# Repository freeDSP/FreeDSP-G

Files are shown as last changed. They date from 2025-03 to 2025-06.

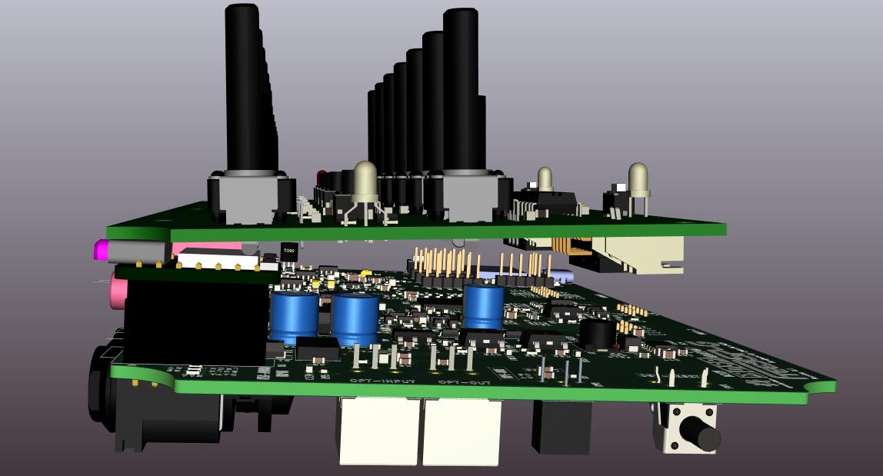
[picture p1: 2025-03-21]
kiCAD/FreeDSP-G_MAIN/Rendering/FreeDSP-G_Stacked_Left.jpg

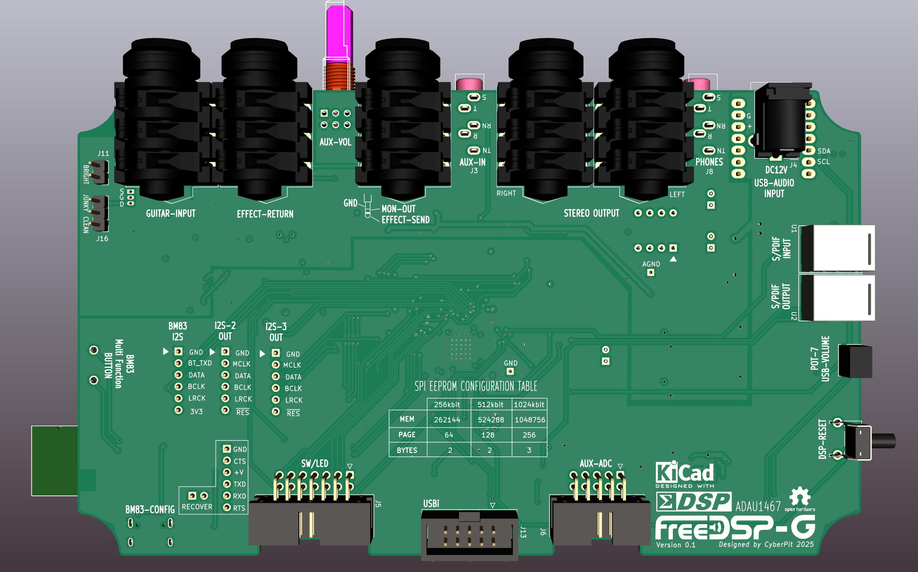
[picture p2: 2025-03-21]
kiCAD/FreeDSP-G_MAIN/Rendering/FreeDSP-G_BottomView.jpg

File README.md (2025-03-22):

# FreeDSP-G (ADAU1467 DSP BOARD)
Strip_PCB

ADAU1467 DSP Board for Electic Guitar Players. The latest version design is 0.2  

## Features  

### Tube Electric Guitar Amplifier Simulator
* A simple single DSP board concept
* 6.5mm Phone Jack I/O connector
* KARAOKE (Play-along) feature
* Effect loop function with plug insert detection feature
* Stereo Output
* Headphones output
* Switchable Dual 7 Potentiometer Controls
* Dual Color LED indicator x1
* Single Color LED x1
* 3 Momentary-ON Footswitches with LED indicator
* Optical S/PDIF Input and Output
* 3.5mm Stereo Analog signal Input with plug insert detection and rotary volume control feature.
* USB-C Audio Input (44.1kHZ/48kHz)
* Embedded BM83 Bluetooth Audio Interface (Option)
* BGM mix level control (POT-7)
* DSP reset button
* Selfboot disable jumper
* Brite(Hi-Boost) Jumper
* Triodizer Head Amplifier with bypass option
* USBi 10P IDC pin-Header with Shoruld

Wiki Page: https://github.com/freeDSP/FreeDSP-G/wiki

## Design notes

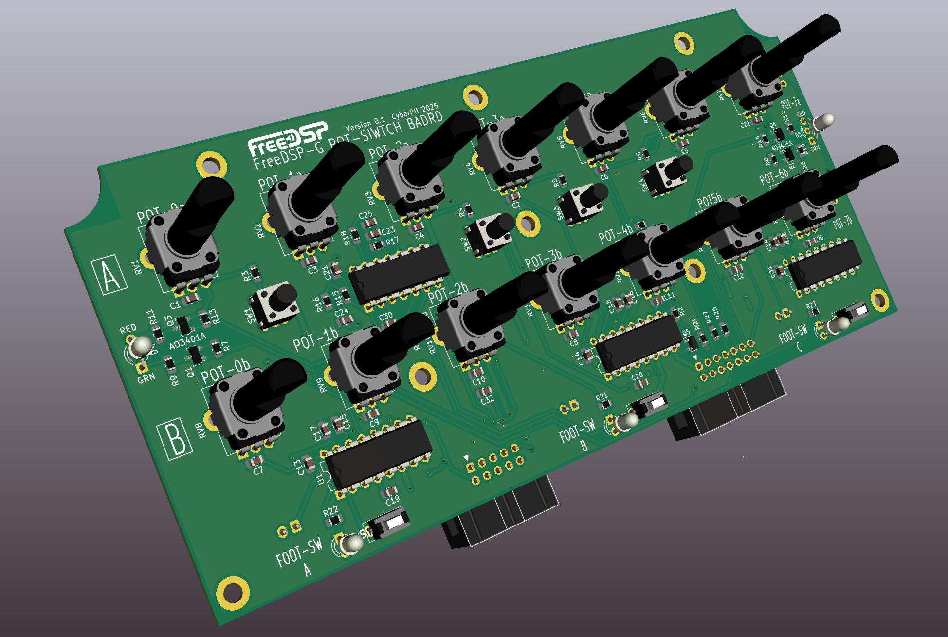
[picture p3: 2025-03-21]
kiCAD/FreeDSP-G_POT-SWITCH/3D-Rendering/POT_SWITCH.jpg

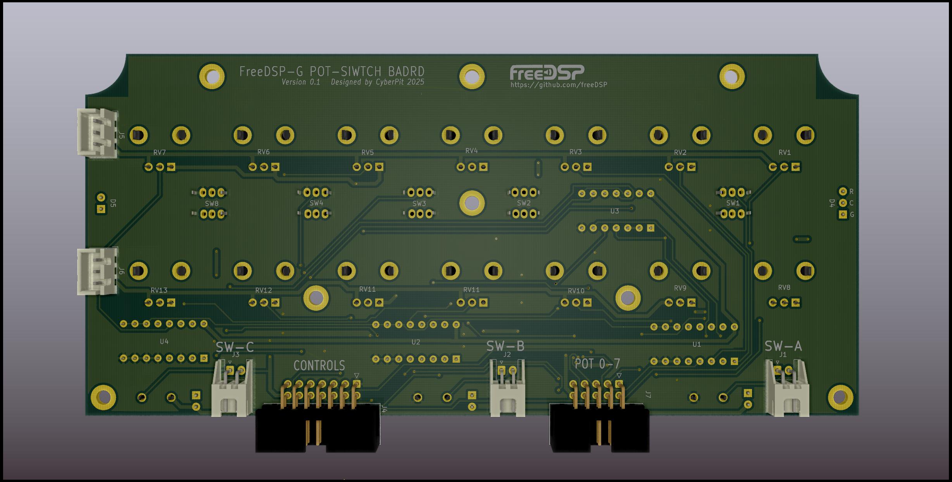
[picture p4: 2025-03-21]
kiCAD/FreeDSP-G_POT-SWITCH/3D-Rendering/POT_SWITCH_BottomView.jpg

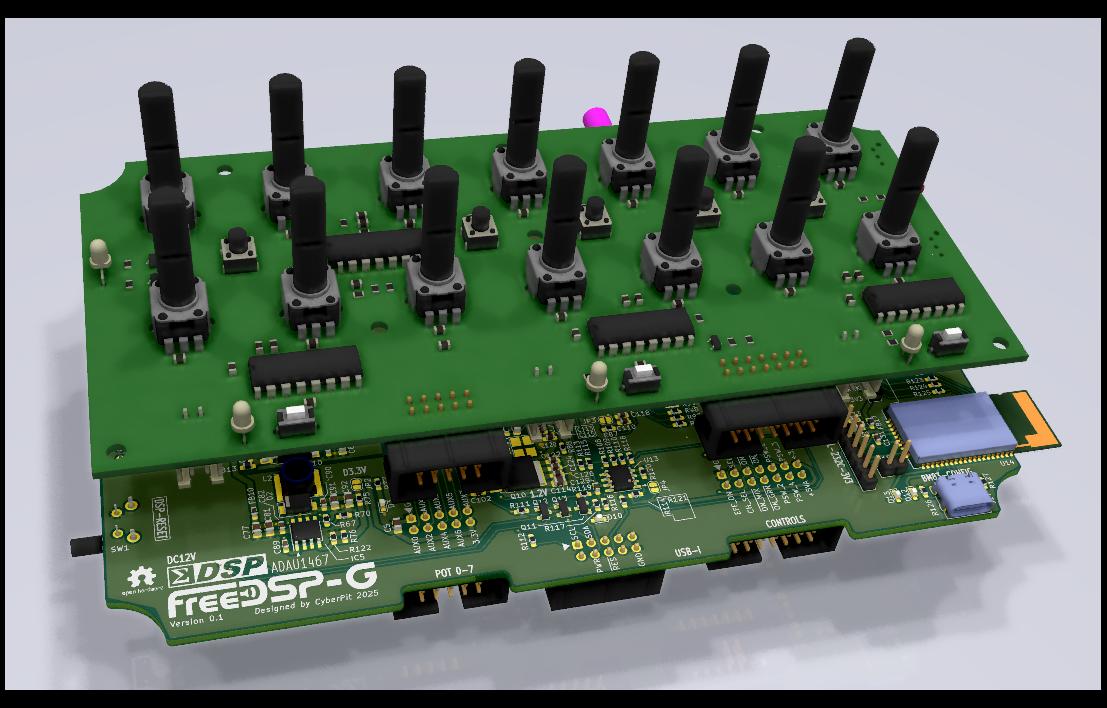
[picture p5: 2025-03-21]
kiCAD/FreeDSP-G_MAIN/Rendering/FreeDSP-G_Stacked_Image.jpg

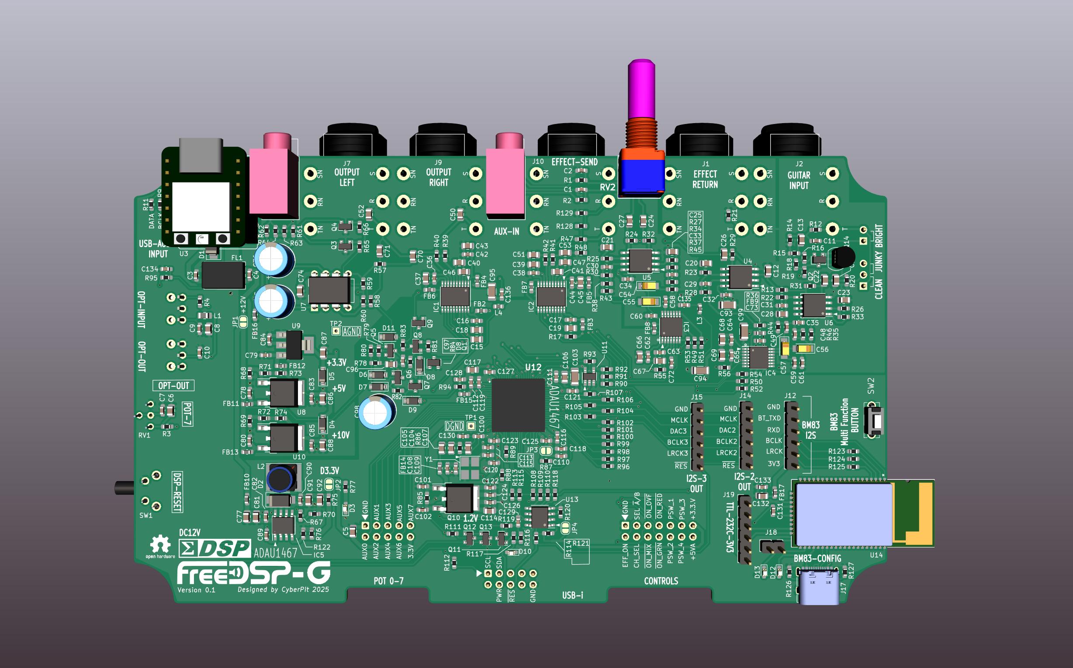
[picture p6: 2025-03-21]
kiCAD/FreeDSP-G_MAIN/Rendering/FreeDSP-G_MainTopView.jpg

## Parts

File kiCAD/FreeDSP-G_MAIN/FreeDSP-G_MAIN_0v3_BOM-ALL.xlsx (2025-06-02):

Reference | Value | Footprint | Description | JLPCB# | Manufacturer_Name | Manufacturer_Part_Number | Datasheet | Supplier_Name | Category | DK_Datasheet_Link | DK_Detail_Page | Digi-Key_PN | Family | MPN | Manufacturer | Status | Height | Allied Price/Stock | Allied_Number | Mouser Part Number | Mouser Price/Stock | RS Part Number | RS Price/Stock
C1 | 100pF_C0G | Capacitor_SMD:C_0603_1608Metric_Pad1.08x0.95mm_HandSolder | C0G or ECHU(FilmCap) Recommended | C14858 |  |  | ~
C10 | 0.1uF | Capacitor_SMD:C_0603_1608Metric_Pad1.08x0.95mm_HandSolder |  | C14663 |  |  | ~
C100 | 0.1uF | Capacitor_SMD:C_0603_1608Metric_Pad1.08x0.95mm_HandSolder |  | C14663 |  |  | ~
C101 | 100pF_C0G | Capacitor_SMD:C_0603_1608Metric_Pad1.08x0.95mm_HandSolder |  | C14858 |  |  | ~
C102 | 0.1uF | Capacitor_SMD:C_0603_1608Metric_Pad1.08x0.95mm_HandSolder |  | C14663 |  |  | ~
C103 | 100uF | Capacitor_SMD:C_1206_3216Metric |  | C15008 |  |  | ~
C104 | 1000pF/250V | Capacitor_SMD:C_0805_2012Metric | C0G PLL Loop FIlter Snabber Cap | C343010 |  |  | ~
C105 | 4700pF | Capacitor_SMD:C_0805_2012Metric | PLL Loop FIlter Cap (C0G will better) | C1744 |  |  | ~
C106 | 10uF | Capacitor_SMD:C_0805_2012Metric |  | C440198 |  |  | ~
C107 | 150pF | Capacitor_SMD:C_0805_2012Metric | PLL Loop FIlter Cap (C0G will better) | C1716 |  |  | ~
C108 | 10nF | Capacitor_SMD:C_0603_1608Metric_Pad1.08x0.95mm_HandSolder |  | C57112 |  |  | ~
C109 | 0.1uF | Capacitor_SMD:C_0603_1608Metric_Pad1.08x0.95mm_HandSolder |  | C14663 |  |  | ~
C11 | 470pF | Capacitor_SMD:C_0603_1608Metric_Pad1.08x0.95mm_HandSolder |  | C1620 |  |  | ~
C110 | 1uF | Capacitor_SMD:C_0603_1608Metric_Pad1.08x0.95mm_HandSolder |  | C15849 |  |  | ~
C111 | 0.1uF | Capacitor_SMD:C_0603_1608Metric_Pad1.08x0.95mm_HandSolder |  | C14663 |  |  | ~
C112 | 1uF | Capacitor_SMD:C_0603_1608Metric_Pad1.08x0.95mm_HandSolder |  | C15849 |  |  | ~
C113 | 0.1uF | Capacitor_SMD:C_0603_1608Metric_Pad1.08x0.95mm_HandSolder |  | C14663 |  |  | ~
C114 | 10uF | Capacitor_SMD:C_0805_2012Metric |  | C440198 |  |  | ~
C115 | 1uF | Capacitor_SMD:C_0603_1608Metric_Pad1.08x0.95mm_HandSolder |  | C15849 |  |  | ~
C116 | 0.1uF | Capacitor_SMD:C_0603_1608Metric_Pad1.08x0.95mm_HandSolder |  | C14663 |  |  | ~
C117 | 10uF | Capacitor_SMD:C_0805_2012Metric |  | C440198 |  |  | ~
C118 | 1uF | Capacitor_SMD:C_0603_1608Metric_Pad1.08x0.95mm_HandSolder |  | C15849
C119 | 0.1uF | Capacitor_SMD:C_0603_1608Metric_Pad1.08x0.95mm_HandSolder |  | C14663 |  |  | ~
C12 | 1uF | Capacitor_SMD:C_0805_2012Metric |  | C28323 |  |  | ~
C120 | 1uF | Capacitor_SMD:C_0603_1608Metric_Pad1.08x0.95mm_HandSolder |  | C15849 |  |  | ~
C121 | 0.1uF | Capacitor_SMD:C_0603_1608Metric_Pad1.08x0.95mm_HandSolder |  | C14663 |  |  | ~
C122 | 1uF | Capacitor_SMD:C_0603_1608Metric_Pad1.08x0.95mm_HandSolder |  | C15849 |  |  | ~
C123 | 0.1uF | Capacitor_SMD:C_0603_1608Metric_Pad1.08x0.95mm_HandSolder |  | C14663 |  |  | ~
C124 | 1uF | Capacitor_SMD:C_0603_1608Metric_Pad1.08x0.95mm_HandSolder |  | C15849 |  |  | ~
C125 | 0.1uF | Capacitor_SMD:C_0603_1608Metric_Pad1.08x0.95mm_HandSolder |  | C14663 |  |  | ~
C126 | 1uF | Capacitor_SMD:C_0603_1608Metric_Pad1.08x0.95mm_HandSolder |  | C15849 |  |  | ~
C127 | 0.1uF | Capacitor_SMD:C_0603_1608Metric_Pad1.08x0.95mm_HandSolder |  | C14663 |  |  | ~
C128 | 0.1uF | Capacitor_SMD:C_0603_1608Metric_Pad1.08x0.95mm_HandSolder |  | C14663
C129 | 0.1uF | Capacitor_SMD:C_0603_1608Metric_Pad1.08x0.95mm_HandSolder |  | C14663 |  |  | ~
C13 | 100nF | Capacitor_SMD:C_0805_2012Metric |  | C28233 |  |  | ~
C130 | 10nF | Capacitor_SMD:C_0603_1608Metric_Pad1.08x0.95mm_HandSolder |  | C57112 |  |  | ~
C131 | 0.1uF | Capacitor_SMD:C_0603_1608Metric_Pad1.08x0.95mm_HandSolder |  | C14663 |  |  | ~
C132 | 10uF | Capacitor_SMD:C_0805_2012Metric |  | C440198 |  |  | ~
C133 | 0.1uF | Capacitor_SMD:C_0603_1608Metric_Pad1.08x0.95mm_HandSolder |  | C14663 |  |  | ~
C134 | 0.1uF | Capacitor_SMD:C_0603_1608Metric_Pad1.08x0.95mm_HandSolder |  | C14663 |  |  | ~
C135 | 0.1uF | Capacitor_SMD:C_0603_1608Metric_Pad1.08x0.95mm_HandSolder |  | C14663 |  |  | ~
C136 | 0.1uF | Capacitor_SMD:C_0603_1608Metric_Pad1.08x0.95mm_HandSolder |  | C14663 |  |  | ~
C137 | 10uF | Capacitor_SMD:C_0805_2012Metric |  | C440198
C138 | 220uF/10V | Capacitor_THT:CP_Radial_D7.5mm_P2.50mm | Low ESR will better for headphones coupling | HAND |  |  | ~
C139 | 470uF/16V | Capacitor_THT:CP_Radial_D10.0mm_P2.50mm_P5.00mm | Low ESR will better for headphones coupling | HAND |  |  | ~
C14 | 10uF/16V | Capacitor_Tantalum_SMD:CP_EIA-2012-12_Kemet-R |  |  |  |  | ~
C15 | 10uF | Capacitor_SMD:C_0805_2012Metric |  | C440198
C16 | 0.1uF | Capacitor_SMD:C_0603_1608Metric_Pad1.08x0.95mm_HandSolder |  | C14663
C17 | 0.1uF | Capacitor_SMD:C_0603_1608Metric_Pad1.08x0.95mm_HandSolder |  | C14663
C18 | 10uF | Capacitor_SMD:C_0805_2012Metric |  | C440198
C19 | 10uF | Capacitor_SMD:C_0805_2012Metric |  | C440198
C2 | 100pF_C0G | Capacitor_SMD:C_0603_1608Metric_Pad1.08x0.95mm_HandSolder | C0G or ECHU(FilmCap) Recommended | C14858 |  |  | ~
C20 | 1uF | Capacitor_SMD:C_0805_2012Metric |  | C28323 |  |  | ~
C21 | 10uF | Capacitor_SMD:C_0805_2012Metric |  | C440198 |  |  | ~
C22 | 1uF | Capacitor_SMD:C_0805_2012Metric |  | C28323 |  |  | ~
C23 | NOP | Capacitor_SMD:C_0805_2012Metric | Not needed | - |  |  | ~
C24 | 1uF | Capacitor_SMD:C_0805_2012Metric |  | C28323 |  |  | ~
C25 | 10uF | Capacitor_SMD:C_0805_2012Metric |  | C440198 |  |  | ~
C26 | 1uF | Capacitor_SMD:C_0805_2012Metric |  | C28323 |  |  | ~
C27 | 1uF | Capacitor_SMD:C_0805_2012Metric |  | C28323 |  |  | ~
C28 | 10uF | Capacitor_SMD:C_0805_2012Metric |  | C440198 |  |  | ~
C29 | 100pF_C0G | Capacitor_SMD:C_0603_1608Metric_Pad1.08x0.95mm_HandSolder |  | C14858 |  |  | ~
C3 | 0.1uF | Capacitor_SMD:C_0603_1608Metric_Pad1.08x0.95mm_HandSolder |  | C14663 |  |  | ~
C30 | 100pF_C0G | Capacitor_SMD:C_0603_1608Metric_Pad1.08x0.95mm_HandSolder |  | C14858 |  |  | ~
C31 | 0.1uF | Capacitor_SMD:C_0603_1608Metric_Pad1.08x0.95mm_HandSolder |  | C14663
C32 | 0.1uF | Capacitor_SMD:C_0603_1608Metric_Pad1.08x0.95mm_HandSolder |  | C14663
C33 | 100pF_C0G | Capacitor_SMD:C_0603_1608Metric_Pad1.08x0.95mm_HandSolder |  | C14858 |  |  | ~
C34 | 0.1uF | Capacitor_SMD:C_0603_1608Metric_Pad1.08x0.95mm_HandSolder |  | C14663
C35 | 0.1uF | Capacitor_SMD:C_0603_1608Metric_Pad1.08x0.95mm_HandSolder |  | C14663
C36 | 0.1uF | Capacitor_SMD:C_0603_1608Metric_Pad1.08x0.95mm_HandSolder |  | C14663
C37 | 10uF | Capacitor_SMD:C_0805_2012Metric |  | C440198
C38 | 0.1uF | Capacitor_SMD:C_0603_1608Metric_Pad1.08x0.95mm_HandSolder |  | C14663
C39 | 10uF | Capacitor_SMD:C_0805_2012Metric |  | C440198
C4 | 0.1uF | Capacitor_SMD:C_0603_1608Metric_Pad1.08x0.95mm_HandSolder |  | C14663 |  |  | ~
C40 | 10uF | Capacitor_SMD:C_0805_2012Metric |  | C440198
C41 | 10uF | Capacitor_SMD:C_0805_2012Metric |  | C440198
C42 | 0.1uF | Capacitor_SMD:C_0603_1608Metric_Pad1.08x0.95mm_HandSolder |  | C14663
C43 | 10uF | Capacitor_SMD:C_0805_2012Metric |  | C440198
C44 | 0.1uF | Capacitor_SMD:C_0603_1608Metric_Pad1.08x0.95mm_HandSolder |  | C14663
C45 | 10uF | Capacitor_SMD:C_0805_2012Metric |  | C440198
C46 | 10uF | Capacitor_SMD:C_0805_2012Metric |  | C440198
C47 | 10uF | Capacitor_SMD:C_0805_2012Metric |  | C440198
C48 | 100pF_C0G | Capacitor_SMD:C_0603_1608Metric_Pad1.08x0.95mm_HandSolder | C0G or ECHU(FilmCap) Recommended | C14858 |  |  | ~
C49 | 100pF_C0G | Capacitor_SMD:C_0603_1608Metric_Pad1.08x0.95mm_HandSolder | C0G or ECHU(FilmCap) Recommended | C14858 |  |  | ~
C5 | 10uF | Capacitor_SMD:C_0805_2012Metric |  | C440198 |  |  | ~
C50 | 1000pF/250V | Capacitor_SMD:C_0805_2012Metric |  | C343010 |  |  | ~
C51 | 1000pF/250V | Capacitor_SMD:C_0805_2012Metric |  | C343010 |  |  | ~
C52 | 1000pF/250V | Capacitor_SMD:C_0805_2012Metric |  | C343010 |  |  | ~
C53 | 1000pF/250V | Capacitor_SMD:C_0805_2012Metric |  | C343010 |  |  | ~
C54 | 10uF/16V(Ta) | Capacitors_Tantalum_SMD:CP_Tantalum_Case-A_EIA-3216-18_Reflow | Tanatalium 3216 metric | C7171
C55 | 10uF/16V(Ta) | Capacitors_Tantalum_SMD:CP_Tantalum_Case-A_EIA-3216-18_Reflow | Tanatalium 3216 metric | C7171
C56 | 10uF/16V(Ta) | Capacitors_Tantalum_SMD:CP_Tantalum_Case-A_EIA-3216-18_Reflow | Tanatalium 3216 metric | C7171
C57 | 10uF/16V(Ta) | Capacitors_Tantalum_SMD:CP_Tantalum_Case-A_EIA-3216-18_Reflow | Tanatalium 3216 metric | C7171
C58 | 100pF_C0G | Capacitor_SMD:C_0603_1608Metric_Pad1.08x0.95mm_HandSolder | C0G or ECHU(FilmCap) Recommended | C14858
C59 | 100pF_C0G | Capacitor_SMD:C_0603_1608Metric_Pad1.08x0.95mm_HandSolder | C0G or ECHU(FilmCap) Recommended | C14858
C6 | 10uF | Capacitor_SMD:C_0805_2012Metric |  | C440198
C60 | 100pF_C0G | Capacitor_SMD:C_0603_1608Metric_Pad1.08x0.95mm_HandSolder | C0G or ECHU(FilmCap) Recommended | C14858
C61 | 100pF_C0G | Capacitor_SMD:C_0603_1608Metric_Pad1.08x0.95mm_HandSolder | C0G or ECHU(FilmCap) Recommended | C14858
C62 | 0.1uF | Capacitor_SMD:C_0603_1608Metric_Pad1.08x0.95mm_HandSolder |  | C14663
C63 | 0.1uF | Capacitor_SMD:C_0603_1608Metric_Pad1.08x0.95mm_HandSolder |  | C14663
C64 | 0.1uF | Capacitor_SMD:C_0603_1608Metric_Pad1.08x0.95mm_HandSolder |  | C14663
C65 | 0.1uF | Capacitor_SMD:C_0603_1608Metric_Pad1.08x0.95mm_HandSolder |  | C14663
C66 | 10uF | Capacitor_SMD:C_0805_2012Metric |  | C440198
C67 | 10uF | Capacitor_SMD:C_0805_2012Metric |  | C440198
C68 | 10uF | Capacitor_SMD:C_0805_2012Metric |  | C440198
C69 | 10uF | Capacitor_SMD:C_0805_2012Metric |  | C440198
C7 | 0.1uF | Capacitor_SMD:C_0603_1608Metric_Pad1.08x0.95mm_HandSolder |  | C14663 |  |  | ~
C70 | 10uF | Capacitor_SMD:C_0805_2012Metric |  | C440198
C71 | 10uF | Capacitor_SMD:C_0805_2012Metric |  | C440198
C72 | 0.1uF | Capacitor_SMD:C_0603_1608Metric_Pad1.08x0.95mm_HandSolder |  | C14663
C73 | 0.1uF | Capacitor_SMD:C_0603_1608Metric_Pad1.08x0.95mm_HandSolder |  | C14663
C74 | 10uF | Capacitor_SMD:C_0805_2012Metric |  | C440198
C75 | 220uF/10V | Capacitor_THT:CP_Radial_D7.5mm_P2.50mm | Low ESR will better for headphones coupling | HAND |  |  | ~
C76 | 220uF/10V | Capacitor_THT:CP_Radial_D7.5mm_P2.50mm | Low ESR will better for headphones coupling | HAND |  |  | ~
C77 | 10uF/50V | Capacitor_SMD:C_0805_2012Metric |  | C440198 |  |  | ~
C78 | 0.1uF | Capacitor_SMD:C_0603_1608Metric_Pad1.08x0.95mm_HandSolder |  | C14663 |  |  | ~
C79 | 0.1uF | Capacitor_SMD:C_0603_1608Metric_Pad1.08x0.95mm_HandSolder |  | C14663 |  |  | ~
C8 | 10uF | Capacitor_SMD:C_0805_2012Metric |  | C440198 |  |  | ~
C80 | 0.1uF | Capacitor_SMD:C_0603_1608Metric_Pad1.08x0.95mm_HandSolder |  | C14663 |  |  | ~
C81 | 1uF/50V | Capacitor_SMD:C_0805_2012Metric |  | C28323 |  |  | ~
C82 | 0.1uF | Capacitor_SMD:C_0603_1608Metric_Pad1.08x0.95mm_HandSolder |  | C14663 |  |  | ~
C83 | 0.1uF | Capacitor_SMD:C_0603_1608Metric_Pad1.08x0.95mm_HandSolder |  | C14663 |  |  | ~
C84 | 0.1uF | Capacitor_SMD:C_0603_1608Metric_Pad1.08x0.95mm_HandSolder |  | C14663 |  |  | ~
C85 | 0.1uF | Capacitor_SMD:C_0603_1608Metric_Pad1.08x0.95mm_HandSolder |  | C14663 |  |  | ~
C86 | 1uF | Capacitor_SMD:C_0805_2012Metric |  | C28323 |  |  | ~
C87 | 1uF | Capacitor_SMD:C_0805_2012Metric |  | C28323 |  |  | ~
C88 | 1uF | Capacitor_SMD:C_0805_2012Metric |  | C28323 |  |  | ~
C89 | 0.1uF | Capacitor_SMD:C_0603_1608Metric_Pad1.08x0.95mm_HandSolder |  | C14663 |  |  | ~
C9 | 0.1uF | Capacitor_SMD:C_0603_1608Metric_Pad1.08x0.95mm_HandSolder |  | C14663 |  |  | ~
C90 | 0.1uF | Capacitor_SMD:C_0603_1608Metric_Pad1.08x0.95mm_HandSolder |  | C14663 |  |  | ~
C91 | 47uF/6.3V | Capacitor_SMD:C_0805_2012Metric | for Negative SMPS Power Integration | C16780 |  |  | ~
C92 | 47uF/6.3V | Capacitor_SMD:C_0805_2012Metric |  | C16780 |  |  | ~
C93 | 47uF/10V | Capacitor_SMD:C_1206_3216Metric |  | C96123 |  |  | ~
C94 | 100uF/6.3V | Capacitor_SMD:C_1206_3216Metric |  | C15008 |  |  | ~
C95 | 100uF/6.3V | Capacitor_SMD:C_1206_3216Metric |  | C15008 |  |  | ~
C96 | 10uF/50V | Capacitor_SMD:C_0805_2012Metric | for the Power-ON delay timing | C440198 |  |  | ~
C97 | 0.1uF | Capacitor_SMD:C_0603_1608Metric_Pad1.08x0.95mm_HandSolder |  | C14663 |  |  | ~
C98 | 220uF/16V | Capacitor_THT:CP_Radial_D7.5mm_P2.50mm | for the Power-OFF muting power reserver | HAND |  |  | ~
C99 | 100uF | Capacitor_SMD:C_1206_3216Metric |  | C15008 |  |  | ~
D1 | D_Schottky_5A | Diode_SMD:D_SMA | SBD 40V 550mV@5A | C22452 |  |  | ~
D10 | LED_YELLOW | LED_SMD:LED_0603_1608Metric_Castellated | Indicator for USBi is Active | C72038
D11 | B5819W SL | Diode_SMD:D_SOD-123 | SBD 1A/40V | C8598 |  |  | http://www.vishay.com/docs/85660/bat42.pdf
D12 | LED_WHITE | LED_SMD:LED_0603_1608Metric_Castellated | Remove this if you use LED extension header | C2290
D13 | LED_RED | LED_SMD:LED_0603_1608Metric_Castellated | Remove this if you use LED extension header | C2286
D14 | B5819W SL | Diode_SMD:D_SOD-123 | SBD 1A/40V | C8598 |  |  | http://www.vishay.com/docs/85660/bat42.pdf
D15 | B5819W SL | Diode_SMD:D_SOD-123 | SBD 1A/40V | C8598 |  |  | http://www.vishay.com/docs/85660/bat42.pdf
D2 | D_Schottky_5A | Diode_SMD:D_SMA | SBD 40V 550mV@5A | C22452 |  |  | ~
D3 | LED_WHITE | LED_SMD:LED_0603_1608Metric_Castellated | Remove this if you use LED extension header | C2290
D4 | B5819W SL | Diode_SMD:D_SOD-123 | SBD 1A/40V | C8598 |  |  | http://www.vishay.com/docs/85660/bat42.pdf
D5 | B5819W SL | Diode_SMD:D_SOD-123 | SBD 1A/40V | C8598 |  |  | http://www.vishay.com/docs/85660/bat42.pdf
D6 | 1N4148W | Diode_SMD:D_SOD-123 | Switching Diode 150mA/75V | C81598 |  |  | ~
D7 | B5819W SL | Diode_SMD:D_SOD-123 | SBD 1A/40V | C8598 |  |  | http://www.vishay.com/docs/85660/bat42.pdf
D8 | B5819W SL | Diode_SMD:D_SOD-123 | SBD 1A/40V | C8598 |  |  | http://www.vishay.com/docs/85660/bat42.pdf
D9 | B5819W SL | Diode_SMD:D_SOD-123 | SBD 1A/40V | C8598 |  |  | http://www.vishay.com/docs/85660/bat42.pdf
FB1 | GZ1608D601TF | Inductor_SMD:L_0603_1608Metric_Pad1.05x0.95mm_HandSolder | FERRITE BEAD 600 OHM 0603 1LN | C1002 |  |  | https://www.murata.com/en-us/products/productdata/8796738650142/ENFA0003.pdf |  | Filters | https://www.murata.com/en-us/products/productdata/8796738650142/ENFA0003.pdf | /product-detail/en/murata-electronics-north-america/BLM18AG601SN1D/490-1014-1-ND/584462 | 490-1014-1-ND | Ferrite Beads and Chips | BLM18AG601SN1D | Murata Electronics North America | Active
FB10 | GZ1608D601TF | Inductor_SMD:L_0603_1608Metric_Pad1.05x0.95mm_HandSolder | FERRITE BEAD 600 OHM 0603 1LN | C1002 |  |  | https://www.murata.com/en-us/products/productdata/8796738650142/ENFA0003.pdf |  | Filters | https://www.murata.com/en-us/products/productdata/8796738650142/ENFA0003.pdf | /product-detail/en/murata-electronics-north-america/BLM18AG601SN1D/490-1014-1-ND/584462 | 490-1014-1-ND | Ferrite Beads and Chips | BLM18AG601SN1D | Murata Electronics North America | Active
FB11 | GZ1608D601TF | Inductor_SMD:L_0603_1608Metric_Pad1.05x0.95mm_HandSolder | FERRITE BEAD 600 OHM 0603 1LN | C1002 |  |  | https://www.murata.com/en-us/products/productdata/8796738650142/ENFA0003.pdf |  | Filters | https://www.murata.com/en-us/products/productdata/8796738650142/ENFA0003.pdf | /product-detail/en/murata-electronics-north-america/BLM18AG601SN1D/490-1014-1-ND/584462 | 490-1014-1-ND | Ferrite Beads and Chips | BLM18AG601SN1D | Murata Electronics North America | Active
FB12 | GZ1608D601TF | Inductor_SMD:L_0603_1608Metric_Pad1.05x0.95mm_HandSolder | FERRITE BEAD 600 OHM 0603 1LN | C1002 |  |  | https://www.murata.com/en-us/products/productdata/8796738650142/ENFA0003.pdf |  | Filters | https://www.murata.com/en-us/products/productdata/8796738650142/ENFA0003.pdf | /product-detail/en/murata-electronics-north-america/BLM18AG601SN1D/490-1014-1-ND/584462 | 490-1014-1-ND | Ferrite Beads and Chips | BLM18AG601SN1D | Murata Electronics North America | Active
FB13 | GZ1608D601TF | Inductor_SMD:L_0603_1608Metric_Pad1.05x0.95mm_HandSolder | FERRITE BEAD 600 OHM 0603 1LN | C1002 |  |  | https://www.murata.com/en-us/products/productdata/8796738650142/ENFA0003.pdf |  | Filters | https://www.murata.com/en-us/products/productdata/8796738650142/ENFA0003.pdf | /product-detail/en/murata-electronics-north-america/BLM18AG601SN1D/490-1014-1-ND/584462 | 490-1014-1-ND | Ferrite Beads and Chips | BLM18AG601SN1D | Murata Electronics North America | Active
FB14 | GZ1608D601TF | Inductor_SMD:L_0603_1608Metric_Pad1.05x0.95mm_HandSolder | FERRITE BEAD 600 OHM 0603 1LN | C1002 |  |  | https://www.murata.com/en-us/products/productdata/8796738650142/ENFA0003.pdf |  | Filters | https://www.murata.com/en-us/products/productdata/8796738650142/ENFA0003.pdf | /product-detail/en/murata-electronics-north-america/BLM18AG601SN1D/490-1014-1-ND/584462 | 490-1014-1-ND | Ferrite Beads and Chips | BLM18AG601SN1D | Murata Electronics North America | Active
FB15 | GZ1608D601TF | Inductor_SMD:L_0603_1608Metric_Pad1.05x0.95mm_HandSolder | FERRITE BEAD 600 OHM 0603 1LN | C1002 |  |  | https://www.murata.com/en-us/products/productdata/8796738650142/ENFA0003.pdf |  | Filters | https://www.murata.com/en-us/products/productdata/8796738650142/ENFA0003.pdf | /product-detail/en/murata-electronics-north-america/BLM18AG601SN1D/490-1014-1-ND/584462 | 490-1014-1-ND | Ferrite Beads and Chips | BLM18AG601SN1D | Murata Electronics North America | Active
FB16 | GZ1608D601TF | Inductor_SMD:L_0603_1608Metric_Pad1.05x0.95mm_HandSolder | FERRITE BEAD 600 OHM 0603 1LN | C1002 |  |  | https://www.murata.com/en-us/products/productdata/8796738977822/ENFA0005.pdf |  | Filters | https://www.murata.com/en-us/products/productdata/8796738977822/ENFA0005.pdf | /product-detail/en/murata-electronics-north-america/BLM21PG331SN1D/490-5988-1-ND/3845188 | 490-5988-1-ND | Ferrite Beads and Chips | BLM21PG331SN1D | Murata Electronics North America | Active
FB17 | GZ1608D601TF | Inductor_SMD:L_0603_1608Metric_Pad1.05x0.95mm_HandSolder | FERRITE BEAD 600 OHM 0603 1LN | C1002 |  |  | https://www.murata.com/en-us/products/productdata/8796738650142/ENFA0003.pdf |  | Filters | https://www.murata.com/en-us/products/productdata/8796738650142/ENFA0003.pdf | /product-detail/en/murata-electronics-north-america/BLM18AG601SN1D/490-1014-1-ND/584462 | 490-1014-1-ND | Ferrite Beads and Chips | BLM18AG601SN1D | Murata Electronics North America | Active
FB18 | GZ1608D601TF | Inductor_SMD:L_0603_1608Metric_Pad1.05x0.95mm_HandSolder | FERRITE BEAD 600 OHM 0603 1LN | C1002 |  |  | https://www.murata.com/en-us/products/productdata/8796738650142/ENFA0003.pdf |  | Filters | https://www.murata.com/en-us/products/productdata/8796738650142/ENFA0003.pdf | /product-detail/en/murata-electronics-north-america/BLM18AG601SN1D/490-1014-1-ND/584462 | 490-1014-1-ND | Ferrite Beads and Chips | BLM18AG601SN1D | Murata Electronics North America | Active
FB2 | GZ1608D601TF | Inductor_SMD:L_0603_1608Metric_Pad1.05x0.95mm_HandSolder | FERRITE BEAD 600 OHM 0603 1LN | C1002 |  |  | https://www.murata.com/en-us/products/productdata/8796738650142/ENFA0003.pdf |  | Filters | https://www.murata.com/en-us/products/productdata/8796738650142/ENFA0003.pdf | /product-detail/en/murata-electronics-north-america/BLM18AG601SN1D/490-1014-1-ND/584462 | 490-1014-1-ND | Ferrite Beads and Chips | BLM18AG601SN1D | Murata Electronics North America | Active
FB3 | GZ1608D601TF | Inductor_SMD:L_0603_1608Metric_Pad1.05x0.95mm_HandSolder | FERRITE BEAD 600 OHM 0603 1LN | C1002 |  |  | https://www.murata.com/en-us/products/productdata/8796738650142/ENFA0003.pdf |  | Filters | https://www.murata.com/en-us/products/productdata/8796738650142/ENFA0003.pdf | /product-detail/en/murata-electronics-north-america/BLM18AG601SN1D/490-1014-1-ND/584462 | 490-1014-1-ND | Ferrite Beads and Chips | BLM18AG601SN1D | Murata Electronics North America | Active
FB4 | GZ1608D601TF | Inductor_SMD:L_0603_1608Metric_Pad1.05x0.95mm_HandSolder | FERRITE BEAD 600 OHM 0603 1LN | C1002 |  |  | https://www.murata.com/en-us/products/productdata/8796738650142/ENFA0003.pdf |  | Filters | https://www.murata.com/en-us/products/productdata/8796738650142/ENFA0003.pdf | /product-detail/en/murata-electronics-north-america/BLM18AG601SN1D/490-1014-1-ND/584462 | 490-1014-1-ND | Ferrite Beads and Chips | BLM18AG601SN1D | Murata Electronics North America | Active
FB5 | GZ1608D601TF | Inductor_SMD:L_0603_1608Metric_Pad1.05x0.95mm_HandSolder | FERRITE BEAD 600 OHM 0603 1LN | C1002 |  |  | https://www.murata.com/en-us/products/productdata/8796738650142/ENFA0003.pdf |  | Filters | https://www.murata.com/en-us/products/productdata/8796738650142/ENFA0003.pdf | /product-detail/en/murata-electronics-north-america/BLM18AG601SN1D/490-1014-1-ND/584462 | 490-1014-1-ND | Ferrite Beads and Chips | BLM18AG601SN1D | Murata Electronics North America | Active
FB6 | GZ1608D601TF | Inductor_SMD:L_0603_1608Metric_Pad1.05x0.95mm_HandSolder | FERRITE BEAD 600 OHM 0603 1LN | C1002 |  |  | https://www.murata.com/en-us/products/productdata/8796738977822/ENFA0005.pdf |  | Filters | https://www.murata.com/en-us/products/productdata/8796738977822/ENFA0005.pdf | /product-detail/en/murata-electronics-north-america/BLM21PG331SN1D/490-5988-1-ND/3845188 | 490-5988-1-ND | Ferrite Beads and Chips | BLM21PG331SN1D | Murata Electronics North America | Active
FB7 | GZ1608D601TF | Inductor_SMD:L_0603_1608Metric_Pad1.05x0.95mm_HandSolder | FERRITE BEAD 600 OHM 0603 1LN | C1002 |  |  | https://www.murata.com/en-us/products/productdata/8796738977822/ENFA0005.pdf |  | Filters | https://www.murata.com/en-us/products/productdata/8796738977822/ENFA0005.pdf | /product-detail/en/murata-electronics-north-america/BLM21PG331SN1D/490-5988-1-ND/3845188 | 490-5988-1-ND | Ferrite Beads and Chips | BLM21PG331SN1D | Murata Electronics North America | Active
FB8 | GZ1608D601TF | Inductor_SMD:L_0603_1608Metric_Pad1.05x0.95mm_HandSolder | FERRITE BEAD 600 OHM 0603 1LN | C1002 |  |  | https://www.murata.com/en-us/products/productdata/8796738977822/ENFA0005.pdf |  | Filters | https://www.murata.com/en-us/products/productdata/8796738977822/ENFA0005.pdf | /product-detail/en/murata-electronics-north-america/BLM21PG331SN1D/490-5988-1-ND/3845188 | 490-5988-1-ND | Ferrite Beads and Chips | BLM21PG331SN1D | Murata Electronics North America | Active
FB9 | GZ1608D601TF | Inductor_SMD:L_0603_1608Metric_Pad1.05x0.95mm_HandSolder | FERRITE BEAD 600 OHM 0603 1LN | C1002 |  |  | https://www.murata.com/en-us/products/productdata/8796738977822/ENFA0005.pdf |  | Filters | https://www.murata.com/en-us/products/productdata/8796738977822/ENFA0005.pdf | /product-detail/en/murata-electronics-north-america/BLM21PG331SN1D/490-5988-1-ND/3845188 | 490-5988-1-ND | Ferrite Beads and Chips | BLM21PG331SN1D | Murata Electronics North America | Active
FL1 | MACM9070-701 | Myfootprints:ACM9070 | TDK - ACM9070-701-2PL-TL01 - FILTER, COMMON MODE, 5A, SMD | C2981417 | TDK | ACM9070-701-2PL-TL01 | http://www.mouser.com/ds/2/400/e9713_acm-16715.pdf | RS
IC1 | PCM5102APWR | Package_SO:TSSOP-20_4.4x6.5mm_P0.65mm | 2VRMS, 112dB Stereo DAC with 32-bit, 384kHz I2S Interface | C107671 | Texas Instruments | PCM5102APWR | https://componentsearchengine.com/Datasheets/2/PCM5102APWR.pdf | RS |  |  |  |  |  |  |  |  | 1.2
IC2 | PCM5102APWR | Package_SO:TSSOP-20_4.4x6.5mm_P0.65mm | 2VRMS, 112dB Stereo DAC with 32-bit, 384kHz I2S Interface | C107671 | Texas Instruments | PCM5102APWR | https://componentsearchengine.com/Datasheets/2/PCM5102APWR.pdf | RS |  |  |  |  |  |  |  |  | 1.2
IC3 | PCM1808QPWR | Myfootprints:PCM1808QPWRQ1 | ADC 99dB SNR @48kHz Sampling | C55513 | Texas Instruments | PCM1808QPWRQ1 | http://www.ti.com/lit/ds/symlink/pcm1808-q1.pdf | RS |  |  |  |  |  |  |  |  | 1.2
IC4 | PCM1808QPWR | Myfootprints:PCM1808QPWRQ1 | ADC 99dB SNR @48kHz Sampling | C55513 | Texas Instruments | PCM1808QPWRQ1 | http://www.ti.com/lit/ds/symlink/pcm1808-q1.pdf | RS |  |  |  |  |  |  |  |  | 1.2
IC5 | TPS5430DDA | Package_SO:TI_SO-PowerPAD-8_ThermalVias | SMPS for digital part | C9864 |  |  | http://www.ti.com/lit/ds/symlink/tps5430.pdf
J1 | NMJ6HCD2 | MyJacks:PJ-644C_NMJ6HCD2_ACJS-IH | 6,5mm TRS Jack with SW | HAND |  |  | ~
J10 | NMJ6HCD2 | MyJacks:PJ-644C_NMJ6HCD2_ACJS-IH | 6,5mm TRS Jack with SW | HAND |  |  | ~
J11 | Header_2P | Connector_PinHeader_2.54mm:PinHeader_1x02_P2.54mm_Vertical | Jumper pin-post 2P | HAND |  |  | ~
J12 | Conn_01x08 | Connector_PinHeader_2.54mm:PinHeader_1x06_P2.54mm_Vertical | for Optinal Extension of POTs | NOP |  |  | ~
J13 | IDC_2x5 | Connector_IDC:IDC-Header_2x05_P2.54mm_Vertical | Angled 10pin IDC header for USBi | HAND
J14 | Conn_01x08 | Connector_PinHeader_2.54mm:PinHeader_1x06_P2.54mm_Vertical | for Optinal Extension of POTs | NOP |  |  | ~
J15 | Conn_01x08 | Connector_PinHeader_2.54mm:PinHeader_1x06_P2.54mm_Vertical | for Optinal Extension of POTs | NOP |  |  | ~
J16 | Header_3P | Connector_PinHeader_2.54mm:PinHeader_1x03_P2.54mm_Vertical | Jumper pin-post 2P | HAND |  |  | ~
J17 | 5077CR-16-SMC2 | MyJacks:USB-C_5077CR-16-SMC2-BK-TR |  | HAND |  |  | https://www.usb.org/sites/default/files/documents/usb_type-c.zip
J18 | Header_2P | Connector_PinHeader_2.54mm:PinHeader_1x02_P2.54mm_Vertical |  | HAND |  |  | ~
J19 | Header_6P | Connector_PinHeader_2.54mm:PinHeader_1x06_P2.54mm_Vertical |  | HAND |  |  | ~
J2 | NMJ6HCD2 | MyJacks:PJ-644C_NMJ6HCD2_ACJS-IH | 6,5mm TRS Jack with SW | HAND |  |  | ~
J3 | TRS-mini | Connector_Audio:Jack_3.5mm_CUI_SJ1-3535NG_Horizontal | CUI SJ1-3535NG or MARUSHIN MJ354WSG | HAND |  |  | ~
J4 | Barrel_Jack_Switch | Connector_BarrelJack:BarrelJack_CUI_PJ-102AH_Horizontal | CUI PJ-102AH Center 2.1mm Sleeve 5.5mm | HAND |  |  | ~
J5 | Conn_02x07_Odd_Even | Connector_IDC:IDC-Header_2x07_P2.54mm_Horizontal | Angle IDC 2x7 Header with SH | HAND |  |  | ~
J6 | Conn_02x05_Odd_Even | Connector_IDC:IDC-Header_2x05_P2.54mm_Horizontal | Angle IDC 2x5 Header with SH | HAND |  |  | ~
J7 | NMJ6HCD2 | MyJacks:PJ-644C_NMJ6HCD2_ACJS-IH | 6,5mm TRS Jack with SW | HAND |  |  | ~
J8 | SJ1-3535NG | Connector_Audio:Jack_3.5mm_CUI_SJ1-3535NG_Horizontal | 3,5mm TRS Jack with SW | HAND |  |  | ~
J9 | NMJ6HCD2 | MyJacks:PJ-644C_NMJ6HCD2_ACJS-IH | 6,5mm TRS Jack with SW | HAND |  |  | ~
JP1 | SolderJumper_3_Bridged12 | Jumper:SolderJumper-2_P1.3mm_Bridged_RoundedPad1.0x1.5mm |  | - |  |  | ~
JP2 | SolderJumper_3_Bridged12 | Jumper:SolderJumper-2_P1.3mm_Bridged_RoundedPad1.0x1.5mm |  | - |  |  | ~
JP3 | Jumper_NO | Connector_PinHeader_2.54mm:PinHeader_1x02_P2.54mm_Vertical | Prevent Selfboot if shorted | - |  |  | ~
JP4 | Jumper_NC | Jumper:SolderJumper-2_P1.3mm_Bridged_RoundedPad1.0x1.5mm | Cut for 96kHz A/D Convertion | - |  |  | ~
L1 | SDFL2012S100KTF | Inductor_SMD:L_0805_2012Metric_Pad1.15x1.40mm_HandSolder | FIXED IND 10uH 15MA 1.15 OHM | C1046 |  |  | https://www.murata-ps.com/data/magnetics/kmp_8200c.pdf |  | Inductors, Coils, Chokes | https://www.murata-ps.com/data/magnetics/kmp_8200c.pdf | /product-detail/en/murata-power-solutions-inc/82473C/811-2477-1-ND/3178548 | 811-2477-1-ND | Fixed Inductors | 82473C | Sunlord | Active
L2 | 22uH(2.5A) | Inductor_SMD:L_Taiyo-Yuden_NR-60xx_HandSoldering | Metal-Alloy Power Inductor Rated 2.5A 7x6.6mm | C177244
L3 | SMD-INDUCTOR-10UH-0603 | Inductor_SMD:L_0603_1608Metric | 10uH SMD 0603 Inductor | C1035 |  |  |  |  |  |  |  |  |  | SDFL1608S100KTF
L4 | SMD-INDUCTOR-10UH-0603 | Inductor_SMD:L_0603_1608Metric | 10uH SMD 0603 Inductor | C1035 |  |  |  |  |  |  |  |  |  | SDFL1608S100KTF
LOGO1 | Logo_Open_Hardware_Small | LogoLibrary:LOGO_FREEDSP_600dpi |  | - |  |  | ~
Q1 | AO3400A | TO_SOT_Packages_SMD:SOT-23 | N Ch MOSFET | C20917 |  |  | https://www.fairchildsemi.com/datasheets/2N/2N7002.pdf
Q10 | B772M | Package_TO_SOT_SMD:TO-252-2 | PNP 1.25W 3A Transistor for 1.2V Power Rail | C33027 |  |  | ~
Q11 | AO3401A | Package_TO_SOT_SMD:SOT-23 | P-CHANNEL ENHANCEMENT MODE MOSFET | C15127 | Diodes Inc. | DMG3415U-7 | http://docs-emea.rs-online.com/webdocs/104e/0900766b8104e4f0.pdf |  |  |  |  |  |  |  |  |  | 1 | http://www.alliedelec.com/diodes-inc-dmg3415u-7/70438036/ | 70438036 | 621-DMG3415U-7 | https://www.mouser.com/Search/Refine.aspx?Keyword=621-DMG3415U-7 | 7514095P | http://uk.rs-online.com/web/p/products/7514095P
Q12 | AO3400A | Package_TO_SOT_SMD:SOT-23 | MOSFET N-CH 60V 115MA SOT-23 | C20917 |  |  | https://www.fairchildsemi.com/datasheets/2N/2N7002.pdf
Q13 | AO3400A | Package_TO_SOT_SMD:SOT-23 | MOSFET N-CH 60V 115MA SOT-23 | C20917 |  |  | https://www.fairchildsemi.com/datasheets/2N/2N7002.pdf
Q14 | 2SK30A-GR | TO_SOT_Packages_THT:TO-92_Inline_Narrow_Oval | Replace of 2SK30A | C2999170 |  |  | ~
Q2 | 2SK208GR | TO_SOT_Packages_SMD:SC-59 | Replace of 2SK30A | C2999170 |  |  | ~
Q3 | 2SD2704KT146 | Package_TO_SOT_SMD:SOT-23 | NPN Transistor for anti-pop muting | C79973 |  |  | ~
Q4 | 2SD2704KT146 | Package_TO_SOT_SMD:SOT-23 | NPN Transistor for anti-pop muting | C79973 |  |  | ~
Q5 | MMBT5401 | Package_TO_SOT_SMD:SOT-23 | PNP Transistor 350mW | C8326 |  |  | ~
Q6 | MMBT5401 | Package_TO_SOT_SMD:SOT-23 | PNP Transistor 350mW | C8326 |  |  | ~
Q8 | AO3401A | Package_TO_SOT_SMD:SOT-23 | P-CHANNEL ENHANCEMENT MODE MOSFET | C15127 | Diodes Inc. | DMG3415U-7 | http://docs-emea.rs-online.com/webdocs/104e/0900766b8104e4f0.pdf |  |  |  |  |  |  |  |  |  | 1 | http://www.alliedelec.com/diodes-inc-dmg3415u-7/70438036/ | 70438036 | 621-DMG3415U-7 | https://www.mouser.com/Search/Refine.aspx?Keyword=621-DMG3415U-7 | 7514095P | http://uk.rs-online.com/web/p/products/7514095P
Q9 | AO3400A | Package_TO_SOT_SMD:SOT-23 | MOSFET N-CH 60V 115MA SOT-23 | C20917 |  |  | https://www.onsemi.com/pub/Collateral/NDS7002A-D.PDF |  | Discrete Semiconductor Products | https://www.onsemi.com/pub/Collateral/NDS7002A-D.PDF | /product-detail/en/on-semiconductor/2N7002/2N7002NCT-ND/244664 | 2N7002NCT-ND | Transistors - FETs, MOSFETs - Single | 2N7002 | ON Semiconductor | Active
R1 | 18k | Resistor_SMD:R_0603_1608Metric_Pad0.98x0.95mm_HandSolder |  | C25810
R10 | 1.8k | Resistor_SMD:R_0603_1608Metric_Pad0.98x0.95mm_HandSolder |  | C4177 |  |  | ~
R100 | 33R | Resistor_SMD:R_0603_1608Metric_Pad0.98x0.95mm_HandSolder |  | C23140 |  |  | ~
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

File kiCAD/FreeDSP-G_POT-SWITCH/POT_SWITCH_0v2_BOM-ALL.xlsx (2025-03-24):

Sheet: ALL
REF | VALUE | FOOTPRINT | JLCPCB# | QTY
J5 | NOP | Connector_JST:JST_XH_B3B-XH-A_1x03_P2.50mm_Vertical | NOP | 1
J6 | NOP | Connector_JST:JST_XH_B3B-XH-A_1x03_P2.50mm_Vertical | NOP | 1
R2 | NOP | Resistor_SMD:R_0805_2012Metric_Pad1.20x1.40mm_HandSolder | NOP | 1
SW5 | SW_NOP | Myfootprints:MJTP1250 | NOP | 1
SW6 | SW_NOP | Myfootprints:MJTP1250 | NOP | 1
SW7 | SW_NOP | Myfootprints:MJTP1250 | NOP | 1
D1 | LED | LED_THT:LED_D3.0mm_Clear | HAND | 1
D2 | LED | LED_THT:LED_D3.0mm_Clear | HAND | 1
D3 | LED | LED_THT:LED_D3.0mm_Clear | HAND | 1
D4 | LED_RED-GRN | LED_THT:LED_D3.0mm-3 | HAND | 1
D5 | LED_YELLOW | LED_THT:LED_D3.0mm | HAND | 1
J1 | JST_S2B-XH | Connector_JST:JST_XH_S2B-XH-A_1x02_P2.50mm_Horizontal | HAND | 1
J2 | JST_S2B-XH | Connector_JST:JST_XH_S2B-XH-A_1x02_P2.50mm_Horizontal | HAND | 1
J3 | JST_S2B-XH | Connector_JST:JST_XH_S2B-XH-A_1x02_P2.50mm_Horizontal | HAND | 1
J4 | Conn_02x07_Odd_Even | Connector_IDC:IDC-Header_2x07_P2.54mm_Horizontal | HAND | 1
J7 | Conn_02x05_Odd_Even | Connector_IDC:IDC-Header_2x05_P2.54mm_Horizontal | HAND | 1
RV1 | B10K | Myfootprints:Alps_RK09K113 | HAND | 1
RV2 | B10K | Myfootprints:Alps_RK09K113 | HAND | 1
RV3 | B10K | Myfootprints:Alps_RK09K113 | HAND | 1
RV4 | B10K | Myfootprints:Alps_RK09K113 | HAND | 1
RV5 | B10K | Myfootprints:Alps_RK09K113 | HAND | 1
RV6 | B10K | Myfootprints:Alps_RK09K113 | HAND | 1
RV7 | B10K | Myfootprints:Alps_RK09K113 | HAND | 1
RV8 | B10K | Myfootprints:Alps_RK09K113 | HAND | 1
RV9 | B10K | Myfootprints:Alps_RK09K113 | HAND | 1
RV10 | B10K | Myfootprints:Alps_RK09K113 | HAND | 1
RV11 | B10K | Myfootprints:Alps_RK09K113 | HAND | 1
RV12 | B10K | Myfootprints:Alps_RK09K113 | HAND | 1
RV13 | B10K | Myfootprints:Alps_RK09K113 | HAND | 1
RV14 | B10K | Myfootprints:Alps_RK09K113 | HAND | 1
SW1 | PUSH-SWITCH-2mm-DPDT | Myfootprints:PUSHSW_DPDT_6-7mm | HAND | 1
SW2 | PUSH-SWITCH-2mm-DPDT | Myfootprints:PUSHSW_DPDT_6-7mm | HAND | 1
SW3 | PUSH-SWITCH-2mm-DPDT | Myfootprints:PUSHSW_DPDT_6-7mm | HAND | 1
SW4 | PUSH-SWITCH-2mm-DPDT | Myfootprints:PUSHSW_DPDT_6-7mm | HAND | 1
SW8 | PUSH-SWITCH-2mm-DPDT | Myfootprints:PUSHSW_DPDT_6-7mm | HAND | 1
U1 | 74HC4053D | Package_DIP:DIP-16_W7.62mm | HAND | 1
U2 | 74HC4053D | Package_DIP:DIP-16_W7.62mm | HAND | 1
U3 | 74HC74 | Package_DIP:DIP-14_W7.62mm | HAND | 1
U4 | 74HC4053D | Package_DIP:DIP-16_W7.62mm | HAND | 1
C1 | 0.1uF | Capacitor_SMD:C_0805_2012Metric_Pad1.18x1.45mm_HandSolder | C49678 | 1
C2 | 0.1uF | Capacitor_SMD:C_0805_2012Metric_Pad1.18x1.45mm_HandSolder | C49678 | 1
C3 | 0.1uF | Capacitor_SMD:C_0805_2012Metric_Pad1.18x1.45mm_HandSolder | C49678 | 1
C4 | 0.1uF | Capacitor_SMD:C_0805_2012Metric_Pad1.18x1.45mm_HandSolder | C49678 | 1
C5 | 0.1uF | Capacitor_SMD:C_0805_2012Metric_Pad1.18x1.45mm_HandSolder | C49678 | 1
C6 | 0.1uF | Capacitor_SMD:C_0805_2012Metric_Pad1.18x1.45mm_HandSolder | C49678 | 1
C7 | 0.1uF | Capacitor_SMD:C_0805_2012Metric_Pad1.18x1.45mm_HandSolder | C49678 | 1
C8 | 0.1uF | Capacitor_SMD:C_0805_2012Metric_Pad1.18x1.45mm_HandSolder | C49678 | 1
C9 | 0.1uF | Capacitor_SMD:C_0805_2012Metric_Pad1.18x1.45mm_HandSolder | C49678 | 1
C10 | 0.1uF | Capacitor_SMD:C_0805_2012Metric_Pad1.18x1.45mm_HandSolder | C49678 | 1
C11 | 0.1uF | Capacitor_SMD:C_0805_2012Metric_Pad1.18x1.45mm_HandSolder | C49678 | 1
C12 | 0.1uF | Capacitor_SMD:C_0805_2012Metric_Pad1.18x1.45mm_HandSolder | C49678 | 1
C13 | 0.1uF | Capacitor_SMD:C_0805_2012Metric_Pad1.18x1.45mm_HandSolder | C49678 | 1
C14 | 0.1uF | Capacitor_SMD:C_0805_2012Metric_Pad1.18x1.45mm_HandSolder | C49678 | 1
C21 | 0.1uF | Capacitor_SMD:C_0805_2012Metric_Pad1.18x1.45mm_HandSolder | C49678 | 1
C22 | 0.1uF | Capacitor_SMD:C_0805_2012Metric_Pad1.18x1.45mm_HandSolder | C49678 | 1
C23 | 0.1uF | Capacitor_SMD:C_0805_2012Metric_Pad1.18x1.45mm_HandSolder | C49678 | 1
C24 | 0.1uF | Capacitor_SMD:C_0805_2012Metric_Pad1.18x1.45mm_HandSolder | C49678 | 1
C25 | 0.1uF | Capacitor_SMD:C_0805_2012Metric_Pad1.18x1.45mm_HandSolder | C49678 | 1
C26 | 0.1uF | Capacitor_SMD:C_0805_2012Metric_Pad1.18x1.45mm_HandSolder | C49678 | 1
C27 | 0.1uF | Capacitor_SMD:C_0805_2012Metric_Pad1.18x1.45mm_HandSolder | C49678 | 1
C28 | 0.1uF | Capacitor_SMD:C_0805_2012Metric_Pad1.18x1.45mm_HandSolder | C49678 | 1
C30 | 0.1uF | Capacitor_SMD:C_0805_2012Metric_Pad1.18x1.45mm_HandSolder | C49678 | 1
C31 | 0.1uF | Capacitor_SMD:C_0805_2012Metric_Pad1.18x1.45mm_HandSolder | C49678 | 1
R26 | 3.9k | Resistor_SMD:R_0805_2012Metric_Pad1.20x1.40mm_HandSolder | C26010 | 1
R27 | 3.9k | Resistor_SMD:R_0805_2012Metric_Pad1.20x1.40mm_HandSolder | C26010 | 1
Q5 | AO3400A | Package_TO_SOT_SMD:SOT-23 | C20917 | 1
R9 | 330R | Resistor_SMD:R_0805_2012Metric_Pad1.20x1.40mm_HandSolder | C17630 | 1
R11 | 330R | Resistor_SMD:R_0805_2012Metric_Pad1.20x1.40mm_HandSolder | C17630 | 1
R14 | 330R | Resistor_SMD:R_0805_2012Metric_Pad1.20x1.40mm_HandSolder | C17630 | 1
R21 | 330R | Resistor_SMD:R_0805_2012Metric_Pad1.20x1.40mm_HandSolder | C17630 | 1
R22 | 330R | Resistor_SMD:R_0805_2012Metric_Pad1.20x1.40mm_HandSolder | C17630 | 1
R23 | 330R | Resistor_SMD:R_0805_2012Metric_Pad1.20x1.40mm_HandSolder | C17630 | 1
R19 | 2.2k | Resistor_SMD:R_0805_2012Metric_Pad1.20x1.40mm_HandSolder | C17520 | 1
R25 | 2.2k | Resistor_SMD:R_0805_2012Metric_Pad1.20x1.40mm_HandSolder | C17520 | 1
R17 | 1MEG | Resistor_SMD:R_0805_2012Metric_Pad1.20x1.40mm_HandSolder | C17514 | 1
R18 | 1MEG | Resistor_SMD:R_0805_2012Metric_Pad1.20x1.40mm_HandSolder | C17514 | 1
R20 | 1k | Resistor_SMD:R_0805_2012Metric_Pad1.20x1.40mm_HandSolder | C17513 | 1
R1 | 0R | Resistor_SMD:R_0805_2012Metric_Pad1.20x1.40mm_HandSolder | C17477 | 1
R3 | 10k | Resistor_SMD:R_0805_2012Metric_Pad1.20x1.40mm_HandSolder | C17414 | 1
R4 | 10k | Resistor_SMD:R_0805_2012Metric_Pad1.20x1.40mm_HandSolder | C17414 | 1
R5 | 10k | Resistor_SMD:R_0805_2012Metric_Pad1.20x1.40mm_HandSolder | C17414 | 1
R6 | 10k | Resistor_SMD:R_0805_2012Metric_Pad1.20x1.40mm_HandSolder | C17414 | 1
R7 | 10k | Resistor_SMD:R_0805_2012Metric_Pad1.20x1.40mm_HandSolder | C17414 | 1
R8 | 10k | Resistor_SMD:R_0805_2012Metric_Pad1.20x1.40mm_HandSolder | C17414 | 1
R13 | 10k | Resistor_SMD:R_0805_2012Metric_Pad1.20x1.40mm_HandSolder | C17414 | 1
R15 | 10k | Resistor_SMD:R_0805_2012Metric_Pad1.20x1.40mm_HandSolder | C17414 | 1
R16 | 10k | Resistor_SMD:R_0805_2012Metric_Pad1.20x1.40mm_HandSolder | C17414 | 1
R24 | 10k | Resistor_SMD:R_0805_2012Metric_Pad1.20x1.40mm_HandSolder | C17414 | 1
C15 | 0.01uF | Capacitor_SMD:C_0805_2012Metric_Pad1.18x1.45mm_HandSolder | C1710 | 1
C16 | 0.01uF | Capacitor_SMD:C_0805_2012Metric_Pad1.18x1.45mm_HandSolder | C1710 | 1
C17 | 0.01uF | Capacitor_SMD:C_0805_2012Metric_Pad1.18x1.45mm_HandSolder | C1710 | 1
C18 | 0.01uF | Capacitor_SMD:C_0805_2012Metric_Pad1.18x1.45mm_HandSolder | C1710 | 1
C19 | 0.01uF | Capacitor_SMD:C_0805_2012Metric_Pad1.18x1.45mm_HandSolder | C1710 | 1
C20 | 0.01uF | Capacitor_SMD:C_0805_2012Metric_Pad1.18x1.45mm_HandSolder | C1710 | 1
C33 | 0.01uF | Capacitor_SMD:C_0805_2012Metric_Pad1.18x1.45mm_HandSolder | C1710 | 1
C34 | 0.01uF | Capacitor_SMD:C_0805_2012Metric_Pad1.18x1.45mm_HandSolder | C1710 | 1
C32 | 10uF | Capacitor_SMD:C_0805_2012Metric_Pad1.18x1.45mm_HandSolder | C15850 | 1
Q1 | AO3401A | digikey-footprints:SOT-23-3 | C15127 | 1
Q3 | AO3401A | digikey-footprints:SOT-23-3 | C15127 | 1
H1 | MountingHole | MountingHole:MountingHole_3.2mm_M3_DIN965_Pad_TopBottom | - | 1
H2 | MountingHole | MountingHole:MountingHole_3.2mm_M3_DIN965_Pad_TopBottom | - | 1
H3 | MountingHole | MountingHole:MountingHole_3.2mm_M3_DIN965_Pad_TopBottom | - | 1
H4 | MountingHole | MountingHole:MountingHole_3.2mm_M3_DIN965_Pad_TopBottom | - | 1
H5 | MountingHole | MountingHole:MountingHole_3.2mm_M3_DIN965_Pad_TopBottom | - | 1
H6 | MountingHole | MountingHole:MountingHole_3.2mm_M3_DIN965_Pad_TopBottom | - | 1
H7 | MountingHole | MountingHole:MountingHole_3.2mm_M3_DIN965_Pad_TopBottom | - | 1
H8 | MountingHole | MountingHole:MountingHole_3.2mm_M3_DIN965_Pad_TopBottom | - | 1

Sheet: SMT
REF | VALUE | FOOTPRINT | JLCPCB# | QTY
C1 | 0.1uF | Capacitor_SMD:C_0805_2012Metric_Pad1.18x1.45mm_HandSolder | C49678 | 1
C2 | 0.1uF | Capacitor_SMD:C_0805_2012Metric_Pad1.18x1.45mm_HandSolder | C49678 | 1
C3 | 0.1uF | Capacitor_SMD:C_0805_2012Metric_Pad1.18x1.45mm_HandSolder | C49678 | 1
C4 | 0.1uF | Capacitor_SMD:C_0805_2012Metric_Pad1.18x1.45mm_HandSolder | C49678 | 1
C5 | 0.1uF | Capacitor_SMD:C_0805_2012Metric_Pad1.18x1.45mm_HandSolder | C49678 | 1
C6 | 0.1uF | Capacitor_SMD:C_0805_2012Metric_Pad1.18x1.45mm_HandSolder | C49678 | 1
C7 | 0.1uF | Capacitor_SMD:C_0805_2012Metric_Pad1.18x1.45mm_HandSolder | C49678 | 1
C8 | 0.1uF | Capacitor_SMD:C_0805_2012Metric_Pad1.18x1.45mm_HandSolder | C49678 | 1
C9 | 0.1uF | Capacitor_SMD:C_0805_2012Metric_Pad1.18x1.45mm_HandSolder | C49678 | 1
C10 | 0.1uF | Capacitor_SMD:C_0805_2012Metric_Pad1.18x1.45mm_HandSolder | C49678 | 1
C11 | 0.1uF | Capacitor_SMD:C_0805_2012Metric_Pad1.18x1.45mm_HandSolder | C49678 | 1
C12 | 0.1uF | Capacitor_SMD:C_0805_2012Metric_Pad1.18x1.45mm_HandSolder | C49678 | 1
C13 | 0.1uF | Capacitor_SMD:C_0805_2012Metric_Pad1.18x1.45mm_HandSolder | C49678 | 1
C14 | 0.1uF | Capacitor_SMD:C_0805_2012Metric_Pad1.18x1.45mm_HandSolder | C49678 | 1
C21 | 0.1uF | Capacitor_SMD:C_0805_2012Metric_Pad1.18x1.45mm_HandSolder | C49678 | 1
C22 | 0.1uF | Capacitor_SMD:C_0805_2012Metric_Pad1.18x1.45mm_HandSolder | C49678 | 1
C23 | 0.1uF | Capacitor_SMD:C_0805_2012Metric_Pad1.18x1.45mm_HandSolder | C49678 | 1
C24 | 0.1uF | Capacitor_SMD:C_0805_2012Metric_Pad1.18x1.45mm_HandSolder | C49678 | 1
C25 | 0.1uF | Capacitor_SMD:C_0805_2012Metric_Pad1.18x1.45mm_HandSolder | C49678 | 1
C26 | 0.1uF | Capacitor_SMD:C_0805_2012Metric_Pad1.18x1.45mm_HandSolder | C49678 | 1
C27 | 0.1uF | Capacitor_SMD:C_0805_2012Metric_Pad1.18x1.45mm_HandSolder | C49678 | 1
C28 | 0.1uF | Capacitor_SMD:C_0805_2012Metric_Pad1.18x1.45mm_HandSolder | C49678 | 1
C30 | 0.1uF | Capacitor_SMD:C_0805_2012Metric_Pad1.18x1.45mm_HandSolder | C49678 | 1
C31 | 0.1uF | Capacitor_SMD:C_0805_2012Metric_Pad1.18x1.45mm_HandSolder | C49678 | 1
R26 | 3.9k | Resistor_SMD:R_0805_2012Metric_Pad1.20x1.40mm_HandSolder | C26010 | 1
R27 | 3.9k | Resistor_SMD:R_0805_2012Metric_Pad1.20x1.40mm_HandSolder | C26010 | 1
Q5 | AO3400A | Package_TO_SOT_SMD:SOT-23 | C20917 | 1
R9 | 330R | Resistor_SMD:R_0805_2012Metric_Pad1.20x1.40mm_HandSolder | C17630 | 1
R11 | 330R | Resistor_SMD:R_0805_2012Metric_Pad1.20x1.40mm_HandSolder | C17630 | 1
R14 | 330R | Resistor_SMD:R_0805_2012Metric_Pad1.20x1.40mm_HandSolder | C17630 | 1
R21 | 330R | Resistor_SMD:R_0805_2012Metric_Pad1.20x1.40mm_HandSolder | C17630 | 1
R22 | 330R | Resistor_SMD:R_0805_2012Metric_Pad1.20x1.40mm_HandSolder | C17630 | 1
R23 | 330R | Resistor_SMD:R_0805_2012Metric_Pad1.20x1.40mm_HandSolder | C17630 | 1
R19 | 2.2k | Resistor_SMD:R_0805_2012Metric_Pad1.20x1.40mm_HandSolder | C17520 | 1
R25 | 2.2k | Resistor_SMD:R_0805_2012Metric_Pad1.20x1.40mm_HandSolder | C17520 | 1
R17 | 1MEG | Resistor_SMD:R_0805_2012Metric_Pad1.20x1.40mm_HandSolder | C17514 | 1
R18 | 1MEG | Resistor_SMD:R_0805_2012Metric_Pad1.20x1.40mm_HandSolder | C17514 | 1
R20 | 1k | Resistor_SMD:R_0805_2012Metric_Pad1.20x1.40mm_HandSolder | C17513 | 1
R1 | 0R | Resistor_SMD:R_0805_2012Metric_Pad1.20x1.40mm_HandSolder | C17477 | 1
R3 | 10k | Resistor_SMD:R_0805_2012Metric_Pad1.20x1.40mm_HandSolder | C17414 | 1
R4 | 10k | Resistor_SMD:R_0805_2012Metric_Pad1.20x1.40mm_HandSolder | C17414 | 1
R5 | 10k | Resistor_SMD:R_0805_2012Metric_Pad1.20x1.40mm_HandSolder | C17414 | 1
R6 | 10k | Resistor_SMD:R_0805_2012Metric_Pad1.20x1.40mm_HandSolder | C17414 | 1
R7 | 10k | Resistor_SMD:R_0805_2012Metric_Pad1.20x1.40mm_HandSolder | C17414 | 1
R8 | 10k | Resistor_SMD:R_0805_2012Metric_Pad1.20x1.40mm_HandSolder | C17414 | 1
R13 | 10k | Resistor_SMD:R_0805_2012Metric_Pad1.20x1.40mm_HandSolder | C17414 | 1
R15 | 10k | Resistor_SMD:R_0805_2012Metric_Pad1.20x1.40mm_HandSolder | C17414 | 1
R16 | 10k | Resistor_SMD:R_0805_2012Metric_Pad1.20x1.40mm_HandSolder | C17414 | 1
R24 | 10k | Resistor_SMD:R_0805_2012Metric_Pad1.20x1.40mm_HandSolder | C17414 | 1
C15 | 0.01uF | Capacitor_SMD:C_0805_2012Metric_Pad1.18x1.45mm_HandSolder | C1710 | 1
C16 | 0.01uF | Capacitor_SMD:C_0805_2012Metric_Pad1.18x1.45mm_HandSolder | C1710 | 1
C17 | 0.01uF | Capacitor_SMD:C_0805_2012Metric_Pad1.18x1.45mm_HandSolder | C1710 | 1
C18 | 0.01uF | Capacitor_SMD:C_0805_2012Metric_Pad1.18x1.45mm_HandSolder | C1710 | 1
C19 | 0.01uF | Capacitor_SMD:C_0805_2012Metric_Pad1.18x1.45mm_HandSolder | C1710 | 1
C20 | 0.01uF | Capacitor_SMD:C_0805_2012Metric_Pad1.18x1.45mm_HandSolder | C1710 | 1
C33 | 0.01uF | Capacitor_SMD:C_0805_2012Metric_Pad1.18x1.45mm_HandSolder | C1710 | 1
C34 | 0.01uF | Capacitor_SMD:C_0805_2012Metric_Pad1.18x1.45mm_HandSolder | C1710 | 1
C32 | 10uF | Capacitor_SMD:C_0805_2012Metric_Pad1.18x1.45mm_HandSolder | C15850 | 1
Q1 | AO3401A | digikey-footprints:SOT-23-3 | C15127 | 1
Q3 | AO3401A | digikey-footprints:SOT-23-3 | C15127 | 1

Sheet: HAND
REF | VALUE | FOOTPRINT | JLCPCB# | QTY
D1 | LED | LED_THT:LED_D3.0mm_Clear | HAND | 1
D2 | LED | LED_THT:LED_D3.0mm_Clear | HAND | 1
D3 | LED | LED_THT:LED_D3.0mm_Clear | HAND | 1
D4 | LED_RED-GRN | LED_THT:LED_D3.0mm-3 | HAND | 1
D5 | LED_YELLOW | LED_THT:LED_D3.0mm | HAND | 1
J1 | JST_S2B-XH | Connector_JST:JST_XH_S2B-XH-A_1x02_P2.50mm_Horizontal | HAND | 1
J2 | JST_S2B-XH | Connector_JST:JST_XH_S2B-XH-A_1x02_P2.50mm_Horizontal | HAND | 1
J3 | JST_S2B-XH | Connector_JST:JST_XH_S2B-XH-A_1x02_P2.50mm_Horizontal | HAND | 1
J4 | Conn_02x07_Odd_Even | Connector_IDC:IDC-Header_2x07_P2.54mm_Horizontal | HAND | 1
J7 | Conn_02x05_Odd_Even | Connector_IDC:IDC-Header_2x05_P2.54mm_Horizontal | HAND | 1
RV1 | B10K | Myfootprints:Alps_RK09K113 | HAND | 1
RV2 | B10K | Myfootprints:Alps_RK09K113 | HAND | 1
RV3 | B10K | Myfootprints:Alps_RK09K113 | HAND | 1
RV4 | B10K | Myfootprints:Alps_RK09K113 | HAND | 1
RV5 | B10K | Myfootprints:Alps_RK09K113 | HAND | 1
RV6 | B10K | Myfootprints:Alps_RK09K113 | HAND | 1
RV7 | B10K | Myfootprints:Alps_RK09K113 | HAND | 1
RV8 | B10K | Myfootprints:Alps_RK09K113 | HAND | 1
RV9 | B10K | Myfootprints:Alps_RK09K113 | HAND | 1
RV10 | B10K | Myfootprints:Alps_RK09K113 | HAND | 1
RV11 | B10K | Myfootprints:Alps_RK09K113 | HAND | 1
RV12 | B10K | Myfootprints:Alps_RK09K113 | HAND | 1
RV13 | B10K | Myfootprints:Alps_RK09K113 | HAND | 1
RV14 | B10K | Myfootprints:Alps_RK09K113 | HAND | 1
SW1 | PUSH-SWITCH-2mm-DPDT | Myfootprints:PUSHSW_DPDT_6-7mm | HAND | 1
SW2 | PUSH-SWITCH-2mm-DPDT | Myfootprints:PUSHSW_DPDT_6-7mm | HAND | 1
SW3 | PUSH-SWITCH-2mm-DPDT | Myfootprints:PUSHSW_DPDT_6-7mm | HAND | 1
SW4 | PUSH-SWITCH-2mm-DPDT | Myfootprints:PUSHSW_DPDT_6-7mm | HAND | 1
SW8 | PUSH-SWITCH-2mm-DPDT | Myfootprints:PUSHSW_DPDT_6-7mm | HAND | 1
U1 | 74HC4053D | Package_DIP:DIP-16_W7.62mm | HAND | 1
U2 | 74HC4053D | Package_DIP:DIP-16_W7.62mm | HAND | 1
U3 | 74HC74 | Package_DIP:DIP-14_W7.62mm | HAND | 1
U4 | 74HC4053D | Package_DIP:DIP-16_W7.62mm | HAND | 1

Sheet: NOPOP
REF | VALUE | FOOTPRINT | JLCPCB# | QTY
J5 | NOP | Connector_JST:JST_XH_B3B-XH-A_1x03_P2.50mm_Vertical | NOP | 1
J6 | NOP | Connector_JST:JST_XH_B3B-XH-A_1x03_P2.50mm_Vertical | NOP | 1
R2 | NOP | Resistor_SMD:R_0805_2012Metric_Pad1.20x1.40mm_HandSolder | NOP | 1
SW5 | SW_NOP | Myfootprints:MJTP1250 | NOP | 1
SW6 | SW_NOP | Myfootprints:MJTP1250 | NOP | 1
SW7 | SW_NOP | Myfootprints:MJTP1250 | NOP | 1
H1 | MountingHole | MountingHole:MountingHole_3.2mm_M3_DIN965_Pad_TopBottom | NOP | 1
H2 | MountingHole | MountingHole:MountingHole_3.2mm_M3_DIN965_Pad_TopBottom | NOP | 1
H3 | MountingHole | MountingHole:MountingHole_3.2mm_M3_DIN965_Pad_TopBottom | NOP | 1
H4 | MountingHole | MountingHole:MountingHole_3.2mm_M3_DIN965_Pad_TopBottom | NOP | 1
H5 | MountingHole | MountingHole:MountingHole_3.2mm_M3_DIN965_Pad_TopBottom | NOP | 1
H6 | MountingHole | MountingHole:MountingHole_3.2mm_M3_DIN965_Pad_TopBottom | NOP | 1
H7 | MountingHole | MountingHole:MountingHole_3.2mm_M3_DIN965_Pad_TopBottom | NOP | 1
H8 | MountingHole | MountingHole:MountingHole_3.2mm_M3_DIN965_Pad_TopBottom | NOP | 1

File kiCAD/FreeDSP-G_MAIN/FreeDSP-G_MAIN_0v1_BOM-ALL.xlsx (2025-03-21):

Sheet: PCBA
Reference(s) | Qty | JLPCB# | Value | Footprint | Description | Datasheet
IC5 | 1 | C9864 | TPS5430DDA | Package_SO:TI_SO-PowerPAD-8_ThermalVias | SMPS for digital part | http://www.ti.com/lit/ds/symlink/tps5430.pdf
C93 | 1 | C96123 | 47uF/10V | Capacitor_SMD:C_1206_3216Metric |  | ~
D4, D5, D7, D8, D9, D11 | 6 | C8598 | B5819W SL | Diode_SMD:D_SOD-123 | SBD 1A/40V | http://www.vishay.com/docs/85660/bat42.pdf
Q5, Q6 | 2 | C8326 | MMBT5401 | Package_TO_SOT_SMD:SOT-23 | PNP Transistor 350mW | ~
R72 | 1 | C8218 | 200R | Resistor_SMD:R_0603_1608Metric_Pad0.98x0.95mm_HandSolder |  | ~
D6 | 1 | C81598 | 1N4148W | Diode_SMD:D_SOD-123 | Switching Diode 150mA/75V | ~
Q3, Q4 | 2 | C79973 | 2SD2704KT146 | Package_TO_SOT_SMD:SOT-23 | NPN Transistor for anti-pop muting | ~
U8, U10 | 2 | C75510 | LM317AG-TN3-R | Package_TO_SOT_SMD:TO-252-2 | Voltage Regurator for Analog | https://datasheet.lcsc.com/lcsc/2304140030_UTC-Unisonic-Tech-LM317AG-TN3-R_C75510.pdf
D10 | 1 | C72038 | LED_YELLOW | LED_SMD:LED_0603_1608Metric_Castellated | Indicator for USBi is Active
C54, C55, C56, C57 | 4 | C7171 | 10uF/16V(Ta) | Capacitors_Tantalum_SMD:CP_Tantalum_Case-A_EIA-3216-18_Reflow | Tanatalium 3216 metric
U12 | 1 | C654414 | ADAU1467 | Myfootprints:ADAU1467WBCPZ300 | SigmaDSP | https://www.analog.com/media/en/technical-documentation/data-sheets/adau1463-1467.pdf
U9 | 1 | C6186 | AMS1117-3.3 | digikey-footprints:SOT-223
C108, C130 | 2 | C57112 | 10nF | Capacitor_SMD:C_0603_1608Metric_Pad1.08x0.95mm_HandSolder |  | ~
IC3, IC4 | 2 | C55513 | PCM1808QPWR | Myfootprints:PCM1808QPWRQ1 | ADC 99dB SNR @48kHz Sampling | http://www.ti.com/lit/ds/symlink/pcm1808-q1.pdf
C5, C8, C37, C39, C43, C45, C69, C106, C114, C117, C132 | 11 | C440198 | 10uF | Capacitor_SMD:C_0805_2012Metric |  | ~
C6, C66, C67, C68 | 4 | C440198 | 10uF | Capacitor_SMD:C_0805_2012Metric
C14, C21, C25, C28 | 4 | C440198 | 10uF | Capacitor_SMD:C_0805_2012Metric |  | ~
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

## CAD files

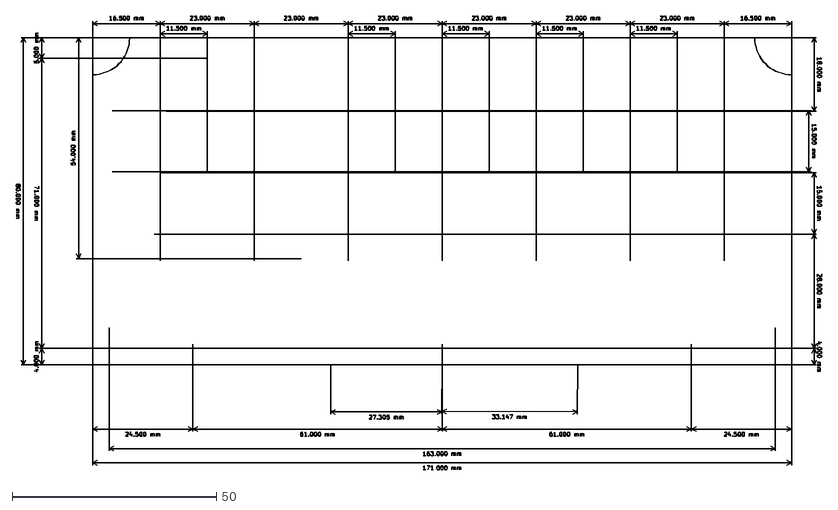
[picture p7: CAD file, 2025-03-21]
kiCAD/FreeDSP-G_POT-SWITCH/JLCPCB_OrderFiles/POT_SWITCH-Dwgs_User.dxf
197.1 x 111.1

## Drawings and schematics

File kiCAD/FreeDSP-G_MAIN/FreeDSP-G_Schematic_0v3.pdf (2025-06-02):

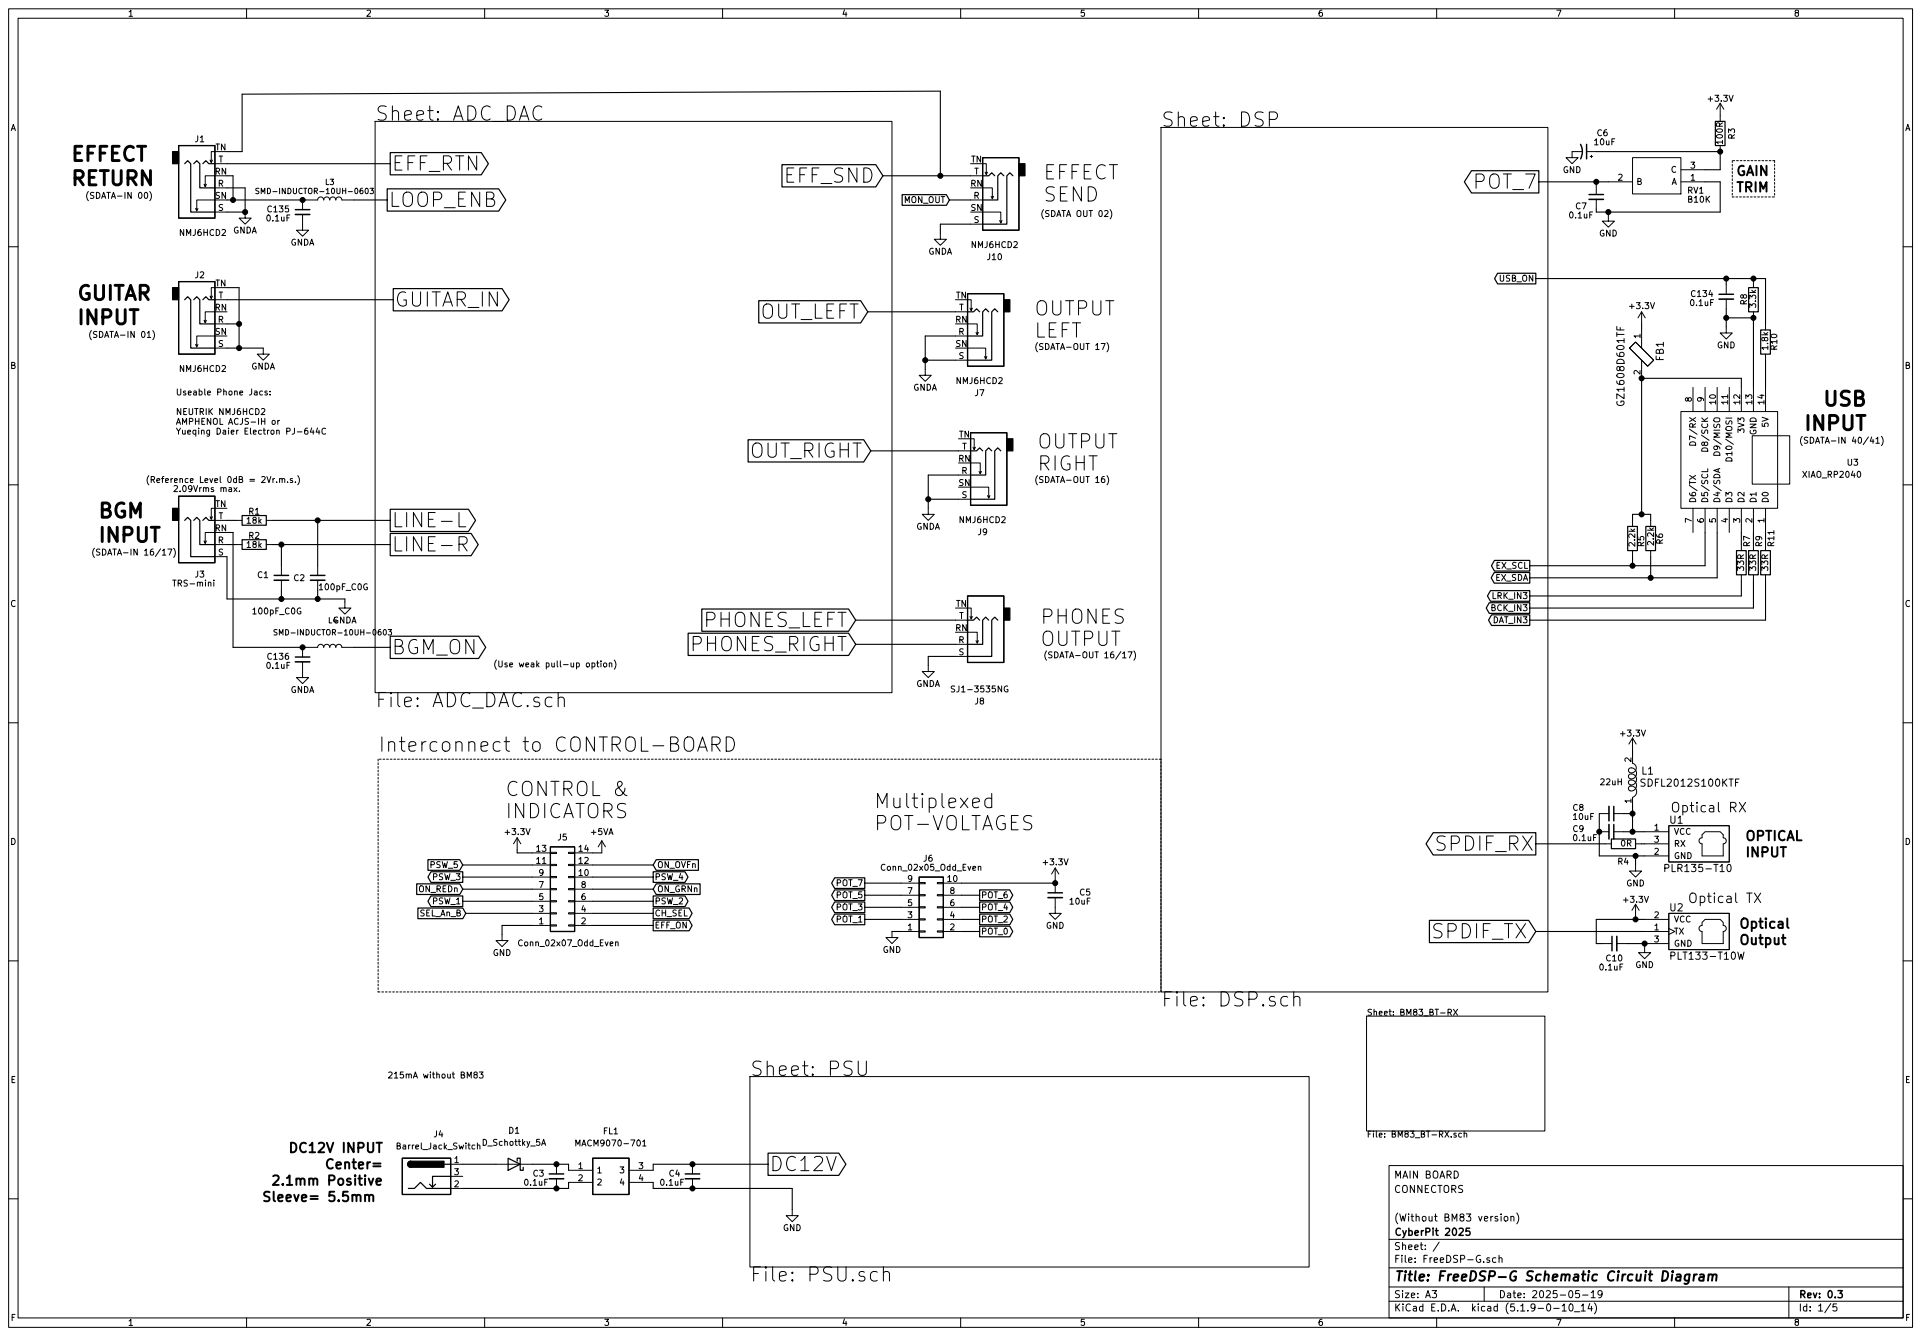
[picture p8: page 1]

Useable Phone Jacs: NEUTRIK NMJ6HCD2 AMPHENOL ACJS-IH or Yueqing Daier Electron PJ-644C

(Use weak pull-up option)

File: ADC_DAC.sch
Interconnect to CONTROL-BOARD

(Without BM83 version) CONNECTORS MAIN BOARD

File: FreeDSP-G.sch Sheet: / CyberPit 2025

Id: 1/5 Title: FreeDSP-G Schematic Circuit Diagram

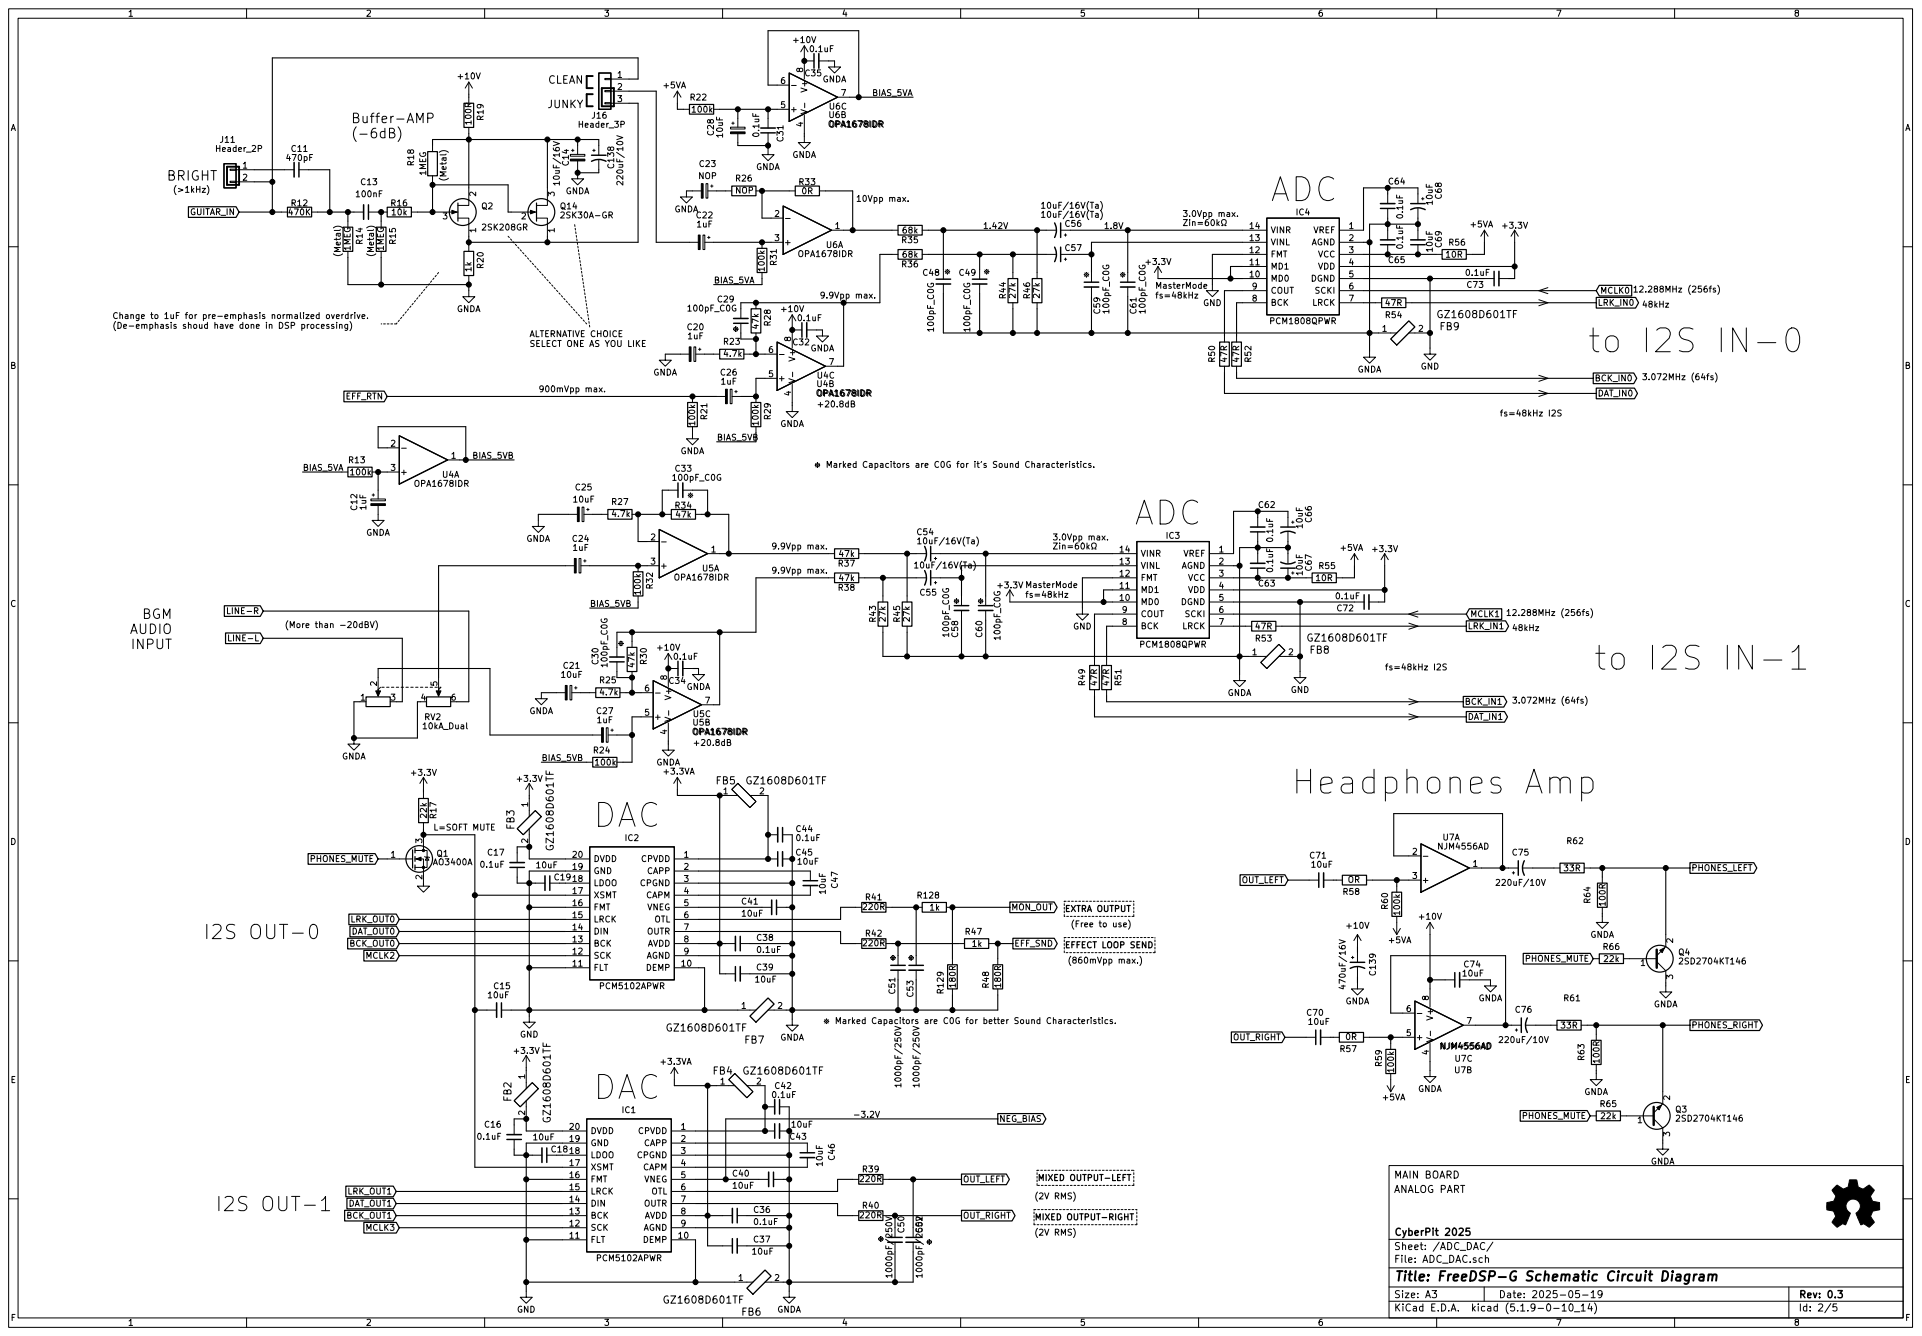
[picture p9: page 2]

Change to 1uF for pre-emphasis normalized overdrive.
(De-emphasis shoud have done in DSP processing)

SELECT ONE AS YOU LIKE

Marked Capacitors are C0G for its Sound Characteristics.

fs=48kHz I2S MIXED OUTPUT-LEFT

Marked Capacitors are C0G for better Sound Characteristics.

CyberPit 2025 ANALOG PART MAIN BOARD

(2V RMS) MIXED OUTPUT-RIGHT

Sheet: /ADC_DAC/
File: ADC_DAC.sch
Id: 2/5 Title: FreeDSP-G Schematic Circuit Diagram

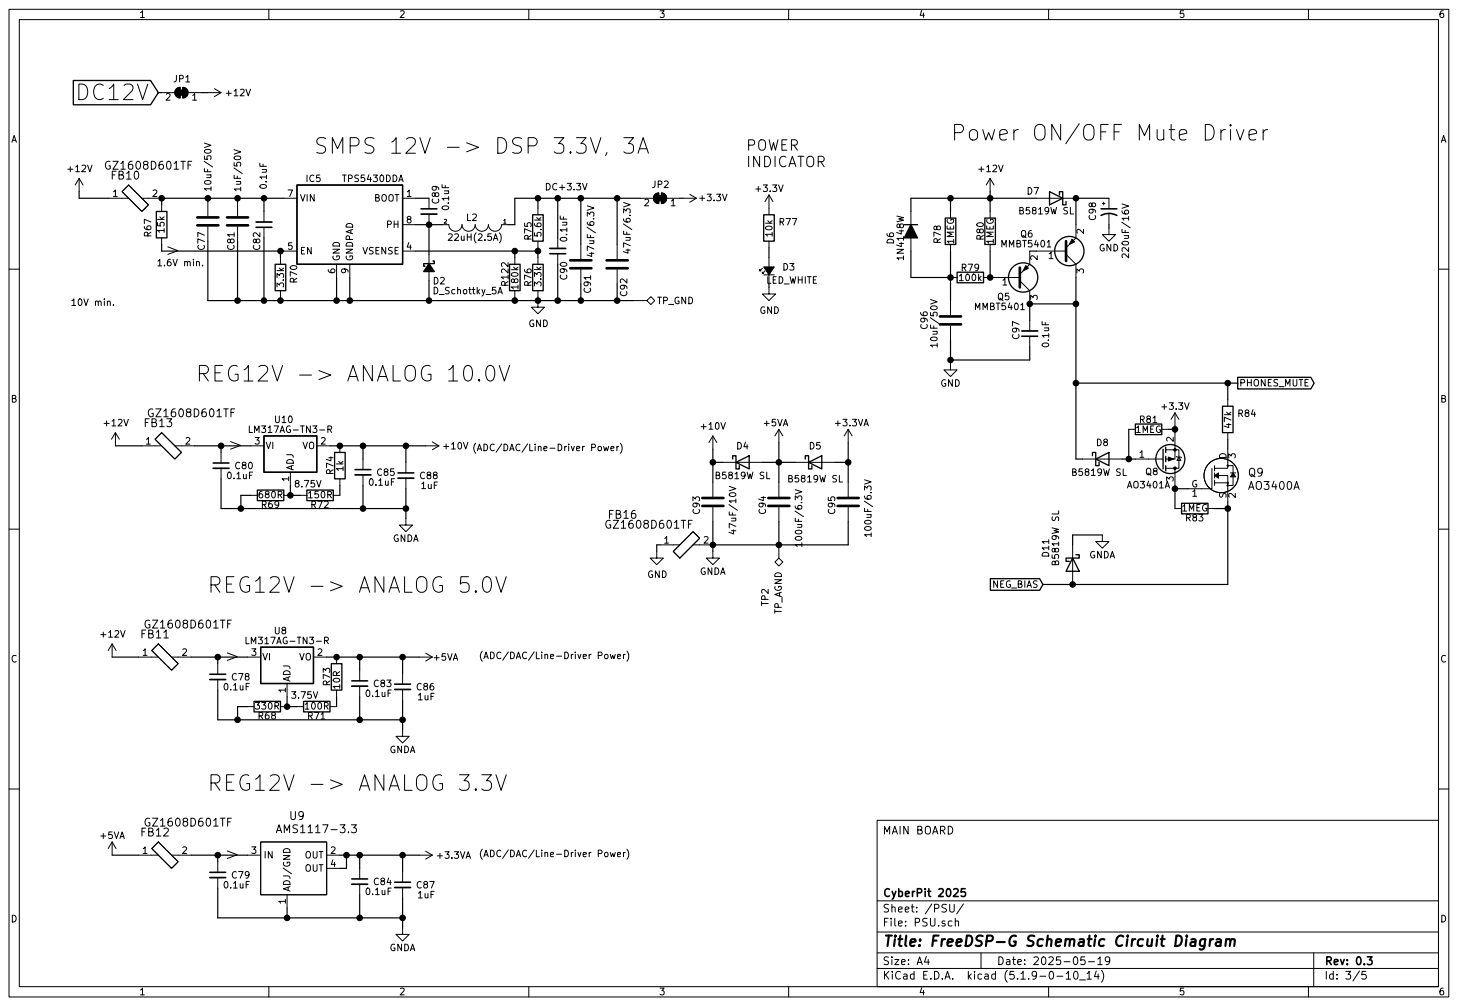
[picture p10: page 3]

Power ON/OFF Mute Driver

(ADC/DAC/Line-Driver Power)

File: PSU.sch Sheet: /PSU/ CyberPit 2025 MAIN BOARD

Id: 3/5 Title: FreeDSP-G Schematic Circuit Diagram

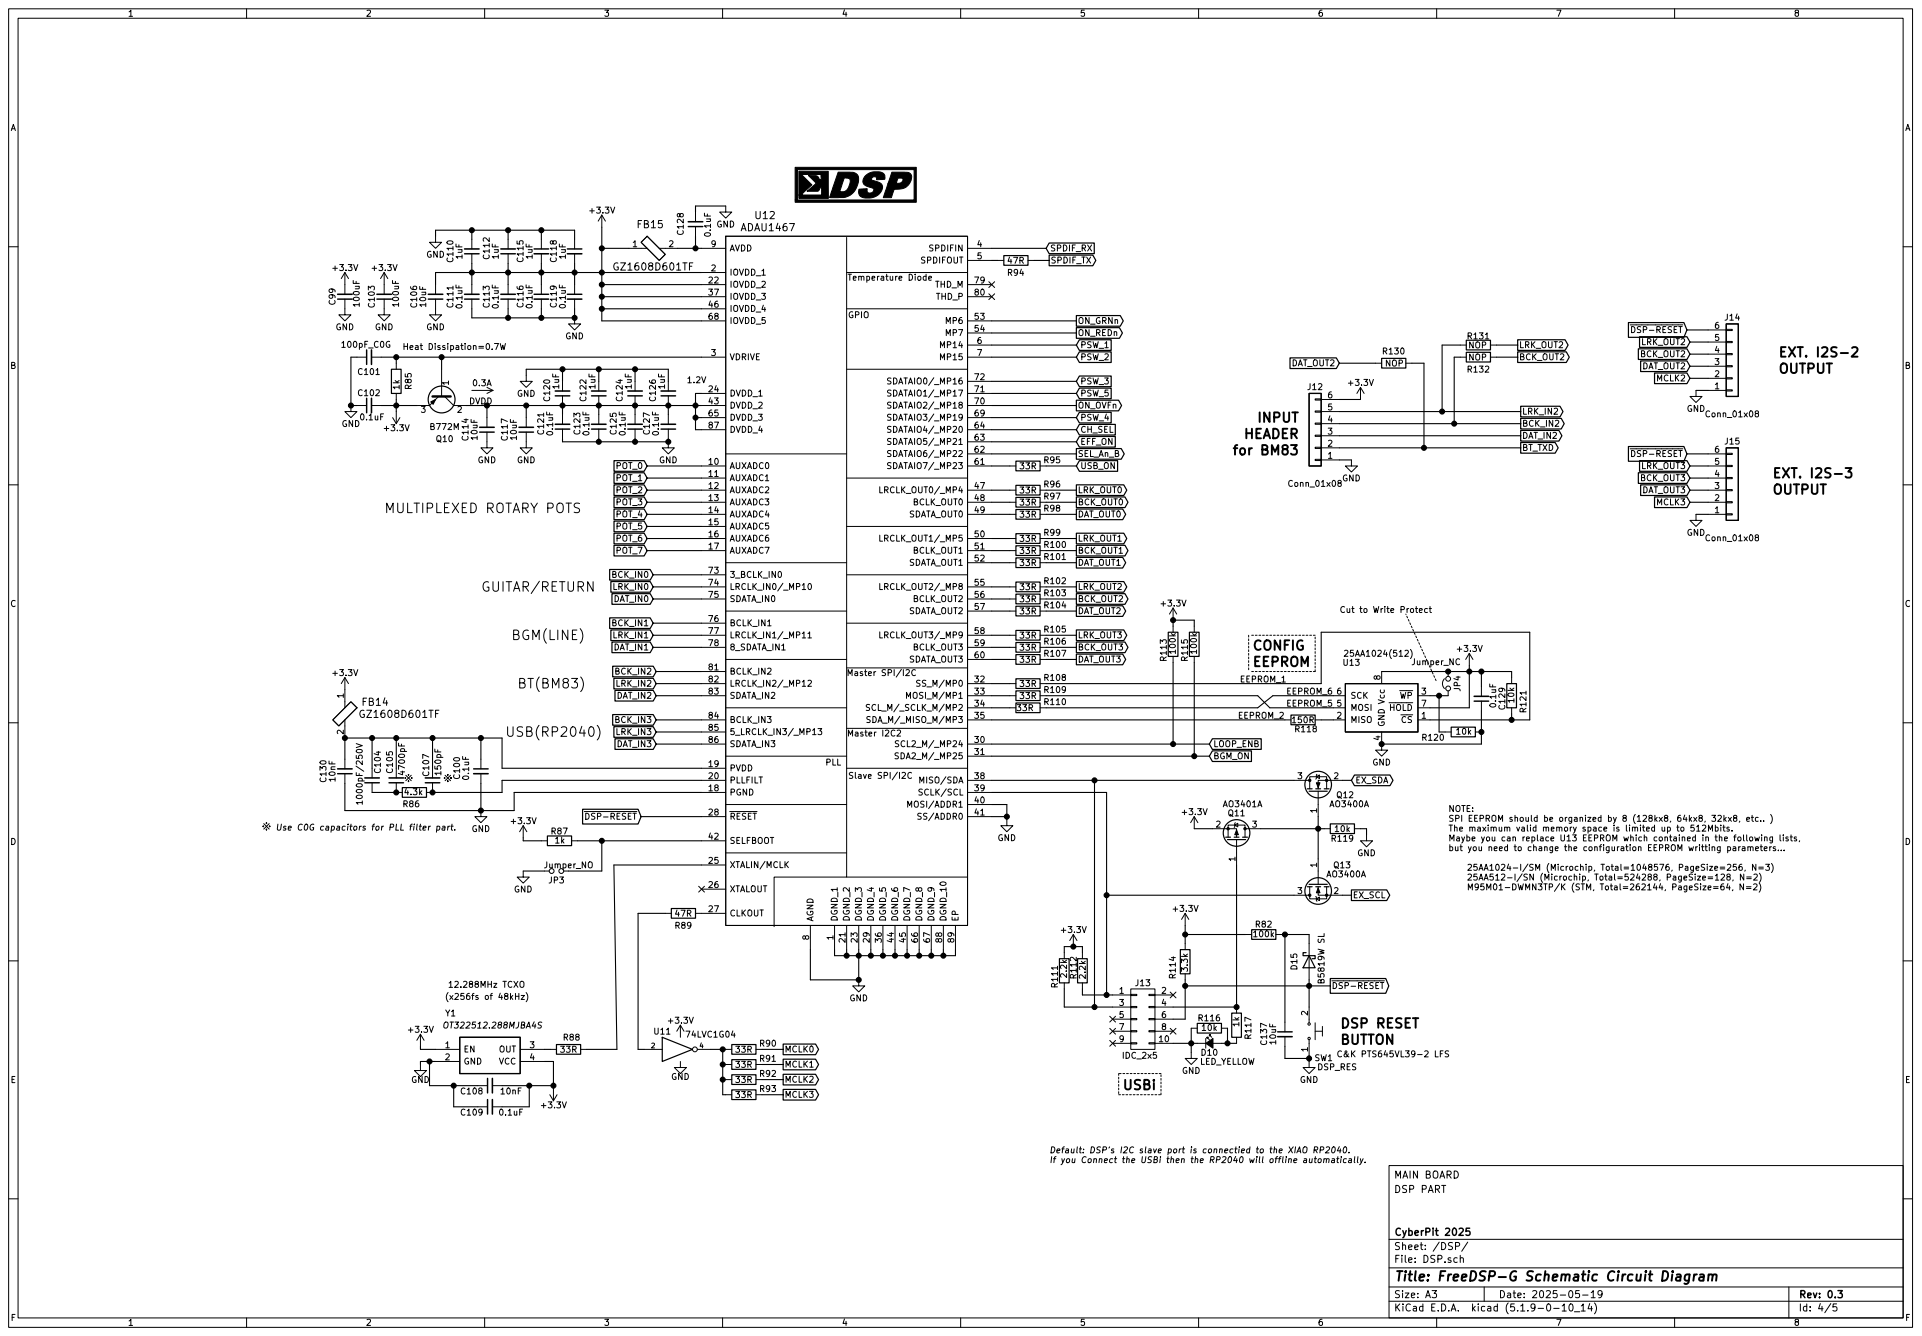
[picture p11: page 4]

M95M01-DWMN3TP/K (STM, Total=262144, PageSize=64, N=2) Cut to Write Protect

4 MOSI 5 SCK 6 HOLD 7 Vcc 8 U13

NOTE: SPI EEPROM should be organized by 8 (128kx8, 64kx8, 32kx8, etc.. )

Use C0G capacitors for PLL filter part.

The maximum valid memory space is limited up to 512Mbits.
Maybe you can replace U13 EEPROM which contained in the following lists,
but you need to change the configuration EEPROM writting parameters

25AA1024-I/SM (Microchip, Total=1048576, PageSize=256, N=3)
25AA512-I/SN (Microchip, Total=524288, PageSize=128, N=2)

Default: DSPs I2C slave port is connectied to the XIAO RP2040.
If you Connect the USBi then the RP2040 will offline automatically.

File: DSP.sch Sheet: /DSP/ CyberPit 2025 DSP PART MAIN BOARD

Id: 4/5 Title: FreeDSP-G Schematic Circuit Diagram

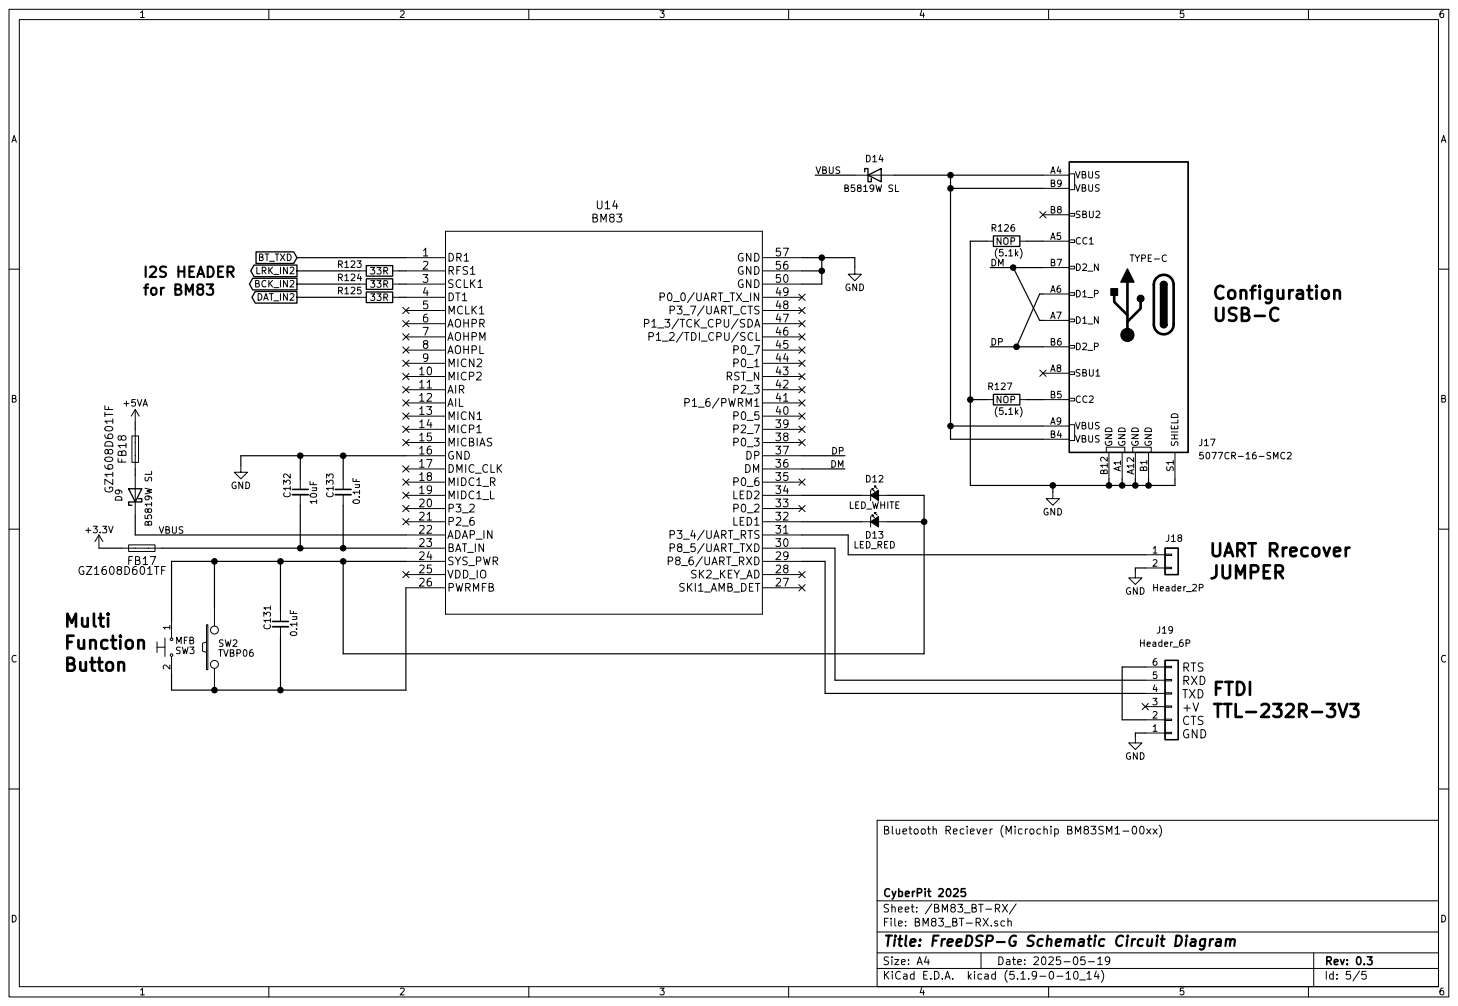
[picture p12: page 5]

CyberPit 2025
Sheet: /BM83_BT-RX/
File: BM83_BT-RX.sch
Id: 5/5 Title: FreeDSP-G Schematic Circuit Diagram

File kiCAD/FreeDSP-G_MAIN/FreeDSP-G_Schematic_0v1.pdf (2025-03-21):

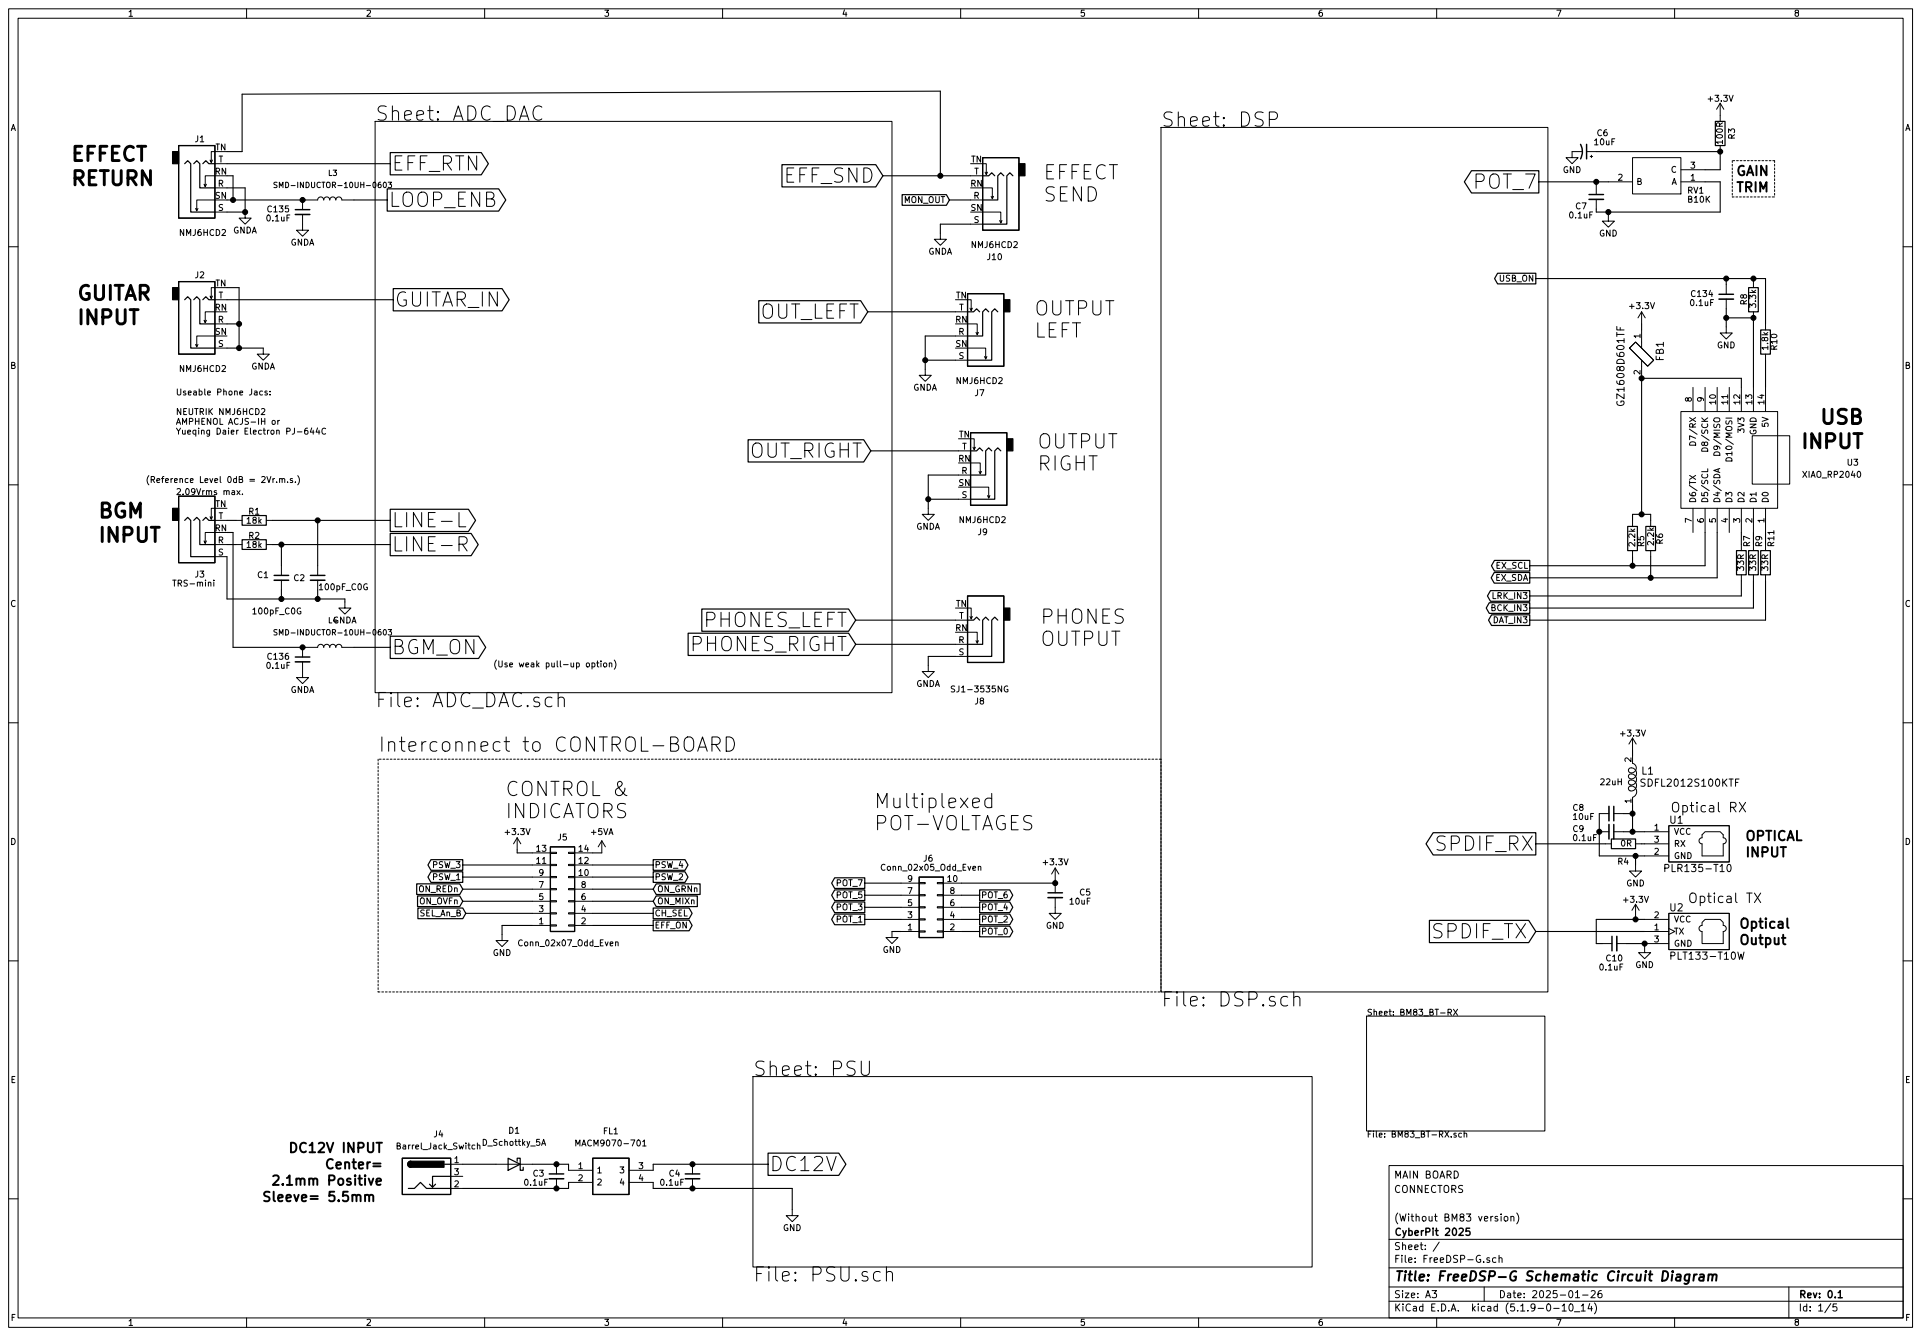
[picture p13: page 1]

Useable Phone Jacs: NEUTRIK NMJ6HCD2 AMPHENOL ACJS-IH or Yueqing Daier Electron PJ-644C

(Use weak pull-up option)

File: ADC_DAC.sch
Interconnect to CONTROL-BOARD

(Without BM83 version) CONNECTORS MAIN BOARD

File: FreeDSP-G.sch Sheet: / CyberPit 2025

Id: 1/5 Title: FreeDSP-G Schematic Circuit Diagram

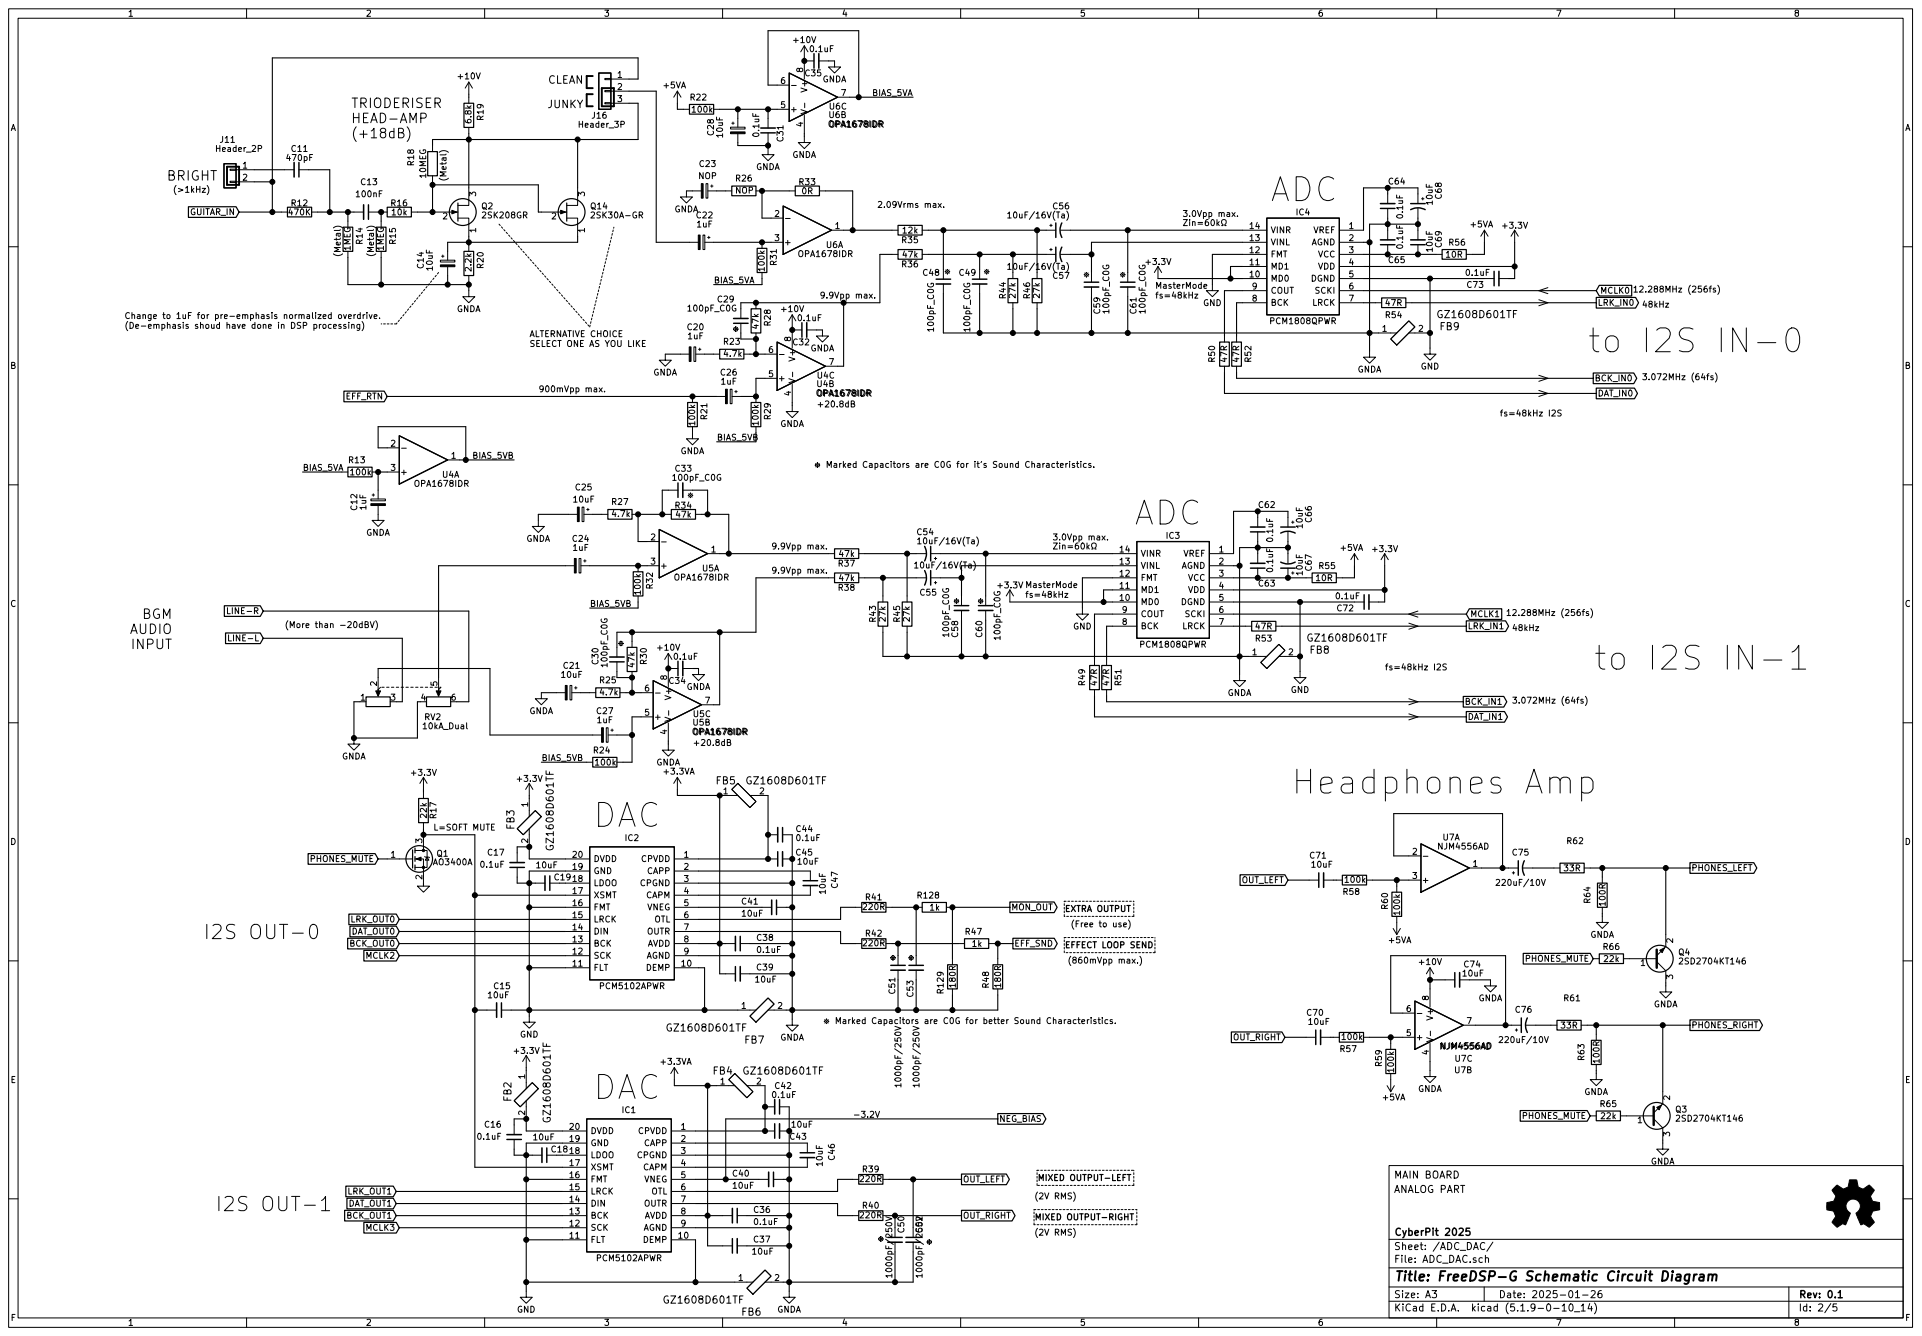
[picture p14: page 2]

SELECT ONE AS YOU LIKE DAC

MIXED OUTPUT-LEFT MIXED OUTPUT-RIGHT (Metal)

Change to 1uF for pre-emphasis normalized overdrive.

Marked Capacitors are C0G for its Sound Characteristics.

(860mVpp max.) EFFECT LOOP SEND

Marked Capacitors are C0G for better Sound Characteristics.

CyberPit 2025 ANALOG PART MAIN BOARD

Sheet: /ADC_DAC/
File: ADC_DAC.sch
Id: 2/5 Title: FreeDSP-G Schematic Circuit Diagram

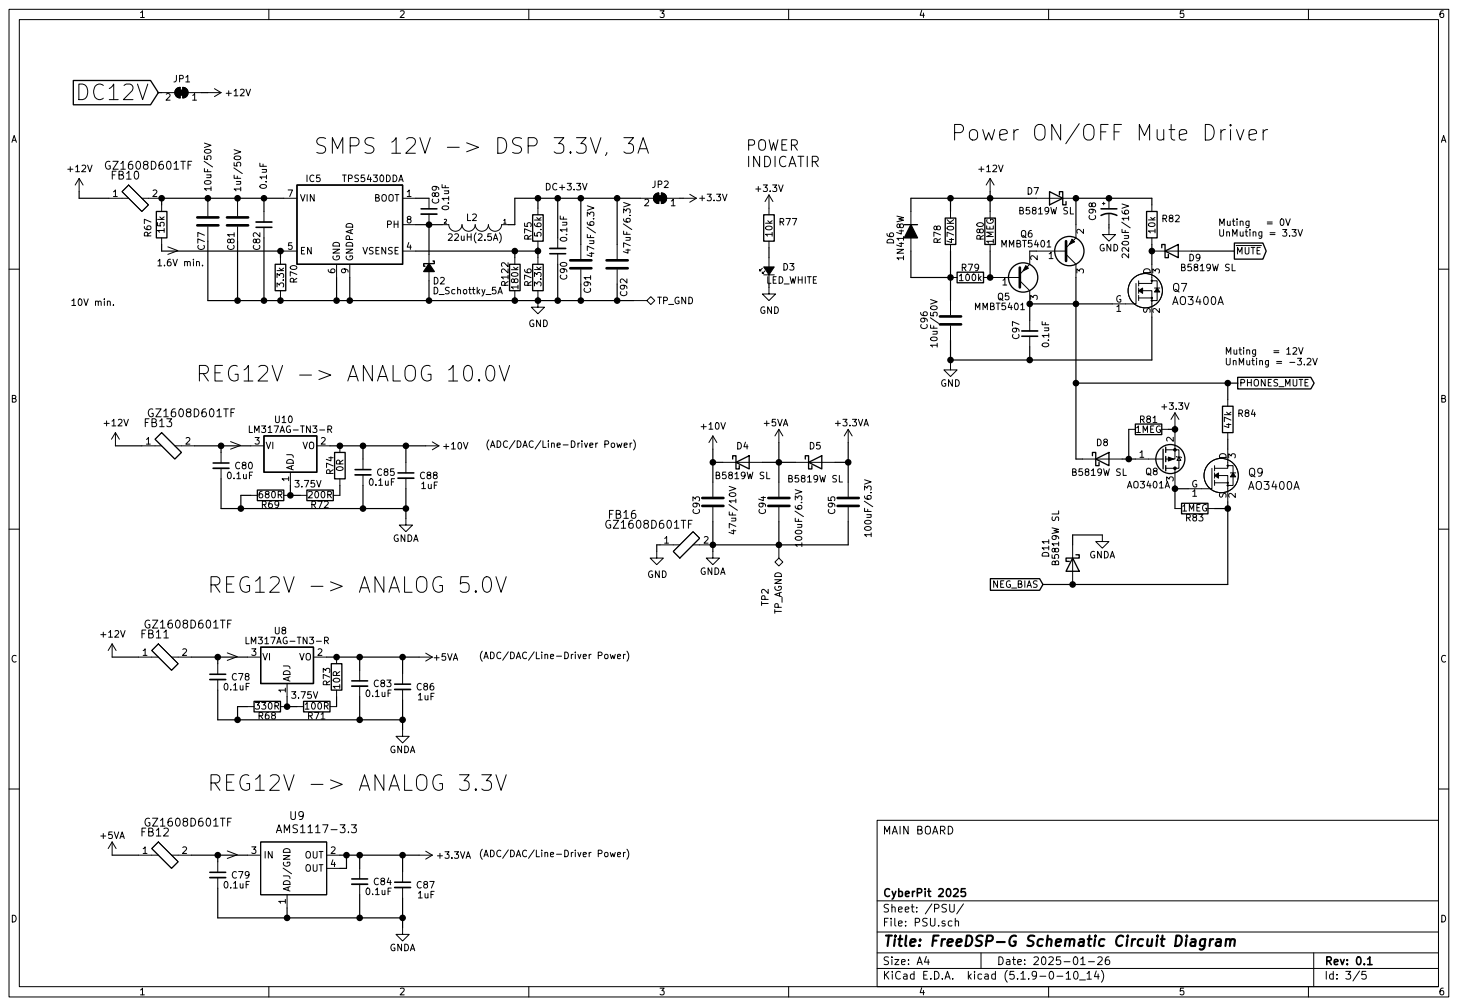
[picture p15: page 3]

Power ON/OFF Mute Driver

(ADC/DAC/Line-Driver Power)

File: PSU.sch Sheet: /PSU/ CyberPit 2025 MAIN BOARD

Id: 3/5 Title: FreeDSP-G Schematic Circuit Diagram

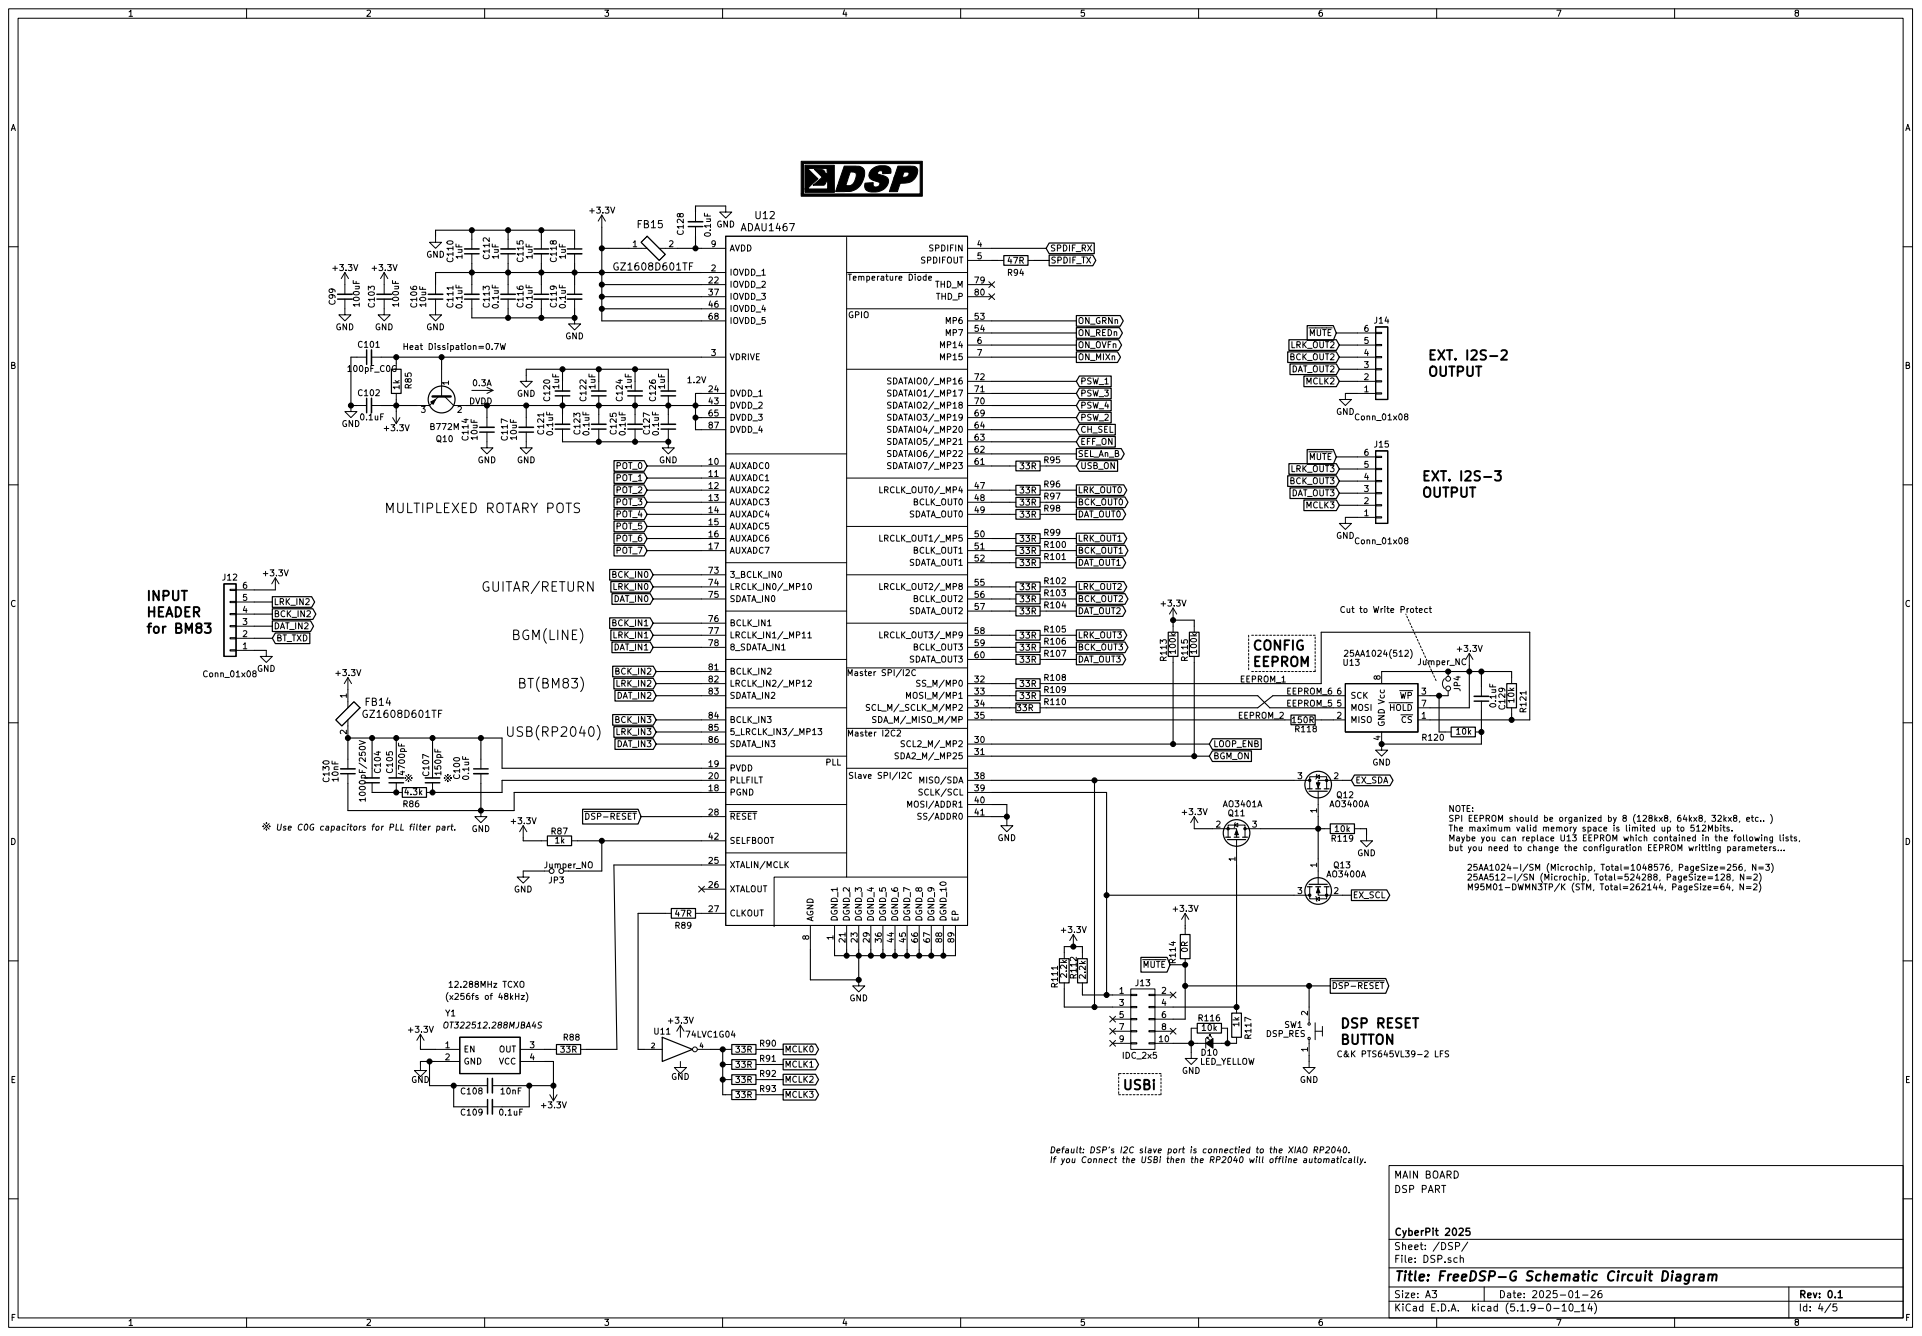
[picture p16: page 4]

4 MOSI 5 SCK 6 HOLD 7 Vcc 8 U13

The maximum valid memory space is limited up to 512Mbits.
Maybe you can replace U13 EEPROM which contained in the following lists,
but you need to change the configuration EEPROM writting parameters

25AA1024-I/SM (Microchip, Total=1048576, PageSize=256, N=3)
25AA512-I/SN (Microchip, Total=524288, PageSize=128, N=2)
M95M01-DWMN3TP/K (STM, Total=262144, PageSize=64, N=2)

Default: DSPs I2C slave port is connectied to the XIAO RP2040.
If you Connect the USBi then the RP2040 will offline automatically.

File: DSP.sch Sheet: /DSP/ CyberPit 2025 DSP PART MAIN BOARD

Id: 4/5 Title: FreeDSP-G Schematic Circuit Diagram

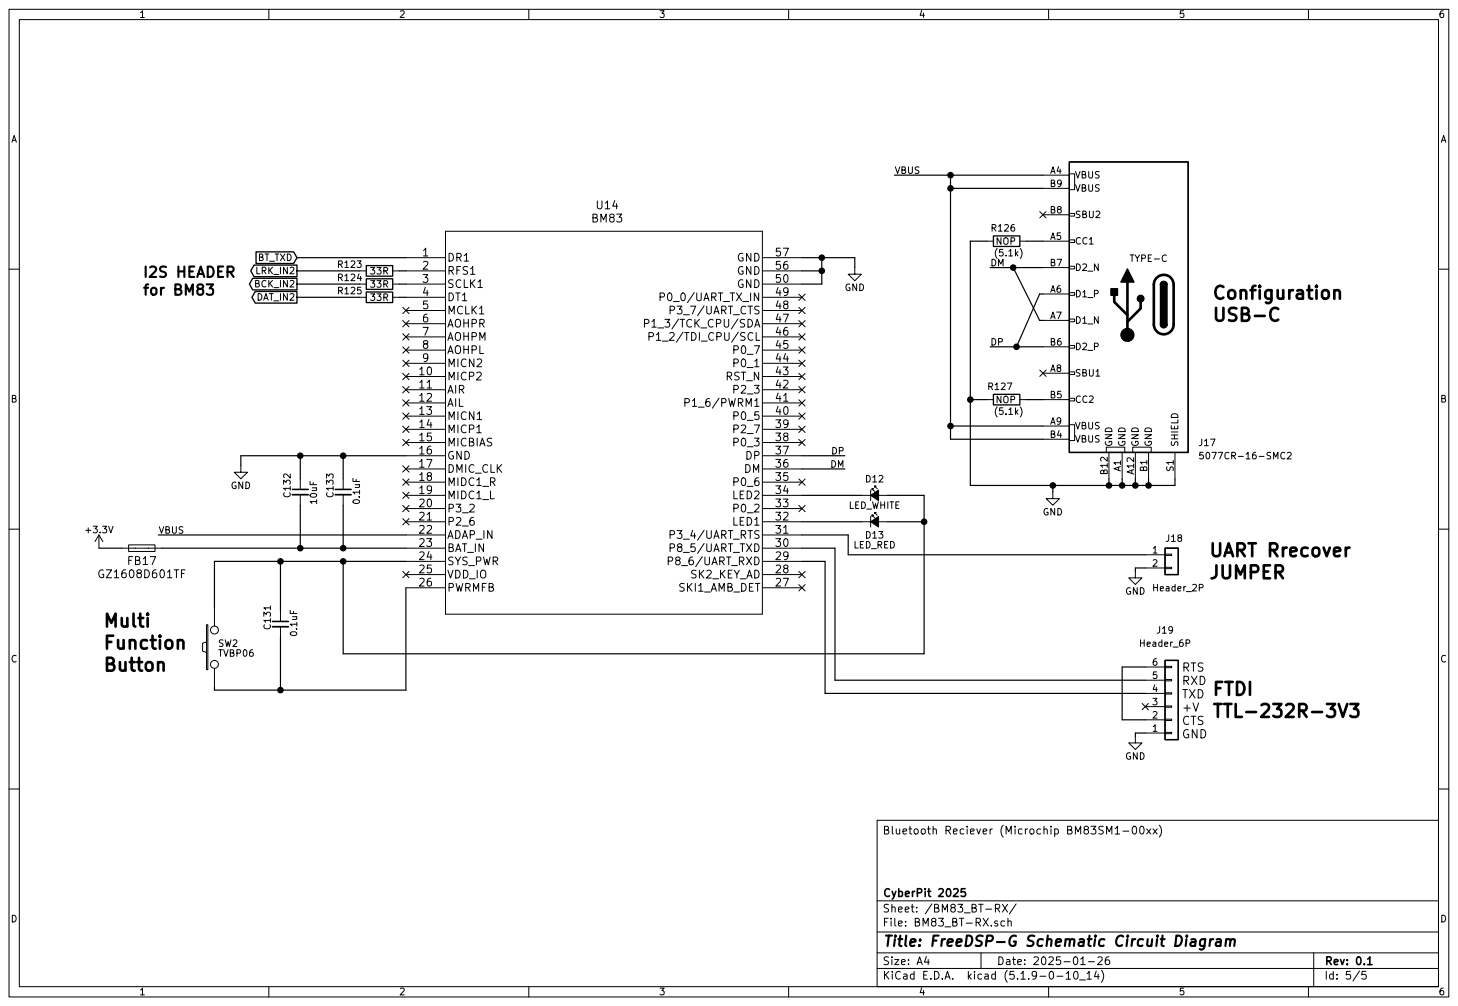
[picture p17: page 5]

CyberPit 2025
Sheet: /BM83_BT-RX/
File: BM83_BT-RX.sch
Id: 5/5 Title: FreeDSP-G Schematic Circuit Diagram

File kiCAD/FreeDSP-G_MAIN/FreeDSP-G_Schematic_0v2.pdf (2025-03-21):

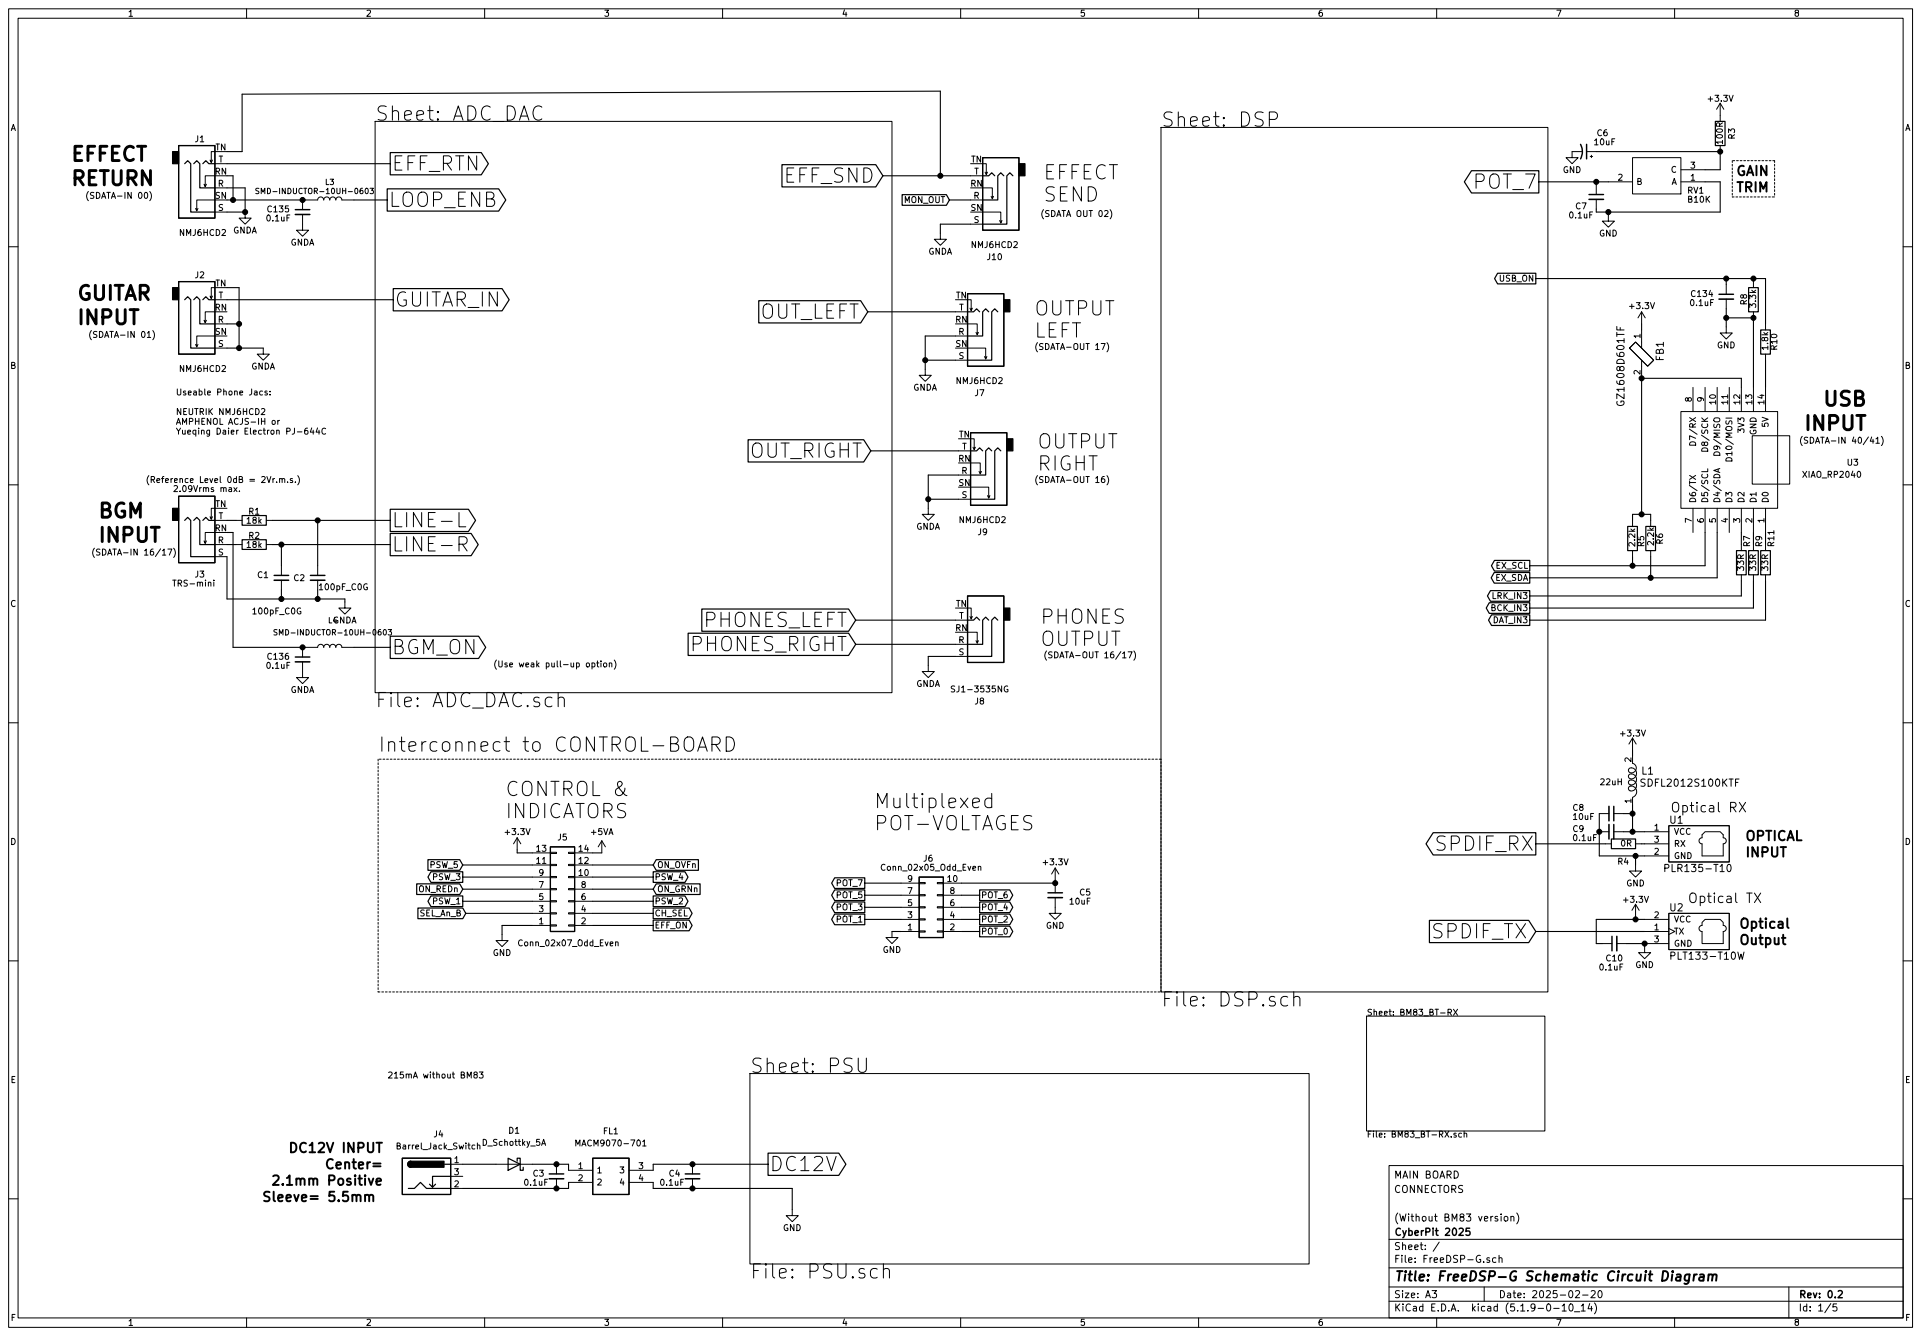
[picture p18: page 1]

Useable Phone Jacs: NEUTRIK NMJ6HCD2 AMPHENOL ACJS-IH or Yueqing Daier Electron PJ-644C

(Use weak pull-up option)

File: ADC_DAC.sch
Interconnect to CONTROL-BOARD

(Without BM83 version) CONNECTORS MAIN BOARD

File: FreeDSP-G.sch Sheet: / CyberPit 2025

Id: 1/5 Title: FreeDSP-G Schematic Circuit Diagram

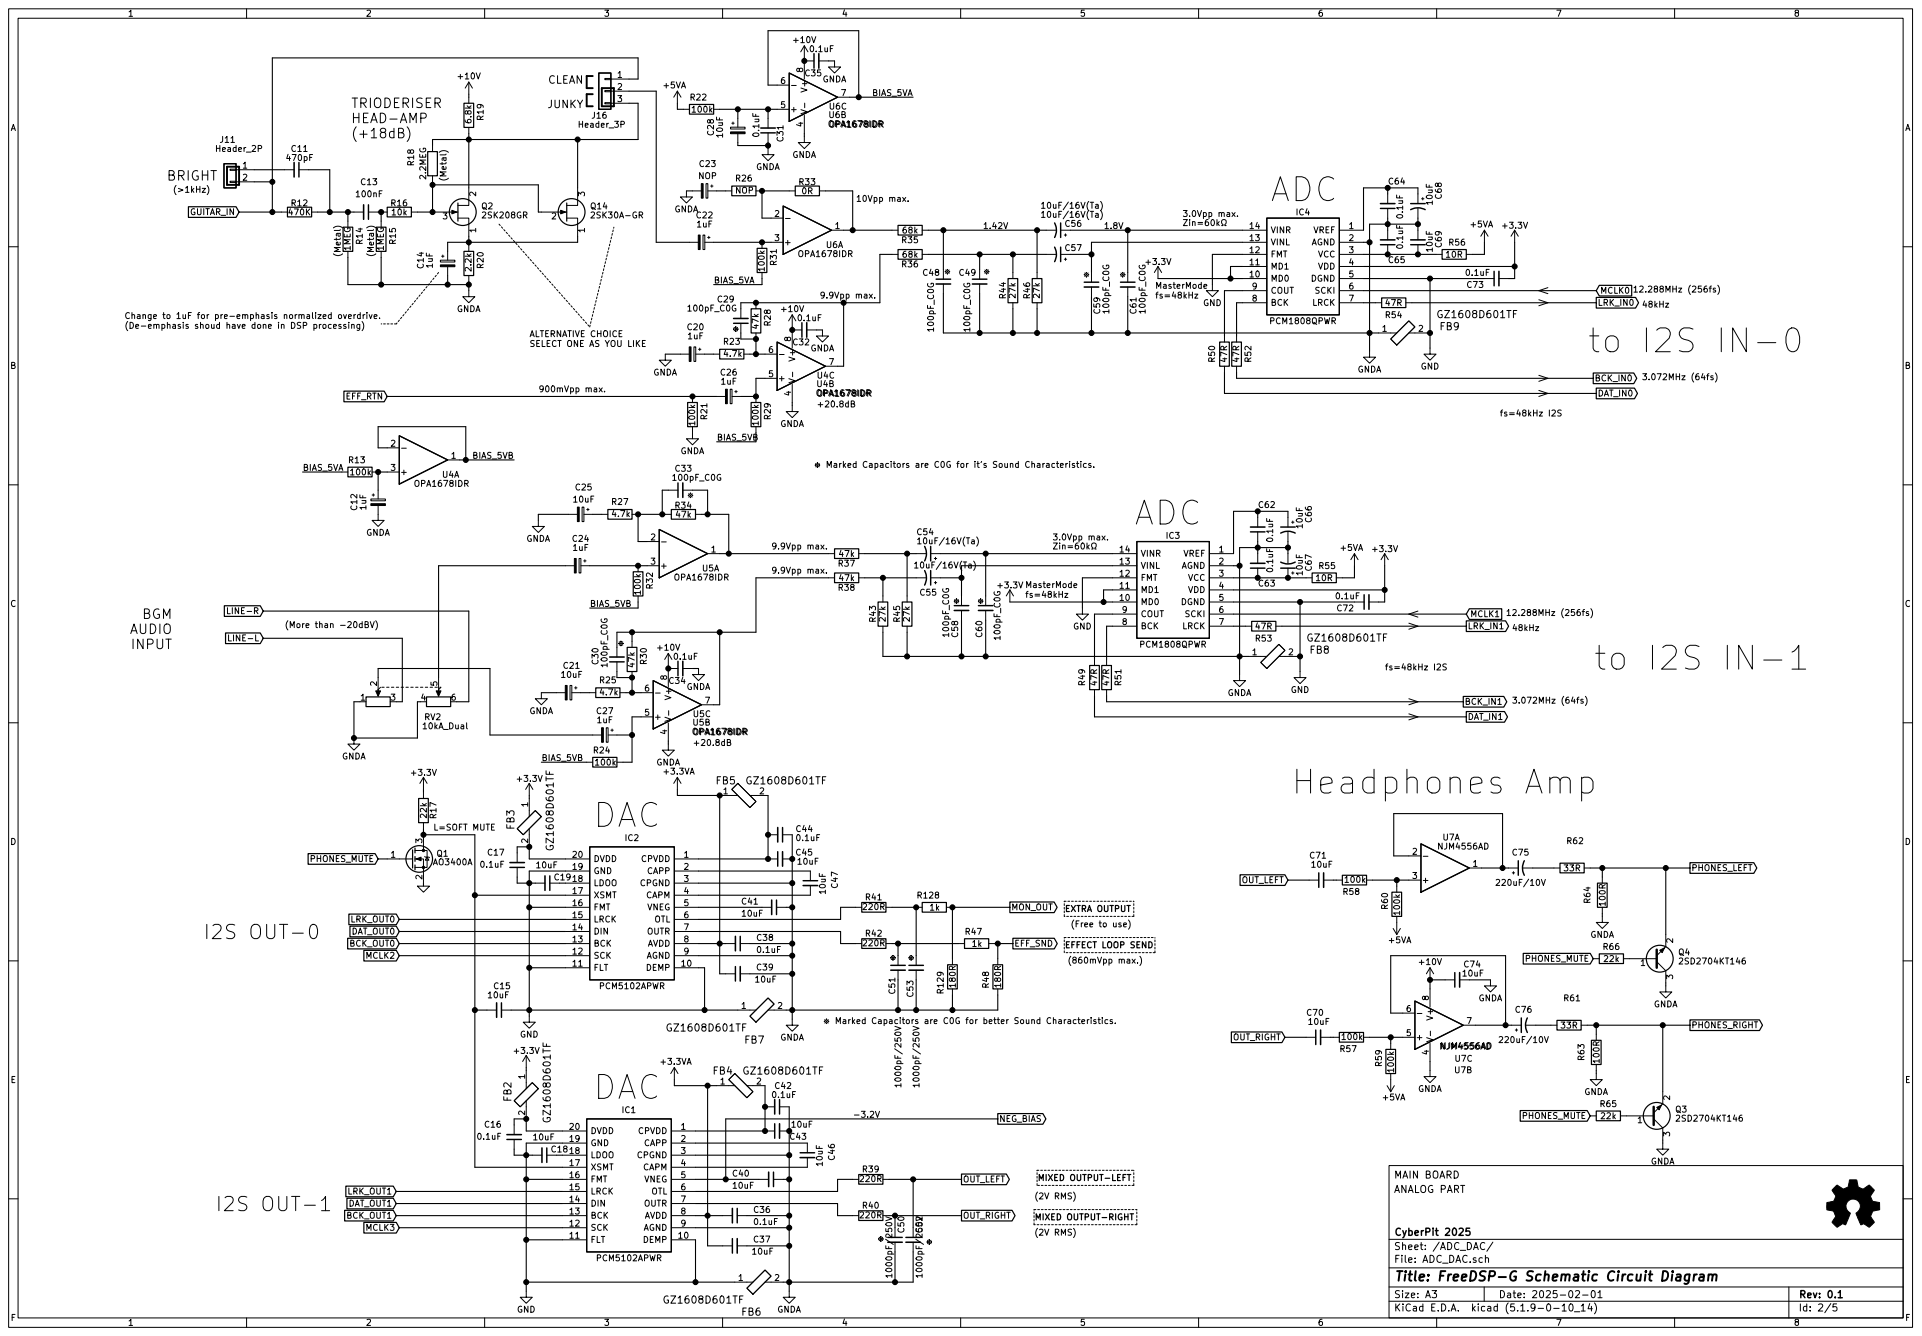
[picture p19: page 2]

Change to 1uF for pre-emphasis normalized overdrive.
(De-emphasis shoud have done in DSP processing)

ALTERNATIVE CHOICE
SELECT ONE AS YOU LIKE

Marked Capacitors are C0G for its Sound Characteristics.

12.288MHz (256fs) 48kHz MIXED OUTPUT-RIGHT MIXED OUTPUT-LEFT

(860mVpp max.) EFFECT LOOP SEND

Marked Capacitors are C0G for better Sound Characteristics.

CyberPit 2025 ANALOG PART MAIN BOARD

Sheet: /ADC_DAC/
File: ADC_DAC.sch
Id: 2/5 Title: FreeDSP-G Schematic Circuit Diagram


Power ON/OFF Mute Driver

(ADC/DAC/Line-Driver Power)

File: PSU.sch Sheet: /PSU/ CyberPit 2025 MAIN BOARD

Id: 3/5 Title: FreeDSP-G Schematic Circuit Diagram


Cut to Write Protect CONFIG

4 MOSI 5 SCK 6 HOLD 7 Vcc 8 U13

The maximum valid memory space is limited up to 512Mbits.
Maybe you can replace U13 EEPROM which contained in the following lists,
but you need to change the configuration EEPROM writting parameters

25AA1024-I/SM (Microchip, Total=1048576, PageSize=256, N=3)
25AA512-I/SN (Microchip, Total=524288, PageSize=128, N=2)
M95M01-DWMN3TP/K (STM, Total=262144, PageSize=64, N=2)

Default: DSPs I2C slave port is connectied to the XIAO RP2040.
If you Connect the USBi then the RP2040 will offline automatically.

File: DSP.sch Sheet: /DSP/ CyberPit 2025 DSP PART MAIN BOARD

Id: 4/5 Title: FreeDSP-G Schematic Circuit Diagram


CyberPit 2025
Sheet: /BM83_BT-RX/
File: BM83_BT-RX.sch
Id: 5/5 Title: FreeDSP-G Schematic Circuit Diagram

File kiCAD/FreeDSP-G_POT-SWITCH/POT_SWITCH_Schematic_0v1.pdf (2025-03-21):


6 SW1 PUSH-SWITCH-2mm-DPDT GNDD
UNLOCK

IF YOU WANT TO READ POTS SIMULTINEOUSLY MOVE the R1 to R2 and control the HC4053 by DSPs GPIO,

File: POT_SWITCH.sch Sheet: / CyberPit 2024-2025

Id: 1/1 Title: FreeDSP-G Schematic Circuit Diagram




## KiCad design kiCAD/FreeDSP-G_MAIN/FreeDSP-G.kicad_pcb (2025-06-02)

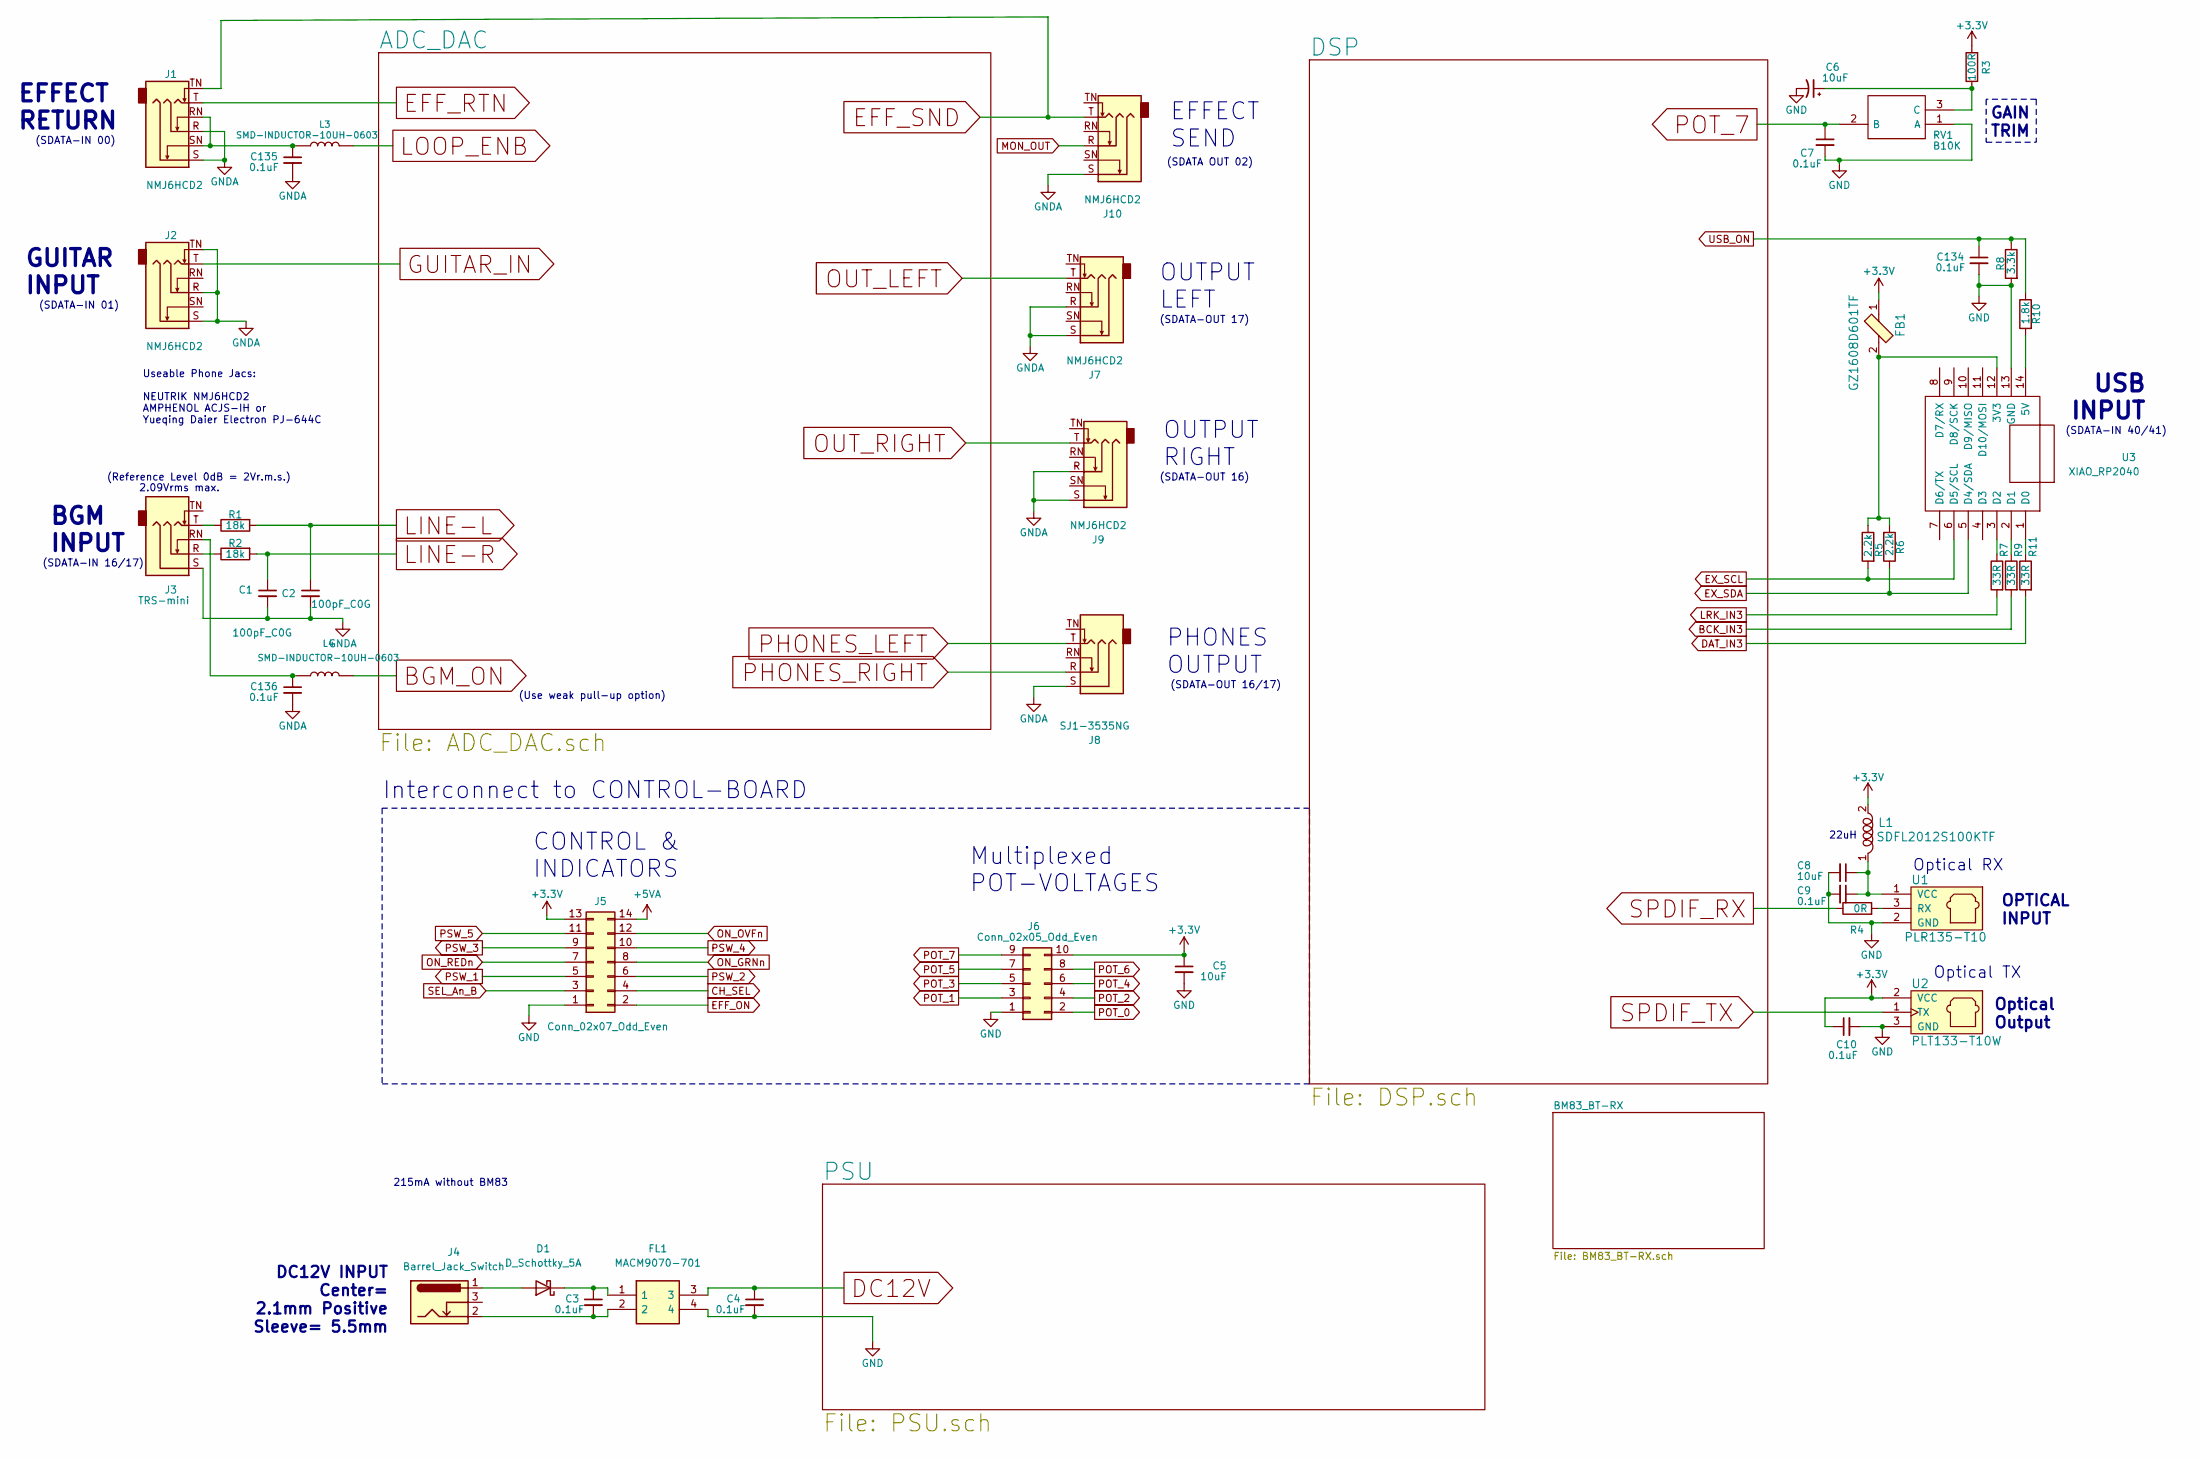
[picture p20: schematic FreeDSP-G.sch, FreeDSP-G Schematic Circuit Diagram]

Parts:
C1, C2: 100pF_C0G; C_0603_1608Metric_Pad1.08x0.95mm_HandSolder
C3, C4, C7, C9, C10, C134, C135, C136: 0.1uF; C_0603_1608Metric_Pad1.08x0.95mm_HandSolder
C5, C6, C8: 10uF; C_0805_2012Metric
D1: D_Schottky_5A; D_SMA
FB1: GZ1608D601TF; L_0603_1608Metric_Pad1.05x0.95mm_HandSolder; MPN BLM18AG601SN1D; Digi-Key_PN 490-1014-1-ND
FL1: MACM9070-701; ACM9070; Manufacturer_Part_Number ACM9070-701-2PL-TL01
J1, J2, J7, J9, J10: NMJ6HCD2; PJ-644C_NMJ6HCD2_ACJS-IH
J3: TRS-mini; Jack_3.5mm_CUI_SJ1-3535NG_Horizontal
J4: Barrel_Jack_Switch; BarrelJack_CUI_PJ-102AH_Horizontal
J5: Conn_02x07_Odd_Even; IDC-Header_2x07_P2.54mm_Horizontal
J6: Conn_02x05_Odd_Even; IDC-Header_2x05_P2.54mm_Horizontal
J8: SJ1-3535NG; Jack_3.5mm_CUI_SJ1-3535NG_Horizontal
L1: SDFL2012S100KTF; L_0805_2012Metric_Pad1.15x1.40mm_HandSolder; MPN 82473C; Digi-Key_PN 811-2477-1-ND
L3, L4: SMD-INDUCTOR-10UH-0603; L_0603_1608Metric; MPN SDFL1608S100KTF
R1, R2: 18k; R_0603_1608Metric_Pad0.98x0.95mm_HandSolder
R3: 100R; R_0603_1608Metric_Pad0.98x0.95mm_HandSolder
R4: 0R; R_0603_1608Metric_Pad0.98x0.95mm_HandSolder
R5, R6: 2.2k; R_0603_1608Metric_Pad0.98x0.95mm_HandSolder
R7, R9, R11: 33R; R_0603_1608Metric_Pad0.98x0.95mm_HandSolder
R8: 3.3k; R_0603_1608Metric_Pad0.98x0.95mm_HandSolder
R10: 1.8k; R_0603_1608Metric_Pad0.98x0.95mm_HandSolder
RV1: B10K; Potentiometer_Vishay_T73XX_Horizontal
U1: PLR135-T10
U2: PLT133-T10W
U3: XIAO_RP2040

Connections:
+3V3: C5.1, C10.1, FB1.1, J5.13, J6.10, L1.2, R3.2, U2.2 (VCC); also elsewhere on the board
+5VA: J5.14; also elsewhere on the board
BCK_IN3: R9.2; also elsewhere on the board
BGM_ON: L4.2; also elsewhere on the board
CH_SEL: J5.4; also elsewhere on the board
DAT_IN3: R11.2; also elsewhere on the board
DC12V: C4.1, FL1.3; also elsewhere on the board
EFF_ON: J5.2; also elsewhere on the board
EFF_RTN: J1.T; also elsewhere on the board
EFF_SND: J1.TN, J10.T; also elsewhere on the board
EX_SCL: R5.2, U3.6 (D5/SCL); also elsewhere on the board
EX_SDA: R6.1, U3.5 (D4/SDA); also elsewhere on the board
GND: C4.2, C5.2, C6.2, C7.2, C8.2, C9.2, C10.2, C134.2, FL1.4, J5.1, J6.1, R8.2, RV1.1 (A), U1.2 (GND), U2.3 (GND), U3.13 (GND); also elsewhere on the board
GNDA: C1.2, C2.2, C135.2, C136.2, J1.R, J1.S, J2.R, J2.S, J2.TN, J3.S, J7.R, J7.S, J8.S, J9.R, J9.S, J10.S; also elsewhere on the board
GUITAR_IN: J2.T; also elsewhere on the board
LINE-L: C2.1, R1.2; also elsewhere on the board
LINE-R: C1.1, R2.2; also elsewhere on the board
LOOP_ENB: L3.2; also elsewhere on the board
LRK_IN3: R7.2; also elsewhere on the board
MON_OUT: J10.R; also elsewhere on the board
unnamed: C3.1, D1.1 (K), FL1.1
unnamed: C3.2, FL1.2, J4.2
unnamed: C6.1, R3.1, RV1.3 (C)
unnamed: C8.1, C9.1, L1.1, U1.1 (VCC)
unnamed: C135.1, J1.RN, J1.SN, L3.1
unnamed: C136.1, J3.RN, L4.1
unnamed: D1.2 (A), J4.1
unnamed: FB1.2, R5.1, R6.2, U3.12 (3V3)
unnamed: J3.R, R2.1
unnamed: J3.T, R1.1
unnamed: R4.2, U1.3 (RX)
unnamed: R7.1, U3.3 (D2)
unnamed: R9.1, U3.2 (D1)
unnamed: R10.2, U3.14 (5V)
unnamed: R11.1, U3.1 (D0)
ON_GRNn: J5.8; also elsewhere on the board
ON_OVFn: J5.12; also elsewhere on the board
ON_REDn: J5.7; also elsewhere on the board
OUT_LEFT: J7.T; also elsewhere on the board
OUT_RIGHT: J9.T; also elsewhere on the board
PHONES_LEFT: J8.T; also elsewhere on the board
PHONES_RIGHT: J8.R; also elsewhere on the board
POT_0: J6.2; also elsewhere on the board
POT_1: J6.3; also elsewhere on the board
POT_2: J6.4; also elsewhere on the board
POT_3: J6.5; also elsewhere on the board
POT_4: J6.6; also elsewhere on the board
POT_5: J6.7; also elsewhere on the board
POT_6: J6.8; also elsewhere on the board
POT_7: C7.1, J6.9, RV1.2 (B); also elsewhere on the board
PSW_1: J5.5; also elsewhere on the board
PSW_2: J5.6; also elsewhere on the board
PSW_3: J5.9; also elsewhere on the board
PSW_4: J5.10; also elsewhere on the board
PSW_5: J5.11; also elsewhere on the board
SEL_An_B: J5.3; also elsewhere on the board
SPDIF_RX: R4.1; also elsewhere on the board
SPDIF_TX: U2.1 (TX); also elsewhere on the board
USB_ON: C134.1, R8.1, R10.1; also elsewhere on the board

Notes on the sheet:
DC12V INPUT Center= 2.1mm Positive Sleeve= 5.5mm
GUITAR INPUT
EFFECT RETURN
EFFECT SEND
PHONES OUTPUT
BGM INPUT
OUTPUT LEFT
OUTPUT RIGHT
(Reference Level 0dB = 2Vr.m.s.)
2.09Vrms max.
USB INPUT
CONTROL & INDICATORS
Multiplexed POT-VOLTAGES
Interconnect to CONTROL-BOARD
Optical Output
OPTICAL INPUT
22uH
Optical RX
Optical TX
GAIN TRIM
(Use weak pull-up option)
Useable Phone Jacs: NEUTRIK NMJ6HCD2 AMPHENOL ACJS-IH or Yueqing Daier Electron PJ-644C
215mA without BM83
(SDATA-IN 01)
(SDATA-IN 00)
(SDATA-IN 16/17)
(SDATA-IN 40/41)
(SDATA OUT 02)
(SDATA-OUT 17)
(SDATA-OUT 16)
(SDATA-OUT 16/17)

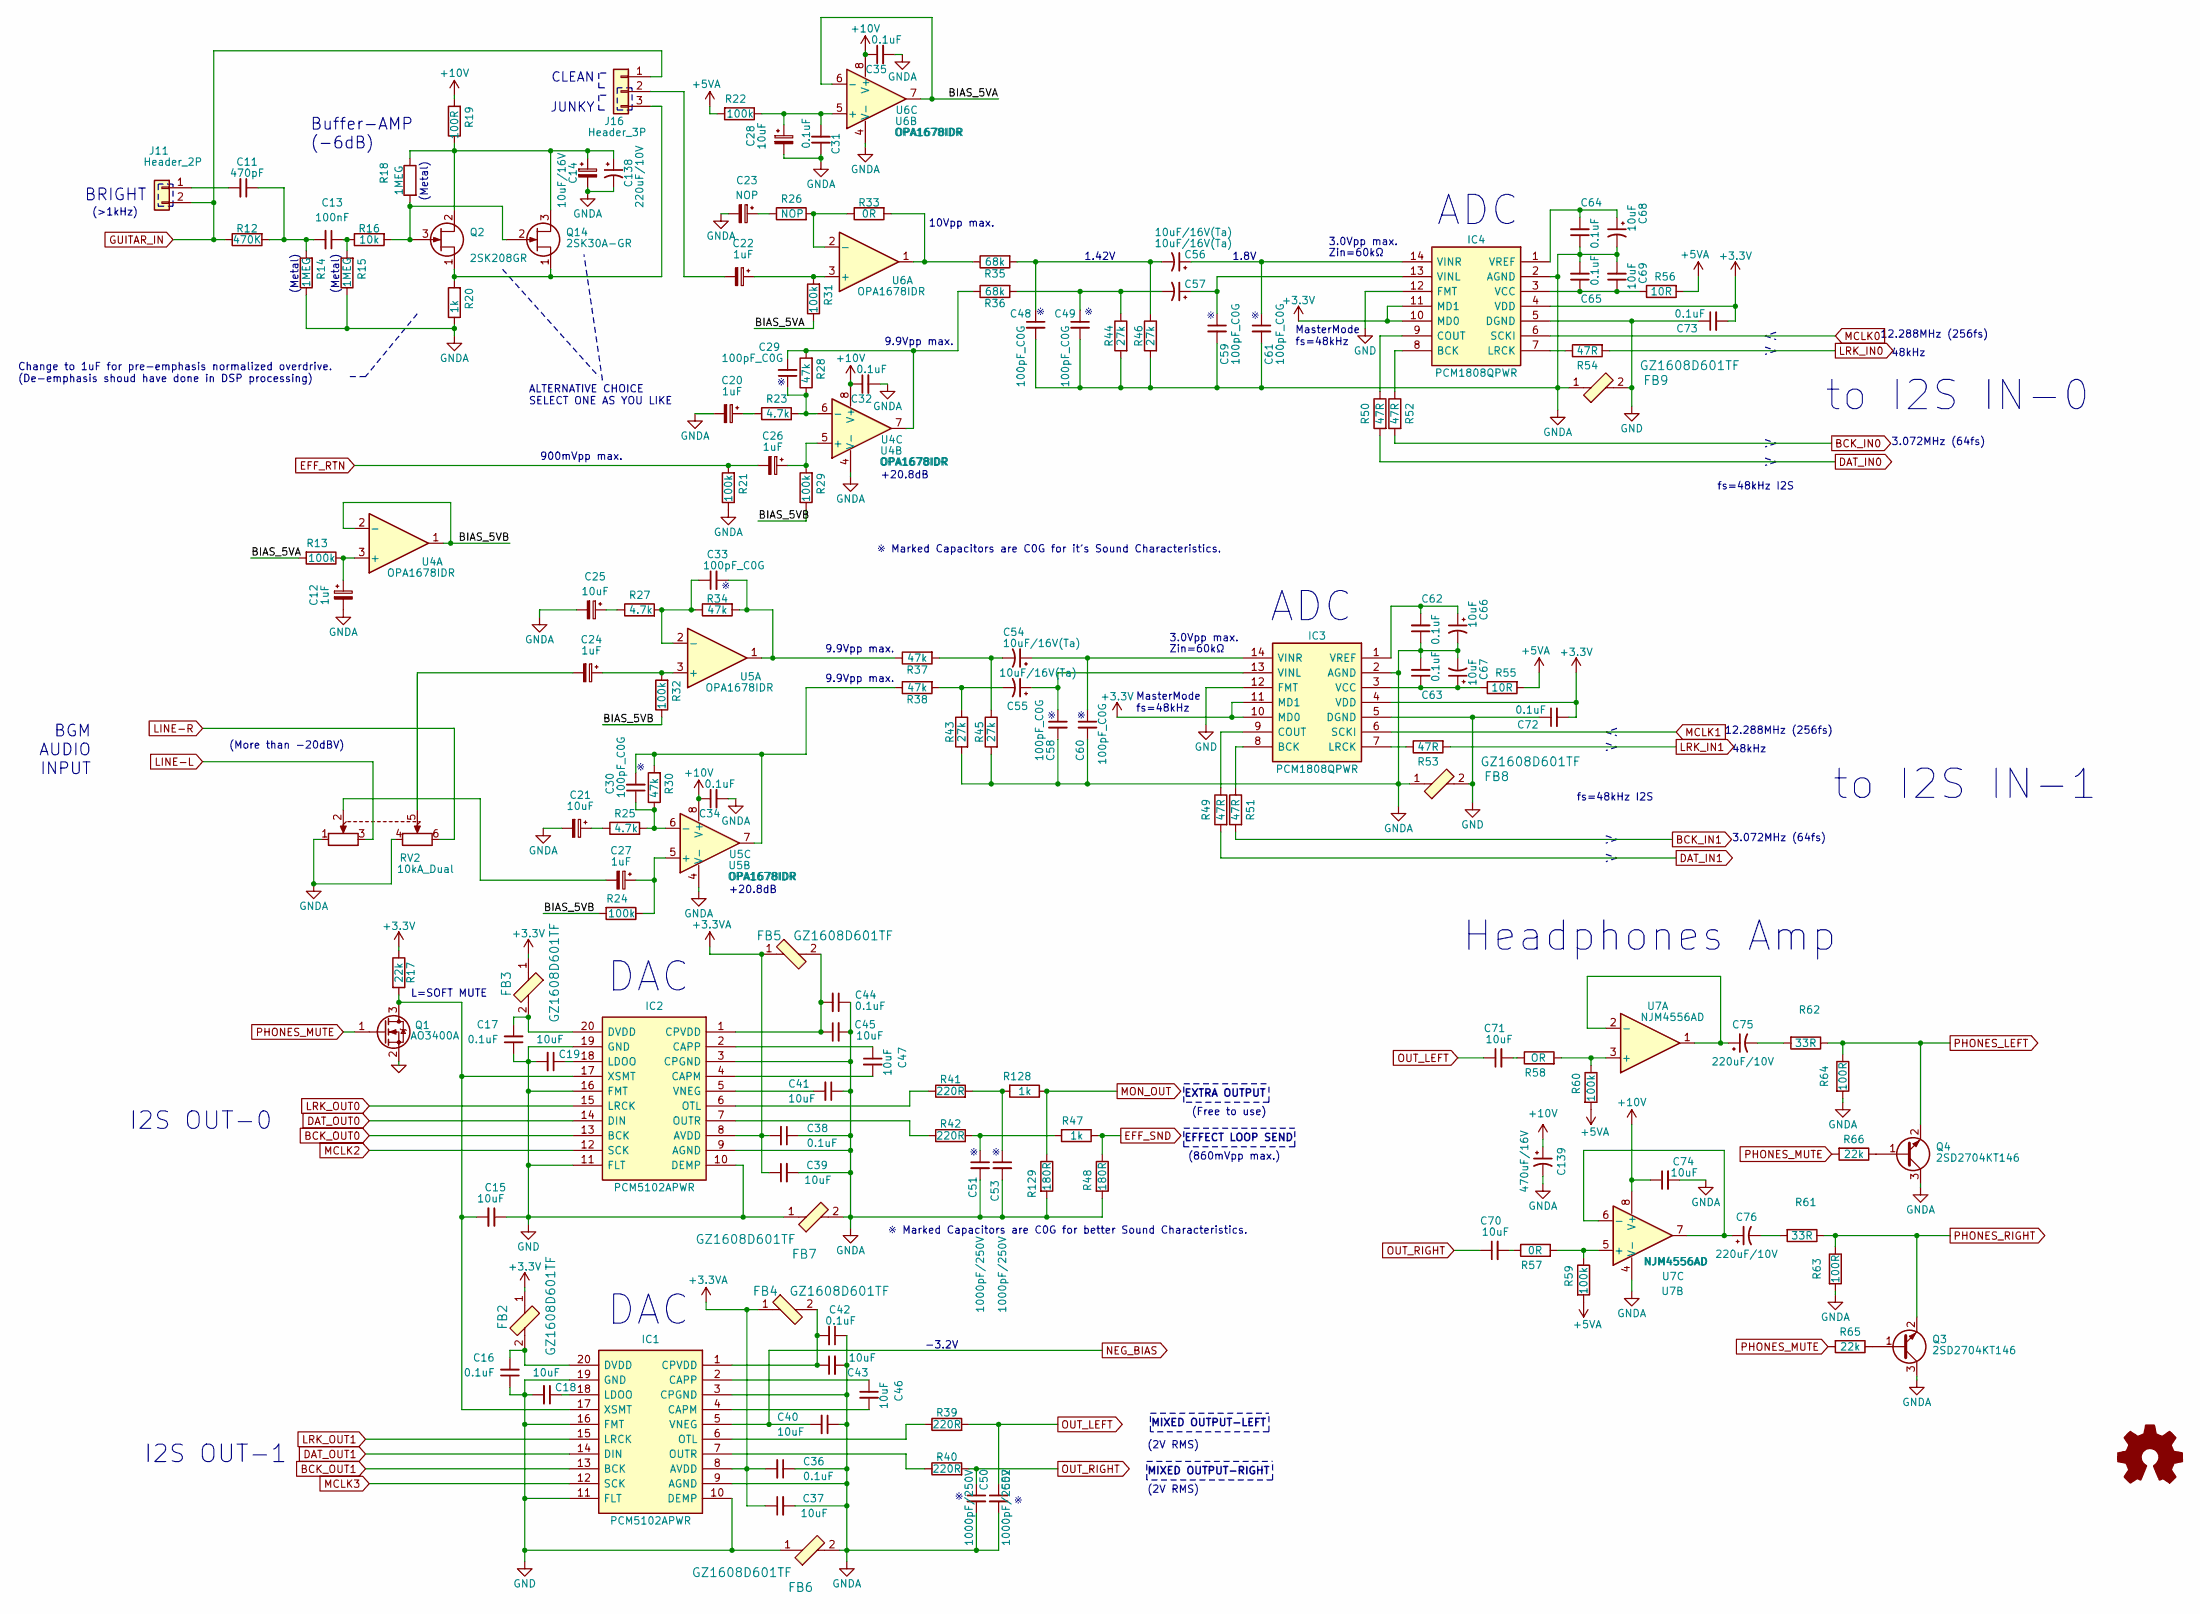
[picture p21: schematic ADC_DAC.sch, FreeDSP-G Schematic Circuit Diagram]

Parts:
C11: 470pF; C_0603_1608Metric_Pad1.08x0.95mm_HandSolder
C12, C20, C22, C24, C26, C27: 1uF; C_0805_2012Metric
C13: 100nF; C_0805_2012Metric
C14: 10uF/16V; CP_EIA-2012-12_Kemet-R
C15, C18, C19, C21, C25, C28, C37, C39, C40, C41, C43, C45, C46, C47, C66, C67, C68, C69, C70, C71, C74: 10uF; C_0805_2012Metric
C16, C17, C31, C32, C34, C35, C36, C38, C42, C44, C62, C63, C64, C65, C72, C73: 0.1uF; C_0603_1608Metric_Pad1.08x0.95mm_HandSolder
C23: NOP; C_0805_2012Metric
C29, C30, C33, C48, C49, C58, C59, C60, C61: 100pF_C0G; C_0603_1608Metric_Pad1.08x0.95mm_HandSolder
C50, C51, C52, C53: 1000pF/250V; C_0805_2012Metric
C54, C55, C56, C57: 10uF/16V(Ta); CP_Tantalum_Case-A_EIA-3216-18_Reflow
C75, C76, C138: 220uF/10V; CP_Radial_D7.5mm_P2.50mm
C139: 470uF/16V; CP_Radial_D10.0mm_P2.50mm_P5.00mm
FB2, FB3, FB4, FB5: GZ1608D601TF; L_0603_1608Metric_Pad1.05x0.95mm_HandSolder; MPN BLM18AG601SN1D; Digi-Key_PN 490-1014-1-ND
FB6, FB7, FB8, FB9: GZ1608D601TF; L_0603_1608Metric_Pad1.05x0.95mm_HandSolder; MPN BLM21PG331SN1D; Digi-Key_PN 490-5988-1-ND
IC1, IC2: PCM5102APWR; TSSOP-20_4.4x6.5mm_P0.65mm; Manufacturer_Part_Number PCM5102APWR
IC3, IC4: PCM1808QPWR; PCM1808QPWRQ1; Manufacturer_Part_Number PCM1808QPWRQ1
J11: Header_2P; PinHeader_1x02_P2.54mm_Vertical
J16: Header_3P; PinHeader_1x03_P2.54mm_Vertical
LOGO1: Logo_Open_Hardware_Small; LOGO_FREEDSP_600dpi
Q1: AO3400A; SOT-23
Q2: 2SK208GR; SC-59
Q3, Q4: 2SD2704KT146; SOT-23
Q14: 2SK30A-GR; TO-92_Inline_Narrow_Oval
R12: 470K; R_0603_1608Metric_Pad0.98x0.95mm_HandSolder
R13, R21, R22, R24, R29, R31, R32, R59, R60: 100k; R_0603_1608Metric_Pad0.98x0.95mm_HandSolder
R14, R15, R18: 1MEG; R_0603_1608Metric_Pad0.98x0.95mm_HandSolder
R16: 10k; R_0603_1608Metric_Pad0.98x0.95mm_HandSolder
R17, R65, R66: 22k; R_0603_1608Metric_Pad0.98x0.95mm_HandSolder
R19, R63, R64: 100R; R_0603_1608Metric_Pad0.98x0.95mm_HandSolder
R20, R47, R128: 1k; R_0603_1608Metric_Pad0.98x0.95mm_HandSolder
R23, R25, R27: 4.7k; R_0603_1608Metric_Pad0.98x0.95mm_HandSolder
R26: NOP; R_0603_1608Metric_Pad0.98x0.95mm_HandSolder
R28, R30, R34, R37, R38: 47k; R_0603_1608Metric_Pad0.98x0.95mm_HandSolder
R33, R57: 0R; R_0603_1608Metric_Pad0.98x0.95mm_HandSolder
R35, R36: 68k; R_0603_1608Metric_Pad0.98x0.95mm_HandSolder
R39, R40, R41, R42: 220R; R_0603_1608Metric_Pad0.98x0.95mm_HandSolder
R43, R44, R45, R46: 27k; R_0603_1608Metric_Pad0.98x0.95mm_HandSolder
R48, R129: 180R; R_0603_1608Metric_Pad0.98x0.95mm_HandSolder
R49, R50, R51, R52, R53, R54: 47R; R_0603_1608Metric_Pad0.98x0.95mm_HandSolder
R55, R56: 10R; R_0603_1608Metric_Pad0.98x0.95mm_HandSolder
R58: OR; R_0603_1608Metric_Pad0.98x0.95mm_HandSolder
R61, R62: 33R; R_0603_1608Metric_Pad0.98x0.95mm_HandSolder
RV2: 10kA_Dual; RK09712
U4, U5, U6: OPA1678IDR; SOIC-8_3.9x4.9mm_P1.27mm
U7: NJM4556AD; DIP-8_W7.62mm

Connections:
+3.3VA: C36.2, C37.1, C38.2, C39.1, FB4.1, FB5.1, IC1.8 (AVDD), IC2.8 (AVDD); also elsewhere on the board
+3V3: C72.2, C73.2, FB2.1, FB3.1, IC3.4 (VDD), IC3.10 (MD0), IC3.11 (MD1), IC4.4 (VDD), IC4.10 (MD0), IC4.11 (MD1), R17.1; also elsewhere on the board
+5VA: R22.2, R55.2, R56.2, R59.2, R60.2; also elsewhere on the board
+10V: C32.1, C34.1, C35.1, C74.1, C139.1, R19.2, U4.8 (V+), U5.8 (V+), U6.8 (V+), U7.8 (V+); also elsewhere on the board
/ADC_DAC/BIAS_5VA: R13.2, R31.1, U6.6 (-), U6.7
/ADC_DAC/BIAS_5VB: R24.2, R29.1, R32.1, U4.1, U4.2 (-)
BCK_IN0: R52.2; also elsewhere on the board
BCK_IN1: R51.2; also elsewhere on the board
BCK_OUT0: IC2.13 (BCK); also elsewhere on the board
BCK_OUT1: IC1.13 (BCK); also elsewhere on the board
DAT_IN0: R50.2; also elsewhere on the board
DAT_IN1: R49.2; also elsewhere on the board
DAT_OUT0: IC2.14 (DIN); also elsewhere on the board
DAT_OUT1: IC1.14 (DIN); also elsewhere on the board
EFF_RTN: C26.2, R21.2; also elsewhere on the board
EFF_SND: R47.1, R48.1; also elsewhere on the board
GND: C15.1, C16.1, C17.1, C18.2, C19.2, C72.1, C73.1, FB6.1, FB7.1, FB8.2, FB9.2, IC1.10 (DEMP), IC1.11 (FLT), IC1.16 (FMT), IC1.19 (GND), IC2.10 (DEMP), IC2.11 (FLT), IC2.16 (FMT), IC2.19 (GND), IC3.5 (DGND), IC3.12 (FMT), IC4.5 (DGND), IC4.12 (FMT), Q1.2 (S); also elsewhere on the board
GNDA: C12.2, C14.2, C20.2, C21.2, C23.2, C25.2, C28.2, C31.1, C32.2, C34.2, C35.2, C36.1, C37.2, C38.1, C39.2, C40.1, C41.1, C42.1, C43.2, C44.1, C45.2, C48.2, C49.2, C50.2, C51.2, C52.2, C53.2, C58.2, C59.2, C60.2, C61.2, C62.1, C63.2, C64.1, C65.2, C66.2, C67.2, C68.2, C69.2, C74.2, C138.2, C139.2, FB6.2, FB7.2, FB8.1, FB9.1, IC1.3 (CPGND), IC1.9 (AGND), IC2.3 (CPGND), IC2.9 (AGND), IC3.2 (AGND), IC4.2 (AGND), Q3.3 (C), Q4.3 (C), R14.1, R15.1, R20.1, R21.1, R43.2, R44.2, R45.2, R46.2, R48.2, R63.2, R64.2, R129.2, RV2.1, RV2.4, U4.4 (V-), U5.4 (V-), U6.4 (V-), U7.4 (V-); also elsewhere on the board
GUITAR_IN: J11.2, J16.1, R12.1; also elsewhere on the board
LINE-L: RV2.3; also elsewhere on the board
LINE-R: RV2.6; also elsewhere on the board
LRK_IN0: R54.2; also elsewhere on the board
LRK_IN1: R53.2; also elsewhere on the board
LRK_OUT0: IC2.15 (LRCK); also elsewhere on the board
LRK_OUT1: IC1.15 (LRCK); also elsewhere on the board
MCLK0: IC4.6 (SCKI); also elsewhere on the board
MCLK1: IC3.6 (SCKI); also elsewhere on the board
MCLK2: IC2.12 (SCK); also elsewhere on the board
MCLK3: IC1.12 (SCK); also elsewhere on the board
MON_OUT: R128.1, R129.1; also elsewhere on the board
NEG_BIAS: C40.2, IC1.5 (VNEG); also elsewhere on the board
unnamed: C11.1, C13.2, R12.2, R14.2
unnamed: C11.2, J11.1
unnamed: C12.1, R13.1, U4.3 (+)
unnamed: C13.1, R15.2, R16.1
unnamed: C15.2, IC1.17 (XSMT), IC2.17 (XSMT), Q1.3 (D), R17.2
unnamed: C16.2, FB2.2, IC1.20 (DVDD)
unnamed: C17.2, FB3.2, IC2.20 (DVDD)
unnamed: C18.1, IC1.18 (LDOO)
unnamed: C19.1, IC2.18 (LDOO)
unnamed: C20.1, R23.1
unnamed: C21.1, R25.1
unnamed: C22.1, R31.2, U6.3 (+)
unnamed: C22.2, J16.2
unnamed: C23.1, R26.1
unnamed: C24.1, R32.2, U5.3 (+)
unnamed: C24.2, RV2.5
unnamed: C25.1, R27.1
unnamed: C26.1, R29.2, U4.5 (+)
unnamed: C27.1, R24.1, U5.5 (+)
unnamed: C27.2, RV2.2
unnamed: C28.1, C31.2, R22.1, U6.5 (+)
unnamed: C29.1, R23.2, R28.1, U4.6 (-)
unnamed: C29.2, R28.2, R36.1, U4.7
unnamed: C30.1, R25.2, R30.1, U5.6 (-)
unnamed: C30.2, R30.2, R38.1, U5.7
unnamed: C33.1, R27.2, R34.1, U5.2 (-)
unnamed: C33.2, R34.2, R37.1, U5.1
unnamed: C41.2, IC2.5 (VNEG)
unnamed: C42.2, C43.1, FB4.2, IC1.1 (CPVDD)
unnamed: C44.2, C45.1, FB5.2, IC2.1 (CPVDD)
unnamed: C46.1, IC1.2 (CAPP)
unnamed: C46.2, IC1.4 (CAPM)
unnamed: C47.1, IC2.2 (CAPP)
unnamed: C47.2, IC2.4 (CAPM)
unnamed: C48.1, C56.2, R35.2, R46.1
unnamed: C49.1, C57.2, R36.2, R44.1
unnamed: C51.1, R42.2, R47.2
unnamed: C53.1, R41.2, R128.2
unnamed: C54.1, C60.1, IC3.14 (VINR)
unnamed: C54.2, R37.2, R45.1
unnamed: C55.1, C58.1, IC3.13 (VINL)
unnamed: C55.2, R38.2, R43.1
unnamed: C56.1, C61.1, IC4.14 (VINR)
unnamed: C57.1, C59.1, IC4.13 (VINL)
unnamed: C62.2, C66.1, IC3.1 (VREF)
unnamed: C63.1, C67.1, IC3.3 (VCC), R55.1
unnamed: C64.2, C68.1, IC4.1 (VREF)
unnamed: C65.1, C69.1, IC4.3 (VCC), R56.1
unnamed: C70.2, R57.1
unnamed: C71.2, R58.1
unnamed: C75.1, U7.1, U7.2 (-)
unnamed: C75.2, R62.2
unnamed: C76.1, U7.6 (-), U7.7
unnamed: C76.2, R61.2
unnamed: C14.1, C138.1, Q2.2 (D), Q14.3 (D), R18.1, R19.1
unnamed: IC1.6 (OTL), R39.1
unnamed: IC1.7 (OUTR), R40.1
unnamed: IC2.6 (OTL), R41.1
unnamed: IC2.7 (OUTR), R42.1
unnamed: IC3.7 (LRCK), R53.1
unnamed: IC3.8 (BCK), R51.1
unnamed: IC3.9 (COUT), R49.1
unnamed: IC4.7 (LRCK), R54.1
unnamed: IC4.8 (BCK), R52.1
unnamed: IC4.9 (COUT), R50.1
unnamed: J16.3, Q2.1 (S), Q14.1 (S), R20.2
unnamed: Q3.1 (B), R65.1
unnamed: Q4.1 (B), R66.1
unnamed: Q2.3 (G), Q14.2 (G), R16.2, R18.2
unnamed: R26.2, R33.1, U6.2 (-)
unnamed: R33.2, R35.1, U6.1
unnamed: R57.2, R59.1, U7.5 (+)
unnamed: R58.2, R60.1, U7.3 (+)
OUT_LEFT: C52.1, C71.1, R39.2; also elsewhere on the board
OUT_RIGHT: C50.1, C70.1, R40.2; also elsewhere on the board
PHONES_LEFT: Q4.2 (E), R62.1, R64.1; also elsewhere on the board
PHONES_MUTE: Q1.1 (G), R65.2, R66.2; also elsewhere on the board
PHONES_RIGHT: Q3.2 (E), R61.1, R63.1; also elsewhere on the board

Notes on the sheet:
Buffer-AMP (-6dB)
3.0Vpp max.
Zin=60kΩ
10Vpp max.
fs=48kHz I2S
12.288MHz (256fs)
48kHz
BGM AUDIO INPUT
MasterMode fs=48kHz
9.9Vpp max.
+20.8dB
900mVpp max.
(Metal)
3.072MHz (64fs)
BRIGHT
I2S OUT-0
to I2S IN-0
L=SOFT MUTE
EXTRA OUTPUT
EFFECT LOOP SEND
(860mVpp max.)
(Free to use)
※ Marked Capacitors are C0G for better Sound Characteristics.
DAC
to I2S IN-1
I2S OUT-1
MIXED OUTPUT-LEFT
MIXED OUTPUT-RIGHT
(2V RMS)
(>1kHz)
(More than -20dBV)
ADC
Headphones Amp
※ Marked Capacitors are C0G for it’s Sound Characteristics.
-3.2V
Change to 1uF for pre-emphasis normalized overdrive. (De-emphasis shoud have done in DSP processing)
ALTERNATIVE CHOICE SELECT ONE AS YOU LIKE
CLEAN JUNKY
1.8V
1.42V

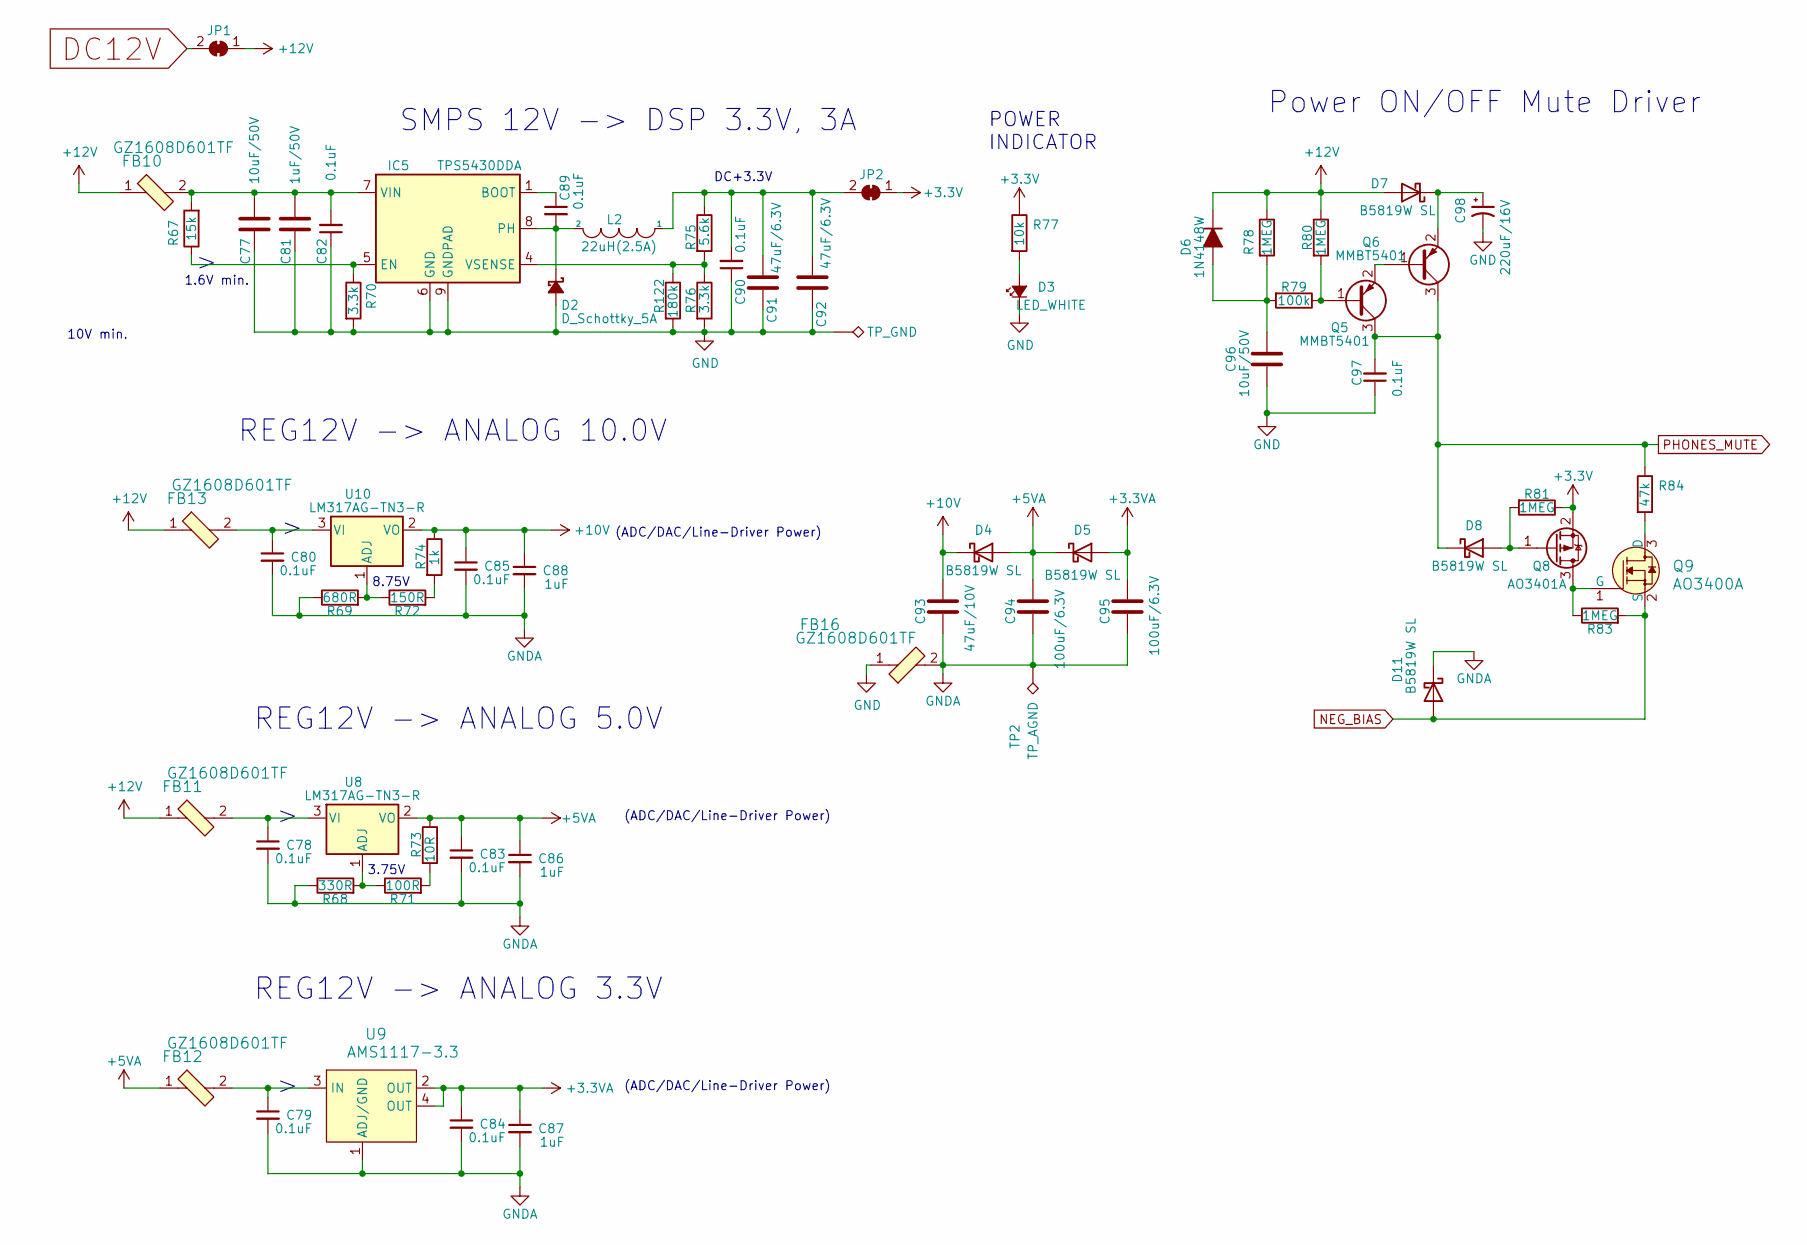
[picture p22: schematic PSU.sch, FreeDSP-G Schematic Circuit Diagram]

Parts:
C77, C96: 10uF/50V; C_0805_2012Metric
C78, C79, C80, C82, C83, C84, C85, C89, C90, C97: 0.1uF; C_0603_1608Metric_Pad1.08x0.95mm_HandSolder
C81: 1uF/50V; C_0805_2012Metric
C86, C87, C88: 1uF; C_0805_2012Metric
C91, C92: 47uF/6.3V; C_0805_2012Metric
C93: 47uF/10V; C_1206_3216Metric
C94, C95: 100uF/6.3V; C_1206_3216Metric
C98: 220uF/16V; CP_Radial_D7.5mm_P2.50mm
D2: D_Schottky_5A; D_SMA
D3: LED_WHITE; LED_0603_1608Metric_Castellated
D4, D5, D7, D8, D11: B5819W SL; D_SOD-123
D6: 1N4148W; D_SOD-123
FB10, FB11, FB12, FB13: GZ1608D601TF; L_0603_1608Metric_Pad1.05x0.95mm_HandSolder; MPN BLM18AG601SN1D; Digi-Key_PN 490-1014-1-ND
FB16: GZ1608D601TF; L_0603_1608Metric_Pad1.05x0.95mm_HandSolder; MPN BLM21PG331SN1D; Digi-Key_PN 490-5988-1-ND
IC5: TPS5430DDA; TI_SO-PowerPAD-8_ThermalVias
JP1, JP2: SolderJumper_3_Bridged12; SolderJumper-2_P1.3mm_Bridged_RoundedPad1.0x1.5mm
L2: 22uH(2.5A); L_Taiyo-Yuden_NR-60xx_HandSoldering
Q5, Q6: MMBT5401; SOT-23
Q8: AO3401A; SOT-23; Manufacturer_Part_Number DMG3415U-7; Mouser Part Number 621-DMG3415U-7
Q9: AO3400A; SOT-23; MPN 2N7002; Digi-Key_PN 2N7002NCT-ND
R67: 15k; R_0603_1608Metric_Pad0.98x0.95mm_HandSolder
R68: 330R; R_0603_1608Metric_Pad0.98x0.95mm_HandSolder
R69: 680R; R_0603_1608Metric_Pad0.98x0.95mm_HandSolder
R70, R76: 3.3k; R_0603_1608Metric_Pad0.98x0.95mm_HandSolder
R71: 100R; R_0603_1608Metric_Pad0.98x0.95mm_HandSolder
R72: 150R; R_0603_1608Metric_Pad0.98x0.95mm_HandSolder
R73: 10R; R_0603_1608Metric_Pad0.98x0.95mm_HandSolder
R74: 1k; R_0603_1608Metric_Pad0.98x0.95mm_HandSolder
R75: 5.6k; R_0603_1608Metric_Pad0.98x0.95mm_HandSolder
R77: 10k; R_0603_1608Metric_Pad0.98x0.95mm_HandSolder
R78, R80, R81, R83: 1MEG; R_0603_1608Metric_Pad0.98x0.95mm_HandSolder
R79: 100k; R_0603_1608Metric_Pad0.98x0.95mm_HandSolder
R84: 47k; R_0603_1608Metric_Pad0.98x0.95mm_HandSolder
R122: 180k; R_0603_1608Metric_Pad0.98x0.95mm_HandSolder
TP1: TP_GND; TestPoint_THTPad_1.5x1.5mm_Drill0.7mm
TP2: TP_AGND; TestPoint_THTPad_1.5x1.5mm_Drill0.7mm
U8, U10: LM317AG-TN3-R; TO-252-2
U9: AMS1117-3.3; SOT-223

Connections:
+3.3VA: C84.1, C87.1, C95.1, D5.2 (A), U9.2 (OUT), U9.4 (OUT); also elsewhere on the board
+3V3: JP2.1 (A), Q8.2 (S), R77.1, R81.1; also elsewhere on the board
+5VA: C83.1, C86.1, C94.1, D4.2 (A), D5.1 (K), FB12.1, R73.1, U8.2 (VO); also elsewhere on the board
+10V: C85.1, C88.1, C93.1, D4.1 (K), R74.1, U10.2 (VO); also elsewhere on the board
+12V: D6.1 (K), D7.2 (A), FB10.1, FB11.1, FB13.1, JP1.1 (A), R78.1, R80.1
DC12V: JP1.2 (B); also elsewhere on the board
GND: C77.2, C81.2, C82.1, C90.1, C91.2, C92.2, C96.2, C97.1, C98.2, D2.2 (A), D3.1 (K), FB16.1, IC5.6 (GND), IC5.9 (GNDPAD), R70.2, R76.2, R122.2, TP1.1; also elsewhere on the board
GNDA: C78.2, C79.2, C80.2, C83.2, C84.2, C85.2, C86.2, C87.2, C88.2, C93.2, C94.2, C95.2, D11.1 (K), FB16.2, R68.1, R69.1, TP2.1, U9.1 (ADJ/GND); also elsewhere on the board
NEG_BIAS: D11.2 (A), Q9.2 (S), R83.2; also elsewhere on the board
unnamed: C77.1, C81.1, C82.2, FB10.2, IC5.7 (VIN), R67.2
unnamed: C78.1, FB11.2, U8.3 (VI)
unnamed: C79.1, FB12.2, U9.3 (IN)
unnamed: C80.1, FB13.2, U10.3 (VI)
unnamed: C89.1, IC5.1 (BOOT)
unnamed: C89.2, D2.1 (K), IC5.8 (PH), L2.2
unnamed: C90.2, C91.1, C92.1, JP2.2 (B), L2.1, R75.1
unnamed: C96.1, D6.2 (A), R78.2, R79.2
unnamed: C98.1, D7.1 (K), Q6.2 (E)
unnamed: D3.2 (A), R77.2
unnamed: D8.2 (A), Q8.1 (G), R81.2
unnamed: IC5.4 (VSENSE), R75.2, R76.1, R122.1
unnamed: IC5.5 (EN), R67.1, R70.1
unnamed: Q5.1 (B), R79.1, R80.2
unnamed: Q5.2 (E), Q6.1 (B)
unnamed: Q8.3 (D), Q9.1 (G), R83.1
unnamed: Q9.3 (D), R84.2
unnamed: R68.2, R71.1, U8.1 (ADJ)
unnamed: R69.2, R72.1, U10.1 (ADJ)
unnamed: R71.2, R73.2
unnamed: R72.2, R74.2
PHONES_MUTE: C97.2, D8.1 (K), Q5.3 (C), Q6.3 (C), R84.1; also elsewhere on the board

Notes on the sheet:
DC+3.3V
SMPS 12V -> DSP 3.3V, 3A
POWER INDICATOR
Power ON/OFF Mute Driver
(ADC/DAC/Line-Driver Power)
1.6V min.
8.75V
REG12V -> ANALOG 10.0V
10V min.
3.75V
REG12V -> ANALOG 5.0V
REG12V -> ANALOG 3.3V

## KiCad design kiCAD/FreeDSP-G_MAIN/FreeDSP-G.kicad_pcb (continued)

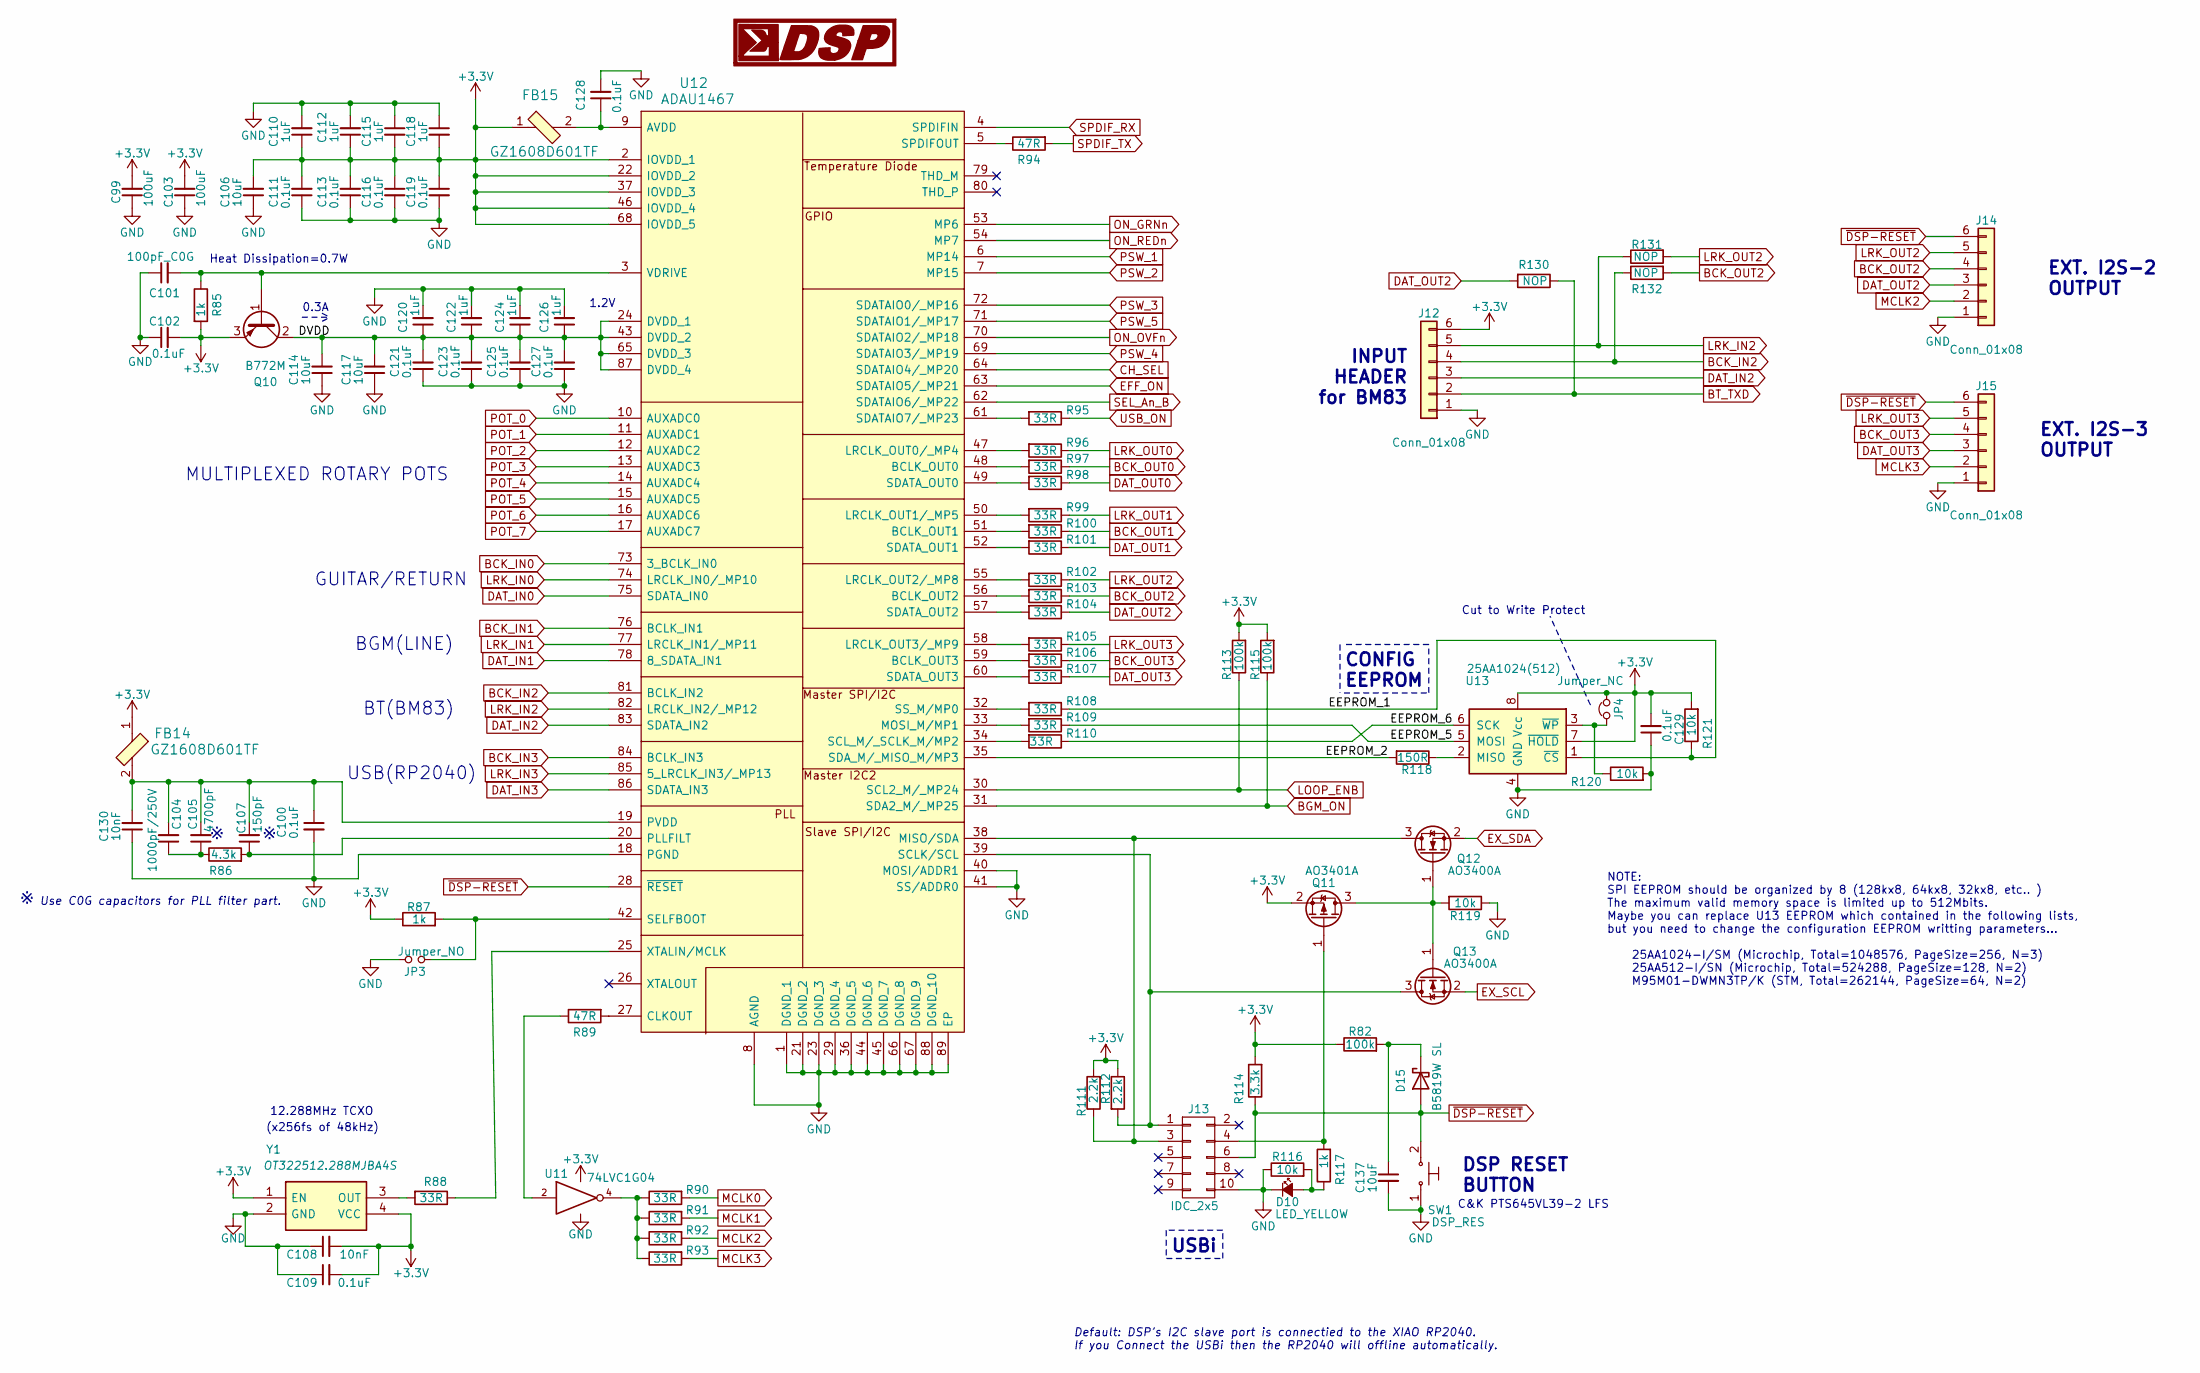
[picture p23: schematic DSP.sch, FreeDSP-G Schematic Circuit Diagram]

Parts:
C99, C103: 100uF; C_1206_3216Metric
C100, C102, C109, C111, C113, C116, C119, C121, C123, C125, C127, C128, C129: 0.1uF; C_0603_1608Metric_Pad1.08x0.95mm_HandSolder
C101: 100pF_C0G; C_0603_1608Metric_Pad1.08x0.95mm_HandSolder
C104: 1000pF/250V; C_0805_2012Metric
C105: 4700pF; C_0805_2012Metric
C106, C114, C117, C137: 10uF; C_0805_2012Metric
C107: 150pF; C_0805_2012Metric
C108, C130: 10nF; C_0603_1608Metric_Pad1.08x0.95mm_HandSolder
C110, C112, C115, C118, C120, C122, C124, C126: 1uF; C_0603_1608Metric_Pad1.08x0.95mm_HandSolder
D10: LED_YELLOW; LED_0603_1608Metric_Castellated
D15: B5819W SL; D_SOD-123
FB14, FB15: GZ1608D601TF; L_0603_1608Metric_Pad1.05x0.95mm_HandSolder; MPN BLM18AG601SN1D; Digi-Key_PN 490-1014-1-ND
J12, J14, J15: Conn_01x08; PinHeader_1x06_P2.54mm_Vertical
J13: IDC_2x5; IDC-Header_2x05_P2.54mm_Vertical
JP3: Jumper_NO; PinHeader_1x02_P2.54mm_Vertical
JP4: Jumper_NC; SolderJumper-2_P1.3mm_Bridged_RoundedPad1.0x1.5mm
Q10: B772M; TO-252-2
Q11: AO3401A; SOT-23; Manufacturer_Part_Number DMG3415U-7; Mouser Part Number 621-DMG3415U-7
Q12, Q13: AO3400A; SOT-23
R82, R113, R115: 100k; R_0603_1608Metric_Pad0.98x0.95mm_HandSolder
R85, R87, R117: 1k; R_0603_1608Metric_Pad0.98x0.95mm_HandSolder
R86: 4.3k; R_0603_1608Metric_Pad0.98x0.95mm_HandSolder
R88, R90, R91, R92, R93, R95, R96, R97, R98, R99, R100, R101, R102, R103, R104, R105, R106, R107, R108, R109, R110: 33R; R_0603_1608Metric_Pad0.98x0.95mm_HandSolder
R89, R94: 47R; R_0603_1608Metric_Pad0.98x0.95mm_HandSolder
R111, R112: 2.2k; R_0603_1608Metric_Pad0.98x0.95mm_HandSolder
R114: 3.3k; R_0603_1608Metric_Pad0.98x0.95mm_HandSolder
R116, R119, R120, R121: 10k; R_0603_1608Metric_Pad0.98x0.95mm_HandSolder
R118: 150R; R_0603_1608Metric_Pad0.98x0.95mm_HandSolder
R130, R131, R132: NOP; R_0603_1608Metric_Pad0.98x0.95mm_HandSolder
SW1: DSP_RES; SW_Tactile_SPST_Angled_PTS645Vx83-2LFS
U11: 74LVC1G04; SOT-23-5_HandSoldering
U12: ADAU1467; ADAU1467WBCPZ300
U13: 25AA1024(512); SOIC-8_3.9x4.9mm_P1.27mm
Y1: OT322512.288MJBA4S; Crystal_SMD_TXC_7M-4pin_3.2x2.5mm_HandSoldering; Manufacturer_Part_Number KC7050K50.0000C1GE00
Z1: LOGO; SigmaDSP-LogoSmall

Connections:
+3V3: C99.2, C102.2, C103.2, C106.2, C108.2, C109.2, C110.1, C111.2, C112.1, C113.2, C115.2, C116.1, C118.2, C119.1, C129.2, FB14.1, FB15.1, J12.6, JP4.2, Q10.3 (E), Q11.2 (S), R82.1, R85.2, R87.1, R111.2, R112.1, R113.2, R114.2, R115.2, R121.2, U11.5 (VCC), U12.2 (IOVDD_1), U12.22 (IOVDD_2), U12.37 (IOVDD_3), U12.46 (IOVDD_4), U12.68 (IOVDD_5), U13.7 (~HOLD), U13.8 (Vcc), Y1.1 (EN), Y1.4 (VCC); also elsewhere on the board
/DSP/DVDD: C114.2, C117.2, C120.1, C121.2, C122.1, C123.2, C124.1, C125.2, C126.1, C127.2, Q10.2 (C), U12.24 (DVDD_1), U12.43 (DVDD_2), U12.65 (DVDD_3), U12.87 (DVDD_4)
/DSP/EEPROM_1: R108.1, R121.1, U13.1 (~CS)
/DSP/EEPROM_2: R118.2, U12.35 (SDA_M/_MISO_M/MP3)
/DSP/EEPROM_5: R109.1, U13.5 (MOSI)
/DSP/EEPROM_6: R110.1, U13.6 (SCK)
BCK_IN0: U12.73 (3_BCLK_IN0); also elsewhere on the board
BCK_IN1: U12.76 (BCLK_IN1); also elsewhere on the board
BCK_IN2: J12.4, R132.1, U12.81 (BCLK_IN2); also elsewhere on the board
BCK_IN3: U12.84 (BCLK_IN3); also elsewhere on the board
BCK_OUT0: R97.1; also elsewhere on the board
BCK_OUT1: R100.1; also elsewhere on the board
BCK_OUT2: J14.4, R103.1, R132.2
BCK_OUT3: J15.4, R106.1
BGM_ON: R115.1, U12.31 (SDA2_M/_MP25); also elsewhere on the board
BT_TXD: J12.2, R130.1; also elsewhere on the board
CH_SEL: U12.64 (SDATAIO4/_MP20); also elsewhere on the board
DAT_IN0: U12.75 (SDATA_IN0); also elsewhere on the board
DAT_IN1: U12.78 (8_SDATA_IN1); also elsewhere on the board
DAT_IN2: J12.3, U12.83 (SDATA_IN2); also elsewhere on the board
DAT_IN3: U12.86 (SDATA_IN3); also elsewhere on the board
DAT_OUT0: R98.1; also elsewhere on the board
DAT_OUT1: R101.1; also elsewhere on the board
DAT_OUT2: J14.3, R104.1, R130.2
DAT_OUT3: J15.3, R107.1
EFF_ON: U12.63 (SDATAIO5/_MP21); also elsewhere on the board
EX_SCL: Q13.2 (S); also elsewhere on the board
EX_SDA: Q12.2 (S); also elsewhere on the board
GND: C99.1, C100.2, C101.1, C102.1, C103.1, C106.1, C108.1, C109.1, C110.2, C111.1, C112.2, C113.1, C114.1, C115.1, C116.2, C117.1, C118.1, C119.2, C120.2, C121.1, C122.2, C123.1, C124.2, C125.1, C126.2, C127.1, C128.2, C129.1, C130.1, C137.2, D10.1 (K), J12.1, J13.10, J14.1, J15.1, JP3.1, R116.1, R119.1, R120.2, SW1.1, U11.3 (GND), U12.1 (DGND_1), U12.8 (AGND), U12.18 (PGND), U12.21 (DGND_2), U12.23 (DGND_3), U12.29 (DGND_4), U12.36 (DGND_5), U12.40 (MOSI/ADDR1), U12.41 (SS/ADDR0), U12.44 (DGND_6), U12.45 (DGND_7), U12.66 (DGND_8), U12.67 (DGND_9), U12.88 (DGND_10), U12.89 (EP), U13.4 (GND), Y1.2 (GND); also elsewhere on the board
LOOP_ENB: R113.1, U12.30 (SCL2_M/_MP24); also elsewhere on the board
LRK_IN0: U12.74 (LRCLK_IN0/_MP10); also elsewhere on the board
LRK_IN1: U12.77 (LRCLK_IN1/_MP11); also elsewhere on the board
LRK_IN2: J12.5, R131.1, U12.82 (LRCLK_IN2/_MP12); also elsewhere on the board
LRK_IN3: U12.85 (5_LRCLK_IN3/_MP13); also elsewhere on the board
LRK_OUT0: R96.1; also elsewhere on the board
LRK_OUT1: R99.1; also elsewhere on the board
LRK_OUT2: J14.5, R102.1, R131.2
LRK_OUT3: J15.5, R105.1
MCLK0: R90.2; also elsewhere on the board
MCLK1: R91.2; also elsewhere on the board
MCLK2: J14.2, R92.2; also elsewhere on the board
MCLK3: J15.2, R93.2; also elsewhere on the board
unnamed: C100.1, C104.2, C105.2, C107.2, C130.2, FB14.2, U12.19 (PVDD)
unnamed: C101.2, Q10.1 (B), R85.1, U12.3 (VDRIVE)
unnamed: C104.1, C105.1, R86.1
unnamed: C107.1, R86.2, U12.20 (PLLFILT)
unnamed: C128.1, FB15.2, U12.9 (AVDD)
unnamed: C137.1, D15.1 (K), R82.2
unnamed: D10.2 (A), R116.2, R117.1
unnamed: J13.1, Q13.3 (D), R112.2, U12.39 (SCLK/SCL)
unnamed: J13.3, Q12.3 (D), R111.1, U12.38 (MISO/SDA)
unnamed: J13.4, Q11.1 (G), R117.2
unnamed: JP3.2, R87.2, U12.42 (SELFBOOT)
unnamed: JP4.1, R120.1, U13.3 (~WP)
unnamed: Q11.3 (D), Q12.1 (G), Q13.1 (G), R119.2
unnamed: R88.1, U12.25 (XTALIN/MCLK)
unnamed: R88.2, Y1.3 (OUT)
unnamed: R89.1, U11.2
unnamed: R89.2, U12.27 (CLKOUT)
unnamed: R90.1, R91.1, R92.1, R93.1, U11.4
unnamed: R94.1, U12.5 (SPDIFOUT)
unnamed: R95.2, U12.61 (SDATAIO7/_MP23)
unnamed: R96.2, U12.47 (LRCLK_OUT0/_MP4)
unnamed: R97.2, U12.48 (BCLK_OUT0)
unnamed: R98.2, U12.49 (SDATA_OUT0)
unnamed: R99.2, U12.50 (LRCLK_OUT1/_MP5)
unnamed: R100.2, U12.51 (BCLK_OUT1)
unnamed: R101.2, U12.52 (SDATA_OUT1)
unnamed: R102.2, U12.55 (LRCLK_OUT2/_MP8)
unnamed: R103.2, U12.56 (BCLK_OUT2)
unnamed: R104.2, U12.57 (SDATA_OUT2)
unnamed: R105.2, U12.58 (LRCLK_OUT3/_MP9)
unnamed: R106.2, U12.59 (BCLK_OUT3)
unnamed: R107.2, U12.60 (SDATA_OUT3)
unnamed: R108.2, U12.32 (SS_M/MP0)
unnamed: R109.2, U12.33 (MOSI_M/MP1)
unnamed: R110.2, U12.34 (SCL_M/_SCLK_M/MP2)
unnamed: R118.1, U13.2 (MISO)
ON_GRNn: U12.53 (MP6); also elsewhere on the board
ON_OVFn: U12.70 (SDATAIO2/_MP18); also elsewhere on the board
ON_REDn: U12.54 (MP7); also elsewhere on the board
POT_0: U12.10 (AUXADC0); also elsewhere on the board
POT_1: U12.11 (AUXADC1); also elsewhere on the board
POT_2: U12.12 (AUXADC2); also elsewhere on the board
POT_3: U12.13 (AUXADC3); also elsewhere on the board
POT_4: U12.14 (AUXADC4); also elsewhere on the board
POT_5: U12.15 (AUXADC5); also elsewhere on the board
POT_6: U12.16 (AUXADC6); also elsewhere on the board
POT_7: U12.17 (AUXADC7); also elsewhere on the board
PSW_1: U12.6 (MP14); also elsewhere on the board
PSW_2: U12.7 (MP15); also elsewhere on the board
PSW_3: U12.72 (SDATAIO0/_MP16); also elsewhere on the board
PSW_4: U12.69 (SDATAIO3/_MP19); also elsewhere on the board
PSW_5: U12.71 (SDATAIO1/_MP17); also elsewhere on the board
SEL_An_B: U12.62 (SDATAIO6/_MP22); also elsewhere on the board
SPDIF_RX: U12.4 (SPDIFIN); also elsewhere on the board
SPDIF_TX: R94.2; also elsewhere on the board
USB_ON: R95.1; also elsewhere on the board
~DSP-RESET: D15.2 (A), J13.6, J14.6, J15.6, R114.1, SW1.2, U12.28 (~RESET)

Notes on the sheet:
USBi
12.288MHz TCXO
USB(RP2040)
GUITAR/RETURN
MULTIPLEXED ROTARY POTS
BGM(LINE)
(x256fs of 48kHz)
NOTE: SPI EEPROM should be organized by 8 (128kx8, 64kx8, 32kx8, etc.. ) The maximum valid memory space is limited up to 512Mbits. Maybe you can replace U13 EEPROM which contained in the following lists, but you need to change the configuration EEPROM writting parameters… 25AA1024-I/SM (Microchip, 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
Default: DSP’s I2C slave port is connectied to the XIAO RP2040. If you Connect the USBi then the RP2040 will offline automatically.
0.3A
1.2V
Heat Dissipation=0.7W
DSP RESET BUTTON
C&K PTS645VL39-2 LFS
BT(BM83)
Cut to Write Protect
CONFIG EEPROM
Use C0G capacitors for PLL filter part.
INPUT HEADER for BM83
EXT. I2S-2 OUTPUT
EXT. I2S-3 OUTPUT

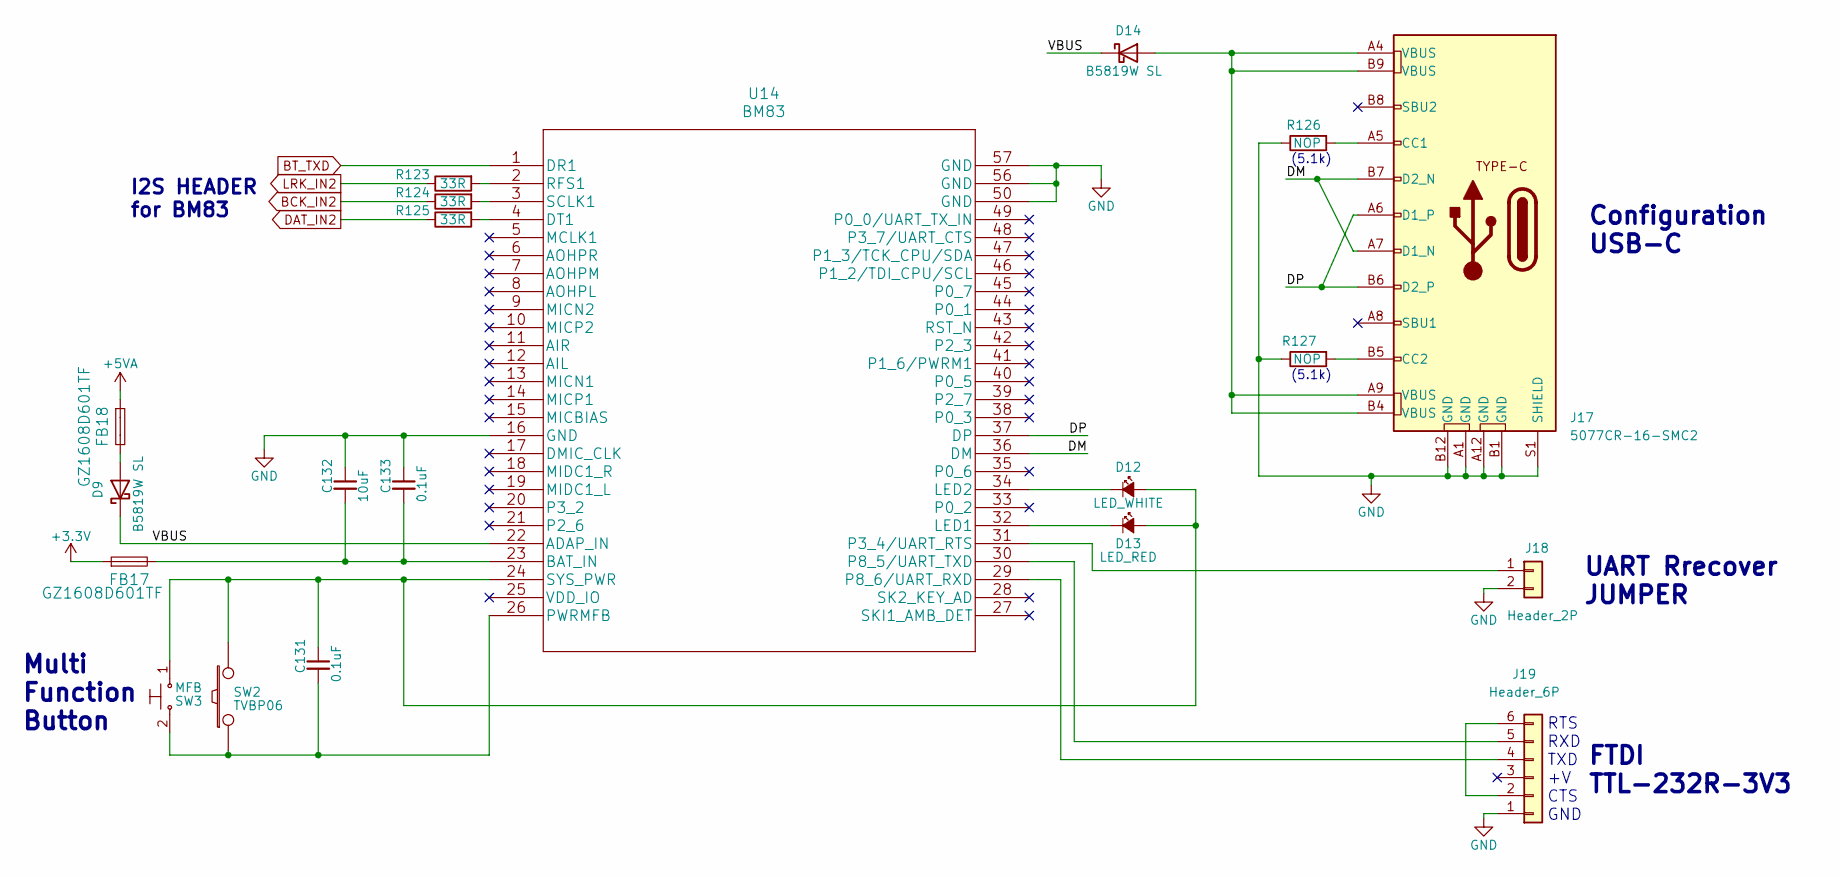
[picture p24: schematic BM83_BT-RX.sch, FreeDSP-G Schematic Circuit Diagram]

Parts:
C131, C133: 0.1uF; C_0603_1608Metric_Pad1.08x0.95mm_HandSolder
C132: 10uF; C_0805_2012Metric
D9, D14: B5819W SL; D_SOD-123
D12: LED_WHITE; LED_0603_1608Metric_Castellated
D13: LED_RED; LED_0603_1608Metric_Castellated
FB17, FB18: GZ1608D601TF; L_0603_1608Metric_Pad1.05x0.95mm_HandSolder; MPN BLM18AG601SN1D; Digi-Key_PN 490-1014-1-ND
J17: 5077CR-16-SMC2; USB-C_5077CR-16-SMC2-BK-TR
J18: Header_2P; PinHeader_1x02_P2.54mm_Vertical
J19: Header_6P; PinHeader_1x06_P2.54mm_Vertical
R123, R124, R125: 33R; R_0603_1608Metric_Pad0.98x0.95mm_HandSolder
R126, R127: NOP; R_0603_1608Metric_Pad0.98x0.95mm_HandSolder
SW2: TVBP06; MJTP1250
SW3: MFB; SW_Tactile_SPST_Angled_PTS645Vx83-2LFS
U14: BM83; BM83_MCH

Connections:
+3V3: FB17.1; also elsewhere on the board
+5VA: FB18.1; also elsewhere on the board
/BM83_BT-RX/DM: J17.A7 (D1_N), J17.B7 (D2_N), U14.36 (DM)
/BM83_BT-RX/DP: J17.A6 (D1_P), J17.B6 (D2_P), U14.37 (DP)
/BM83_BT-RX/VBUS: D9.1 (K), D14.1 (K), U14.22 (ADAP_IN)
BCK_IN2: R124.1; also elsewhere on the board
BT_TXD: U14.1 (DR1); also elsewhere on the board
DAT_IN2: R125.1; also elsewhere on the board
GND: C132.1, C133.1, J17.A1 (GND), J17.A12 (GND), J17.B1 (GND), J17.B12 (GND), J17.S1 (SHIELD), J18.2, J19.1, R126.1, R127.1, U14.16 (GND), U14.50 (GND), U14.56 (GND), U14.57 (GND); also elsewhere on the board
LRK_IN2: R123.1; also elsewhere on the board
unnamed: C131.1, D12.2 (A), D13.2 (A), SW2.2, SW3.1, U14.24 (SYS_PWR)
unnamed: C131.2, SW2.1, SW3.2, U14.26 (PWRMFB)
unnamed: C132.2, C133.2, FB17.2, U14.23 (BAT_IN)
unnamed: D9.2 (A), FB18.2
unnamed: D12.1 (K), U14.34 (LED2)
unnamed: D13.1 (K), U14.32 (LED1)
unnamed: D14.2 (A), J17.A4 (VBUS), J17.A9 (VBUS), J17.B4 (VBUS), J17.B9 (VBUS)
unnamed: J17.A5 (CC1), R126.2
unnamed: J17.B5 (CC2), R127.2
unnamed: J18.1, U14.31 (P3_4/UART_RTS)
unnamed: J19.2, J19.6
unnamed: J19.4, U14.29 (P8_6/UART_RXD)
unnamed: J19.5, U14.30 (P8_5/UART_TXD)
unnamed: R123.2, U14.2 (RFS1)
unnamed: R124.2, U14.3 (SCLK1)
unnamed: R125.2, U14.4 (DT1)

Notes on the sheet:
I2S HEADER for BM83
RTS RXD TXD +V CTS GND
FTDI TTL-232R-3V3
UART Rrecover JUMPER
Configuration USB-C
Multi Function Button
(5.1k)

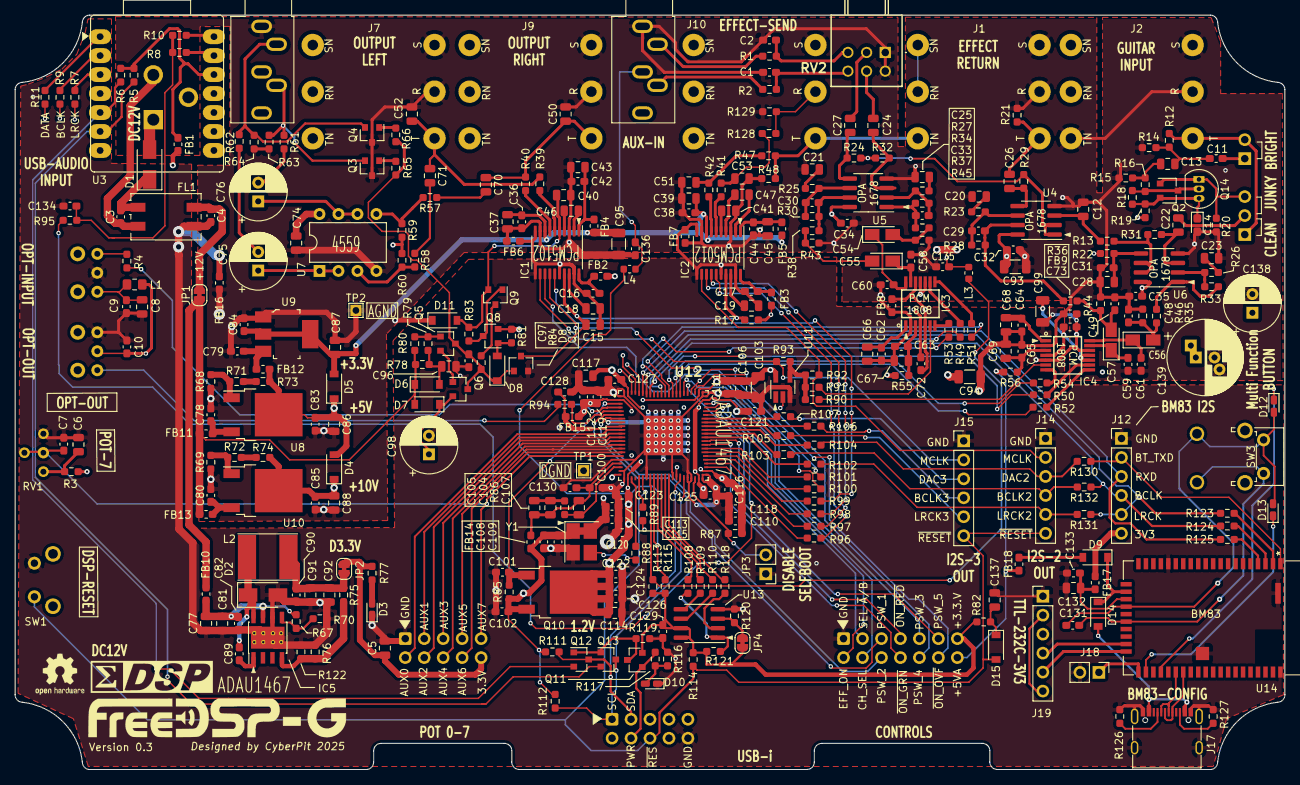
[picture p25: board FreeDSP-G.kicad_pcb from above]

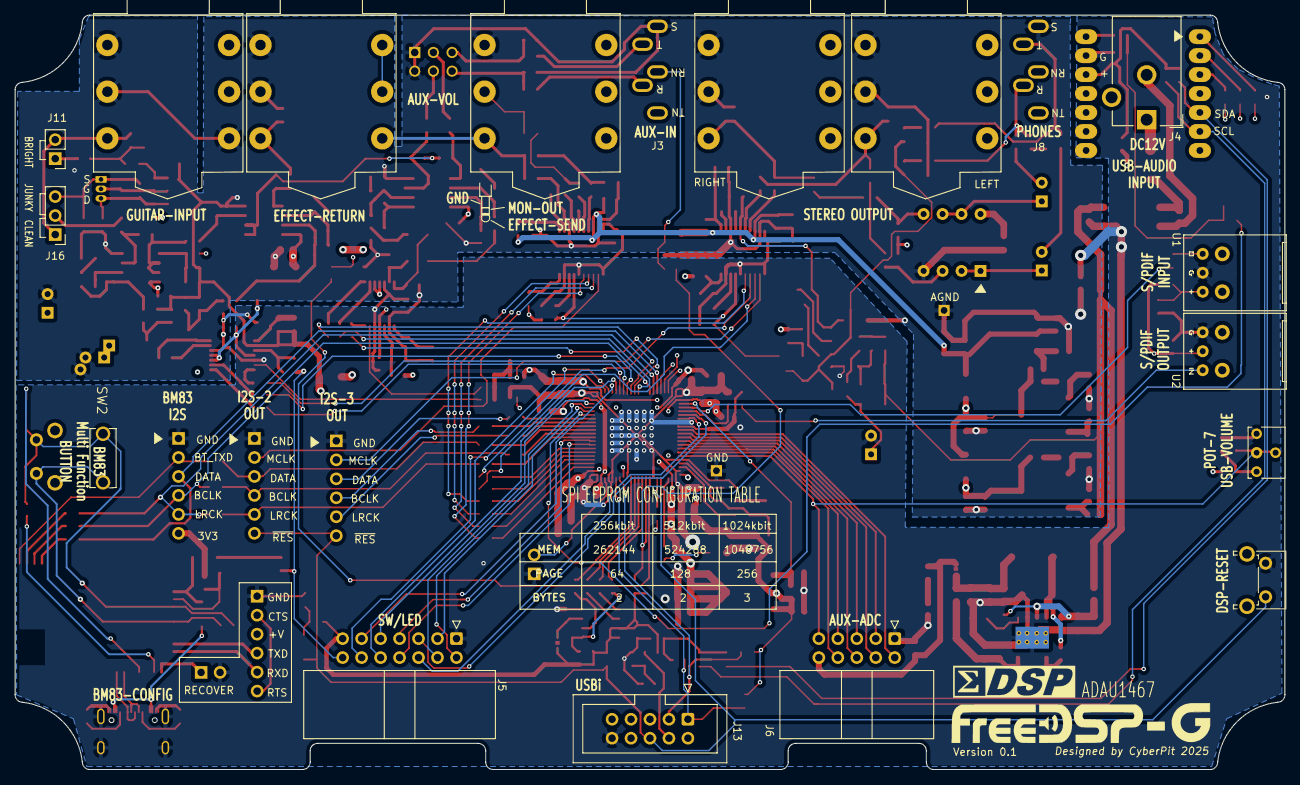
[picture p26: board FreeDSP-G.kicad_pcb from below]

Board: 4 copper layers, 170.0 x 101.0 mm, 374 parts (16 on the bottom side), 247 nets.

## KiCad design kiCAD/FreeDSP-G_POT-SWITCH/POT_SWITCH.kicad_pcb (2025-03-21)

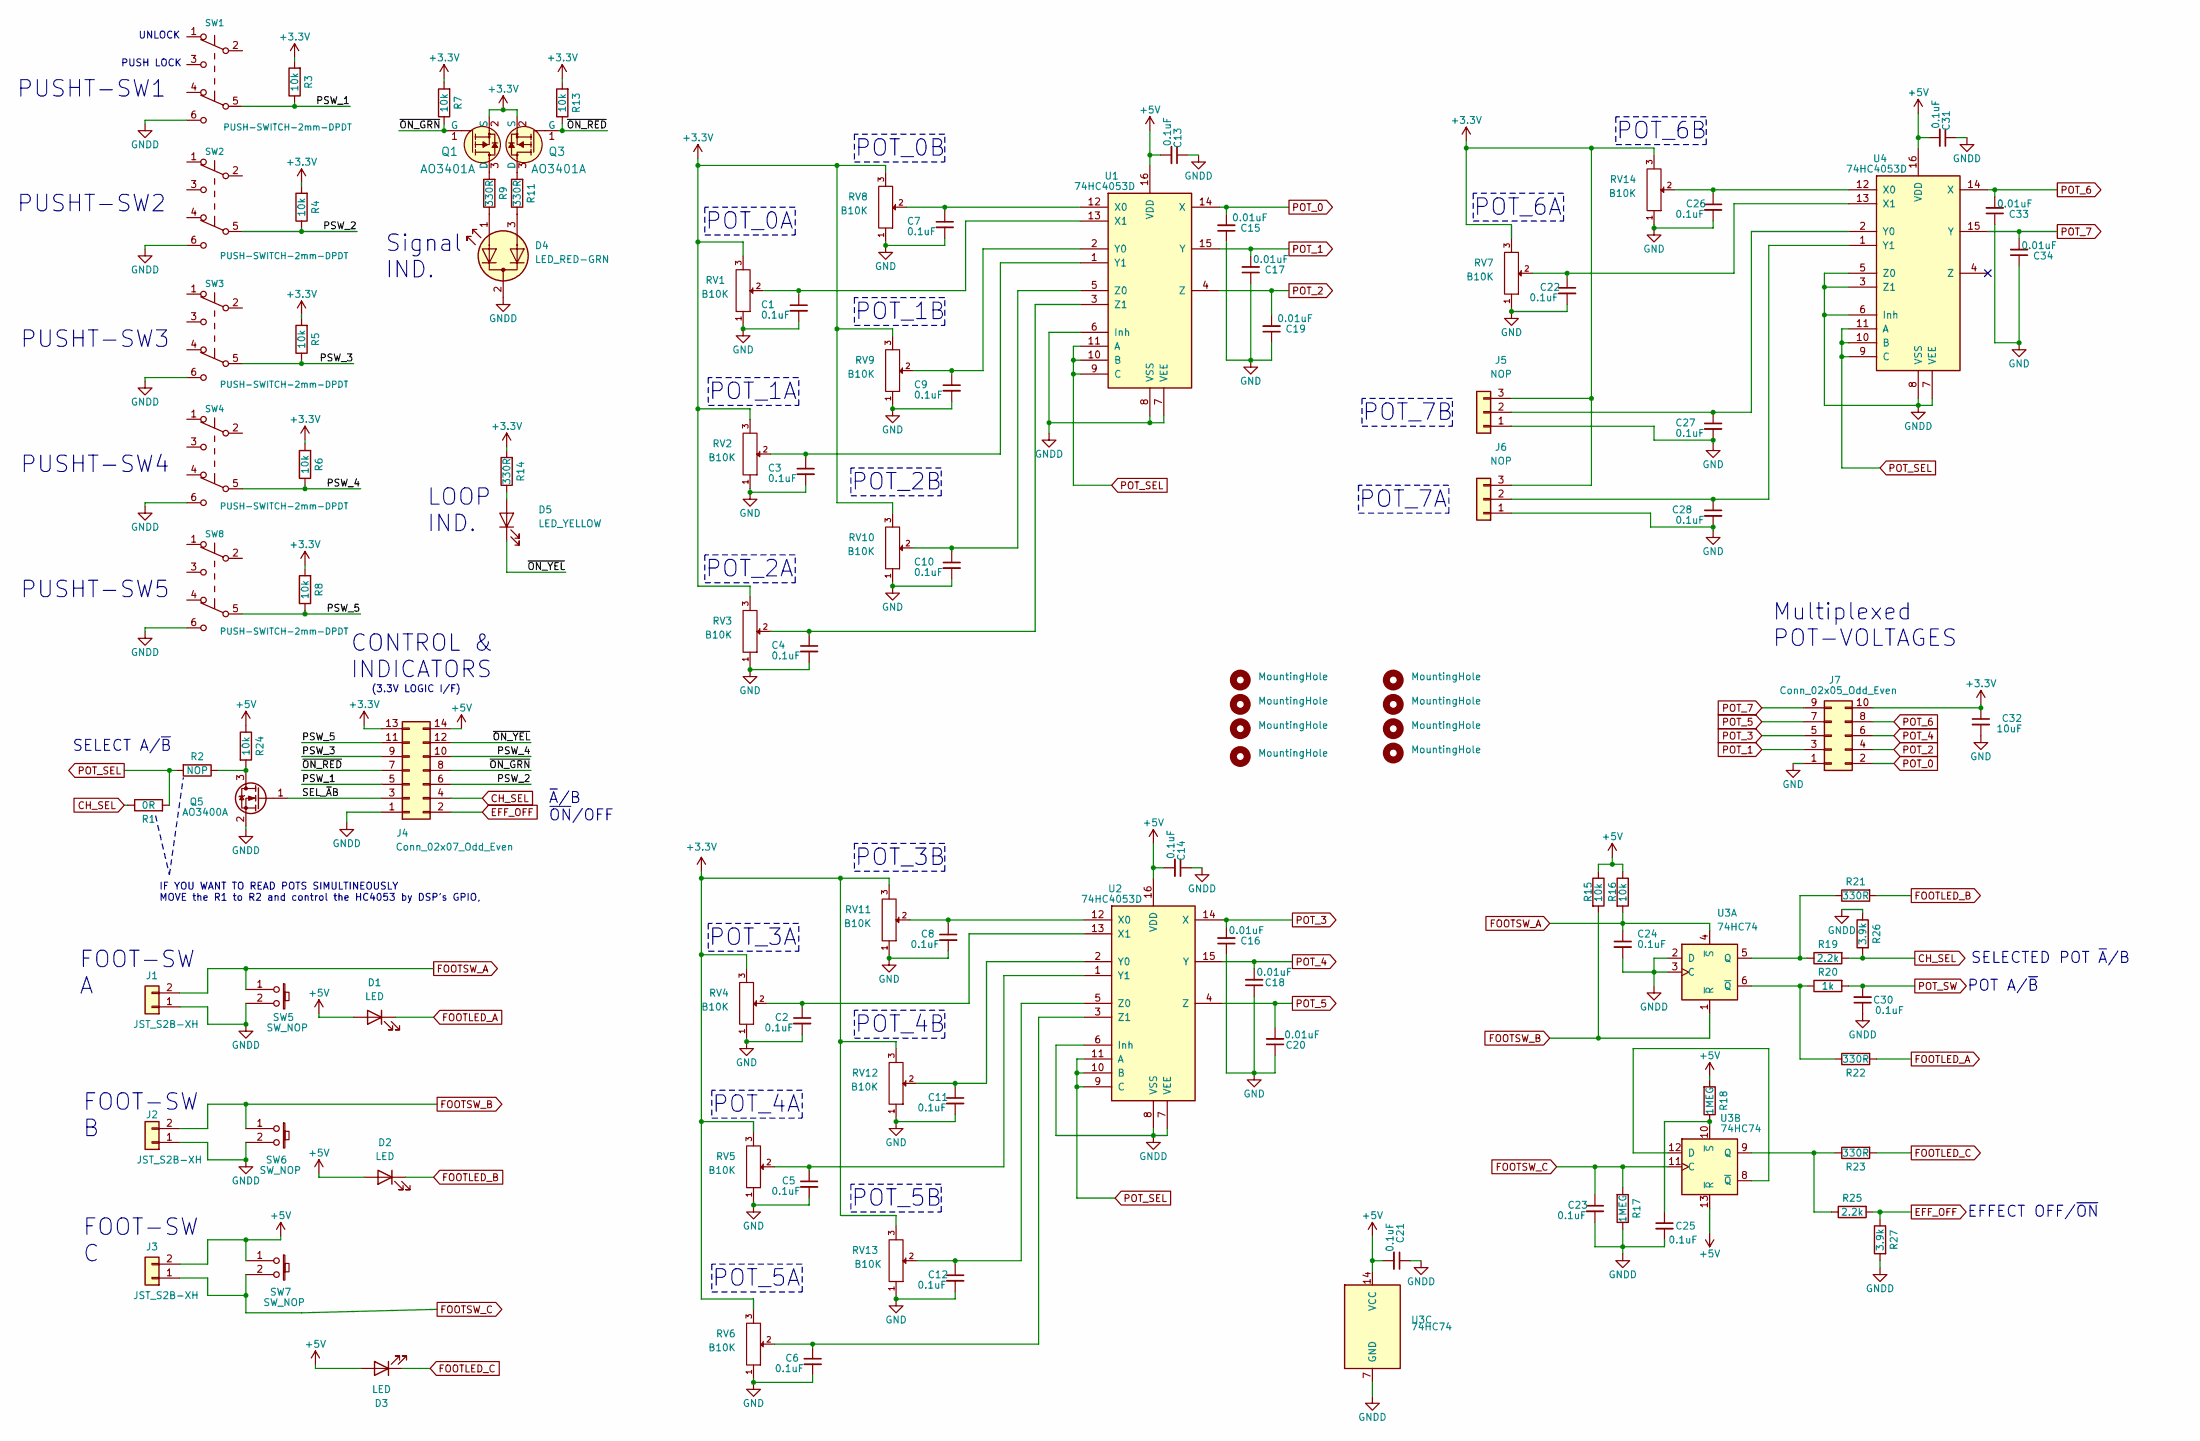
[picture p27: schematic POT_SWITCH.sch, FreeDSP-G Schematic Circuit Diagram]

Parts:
C1, C2, C3, C4, C5, C6, C7, C8, C9, C10, C11, C12, C13, C14, C21, C22, C23, C24, C25, C26, C27, C28, C30, C31: 0.1uF; C_0805_2012Metric_Pad1.18x1.45mm_HandSolder
C15, C16, C17, C18, C19, C20, C33, C34: 0.01uF; C_0805_2012Metric_Pad1.18x1.45mm_HandSolder
C32: 10uF; C_0805_2012Metric_Pad1.18x1.45mm_HandSolder
D1, D2, D3: LED; LED_D3.0mm_Clear
D4: LED_RED-GRN; LED_D3.0mm-3
D5: LED_YELLOW; LED_D3.0mm
H1, H2, H3, H4, H5, H6, H7, H8: MountingHole; MountingHole_3.2mm_M3_DIN965_Pad_TopBottom
J1, J2, J3: JST_S2B-XH; JST_XH_S2B-XH-A_1x02_P2.50mm_Horizontal
J4: Conn_02x07_Odd_Even; IDC-Header_2x07_P2.54mm_Horizontal
J5, J6: NOP; JST_XH_B3B-XH-A_1x03_P2.50mm_Vertical
J7: Conn_02x05_Odd_Even; IDC-Header_2x05_P2.54mm_Horizontal
Q1, Q3: AO3401A; SOT-23-3; MPN AO3401A; Digi-Key_PN 785-1001-1-ND
Q5: AO3400A; SOT-23
R1: 0R; R_0805_2012Metric_Pad1.20x1.40mm_HandSolder
R2: NOP; R_0805_2012Metric_Pad1.20x1.40mm_HandSolder
R3, R4, R5, R6, R7, R8, R13, R15, R16, R24: 10k; R_0805_2012Metric_Pad1.20x1.40mm_HandSolder
R9, R11, R14, R21, R22, R23: 330R; R_0805_2012Metric_Pad1.20x1.40mm_HandSolder
R17, R18: 1MEG; R_0805_2012Metric_Pad1.20x1.40mm_HandSolder
R19, R25: 2.2k; R_0805_2012Metric_Pad1.20x1.40mm_HandSolder
R20: 1k; R_0805_2012Metric_Pad1.20x1.40mm_HandSolder
R26, R27: 3.9k; R_0805_2012Metric_Pad1.20x1.40mm_HandSolder
RV1, RV2, RV3, RV4, RV5, RV6, RV7, RV8, RV9, RV10, RV11, RV12, RV13, RV14: B10K; Alps_RK09K113
SW1, SW2, SW3, SW4, SW8: PUSH-SWITCH-2mm-DPDT; PUSHSW_DPDT_6-7mm
SW5, SW6, SW7: SW_NOP; MJTP1250
U1, U2, U4: 74HC4053D; DIP-16_W7.62mm
U3: 74HC74; DIP-14_W7.62mm

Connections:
+3V3: C32.1, J4.13, J5.3, J6.3, J7.10, Q1.2 (S), Q3.2 (S), R3.2, R4.2, R5.2, R6.2, R7.2, R8.2, R13.2, R14.2, RV1.3, RV2.3, RV3.3, RV4.3, RV5.3, RV6.3, RV7.3, RV8.3, RV9.3, RV10.3, RV11.3, RV12.3, RV13.3, RV14.3
+5V: C13.2, C14.2, C21.2, C31.2, D1.2 (A), D2.2 (A), D3.2 (A), J3.2, J4.14, R15.1, R16.1, R18.2, R24.1, SW7.1, U1.16 (VDD), U2.16 (VDD), U3.13 (~R), U3.14 (VCC), U4.16 (VDD)
/PSW_1: J4.5, R3.1, SW1.5 (B)
/PSW_2: J4.6, R4.1, SW2.5 (B)
/PSW_3: J4.9, R5.1, SW3.5 (B)
/PSW_4: J4.10, R6.1, SW4.5 (B)
/PSW_5: J4.11, R8.1, SW8.5 (B)
/SEL_~A~B: J4.3, Q5.1 (G)
/~ON_GRN: J4.8, Q1.1 (G), R7.1
/~ON_OVF: D5.1 (K), J4.12
/~ON_RED: J4.7, Q3.1 (G), R13.1
CH_SEL: J4.4, R1.1, R19.2, R26.2
EFF_OFF: J4.2, R25.2, R27.1
FOOTLED_A: D1.1 (K), R22.2
FOOTLED_B: D2.1 (K), R21.2
FOOTLED_C: D3.1 (K), R23.2
FOOTSW_A: C24.1, J1.2, R16.2, SW5.1, U3.4 (~S)
FOOTSW_B: J2.2, R15.2, SW6.1, U3.1 (~R)
FOOTSW_C: C23.1, J3.1, R17.2, SW7.2, U3.11 (C)
GND: C1.2, C2.2, C3.2, C4.2, C5.2, C6.2, C7.2, C8.2, C9.2, C10.2, C11.2, C12.2, C15.1, C16.1, C17.1, C18.1, C19.1, C20.1, C22.2, C26.2, C27.2, C28.2, C32.2, C33.1, C34.1, J5.1, J6.1, J7.1, RV1.1, RV2.1, RV3.1, RV4.1, RV5.1, RV6.1, RV7.1, RV8.1, RV9.1, RV10.1, RV11.1, RV12.1, RV13.1, RV14.1
GNDD: C13.1, C14.1, C21.1, C23.2, C24.2, C25.2, C30.1, C31.1, D4.2 (K), J1.1, J2.1, J4.1, Q5.2 (S), R17.1, R26.1, R27.2, SW1.6 (C), SW2.6 (C), SW3.6 (C), SW4.6 (C), SW5.2, SW6.2, SW8.6 (C), U1.6 (Inh), U1.7 (VEE), U1.8 (VSS), U2.6 (Inh), U2.7 (VEE), U2.8 (VSS), U3.2 (D), U3.3 (C), U3.7 (GND), U4.3 (Z1), U4.5 (Z0), U4.6 (Inh), U4.7 (VEE), U4.8 (VSS)
unnamed: C1.1, RV1.2, U1.13 (X1)
unnamed: C2.1, RV4.2, U2.13 (X1)
unnamed: C3.1, RV2.2, U1.1 (Y1)
unnamed: C4.1, RV3.2, U1.3 (Z1)
unnamed: C5.1, RV5.2, U2.1 (Y1)
unnamed: C6.1, RV6.2, U2.3 (Z1)
unnamed: C7.1, RV8.2, U1.12 (X0)
unnamed: C8.1, RV11.2, U2.12 (X0)
unnamed: C9.1, RV9.2, U1.2 (Y0)
unnamed: C10.1, RV10.2, U1.5 (Z0)
unnamed: C11.1, RV12.2, U2.2 (Y0)
unnamed: C12.1, RV13.2, U2.5 (Z0)
unnamed: C22.1, RV7.2, U4.13 (X1)
unnamed: C25.1, R18.1, U3.10 (~S)
unnamed: C26.1, RV14.2, U4.12 (X0)
unnamed: C27.1, J5.2, U4.2 (Y0)
unnamed: C28.1, J6.2, U4.1 (Y1)
unnamed: D4.1 (A1), R9.1
unnamed: D4.3 (A2), R11.1
unnamed: D5.2 (A), R14.1
unnamed: Q1.3 (D), R9.2
unnamed: Q3.3 (D), R11.2
unnamed: Q5.3 (D), R2.1, R24.2
unnamed: R19.1, R21.1, U3.5 (Q)
unnamed: R20.1, R22.1, U3.6 (~Q)
unnamed: R23.1, R25.1, U3.9 (Q)
unnamed: U3.8 (~Q), U3.12 (D)
POT_0: C15.2, J7.2, U1.14 (X)
POT_1: C17.2, J7.3, U1.15 (Y)
POT_2: C19.2, J7.4, U1.4 (Z)
POT_3: C16.2, J7.5, U2.14 (X)
POT_4: C18.2, J7.6, U2.15 (Y)
POT_5: C20.2, J7.7, U2.4 (Z)
POT_6: C33.2, J7.8, U4.14 (X)
POT_7: C34.2, J7.9, U4.15 (Y)
POT_SEL: R1.2, R2.2, U1.9 (C), U1.10 (B), U1.11 (A), U2.9 (C), U2.10 (B), U2.11 (A), U4.9 (C), U4.10 (B), U4.11 (A)
POT_SW: C30.2, R20.2

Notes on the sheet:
POT_0A
POT_0B
POT_1B
POT_2B
POT_1A
POT_2A
POT_3B
POT_4B
POT_5B
POT_3A
POT_4A
POT_5A
POT_6A
POT_6B
FOOT-SW C
FOOT-SW B
FOOT-SW A
PUSHT-SW1
Multiplexed POT-VOLTAGES
PUSHT-SW4
PUSHT-SW3
POT_7A
POT_7B
CONTROL & INDICATORS
PUSHT-SW2
UNLOCK
PUSH LOCK
POT A/~B
SELECTED POT ~A~/B
SELECT A/~B
EFFECT OFF/~ON
(3.3V LOGIC I/F)
~A~/B
~ON~/OFF
IF YOU WANT TO READ POTS SIMULTINEOUSLY MOVE the R1 to R2 and control the HC4053 by DSP’s GPIO,
PUSHT-SW5
Signal IND.
LOOP IND.

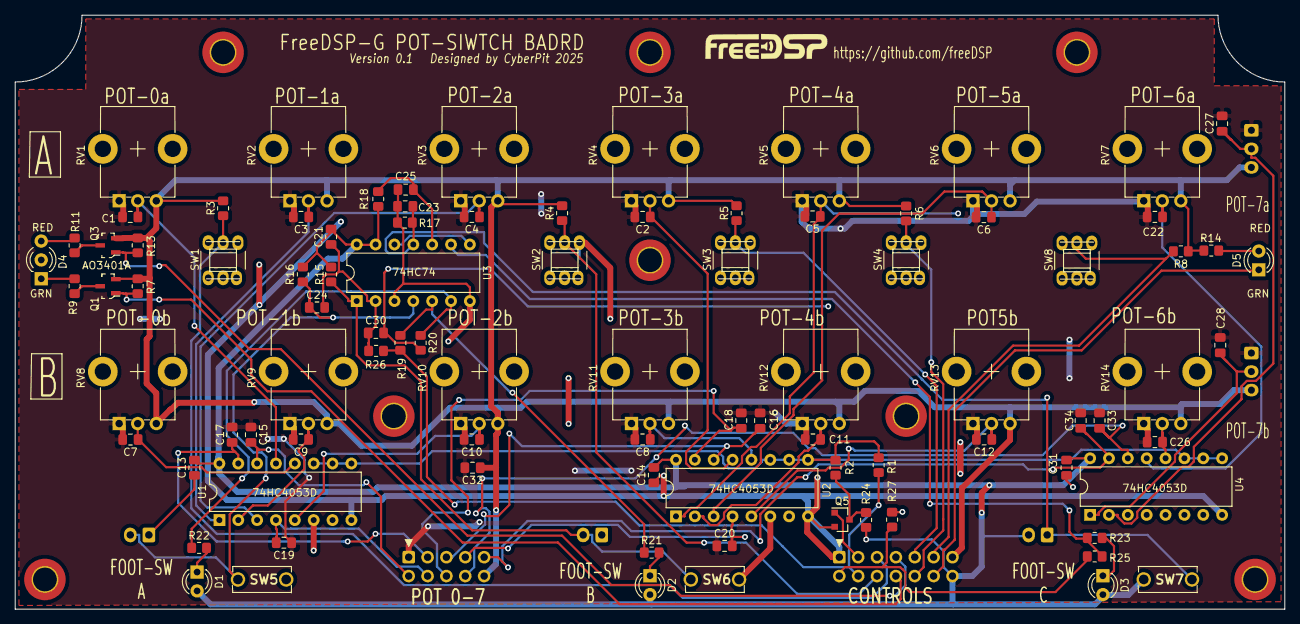
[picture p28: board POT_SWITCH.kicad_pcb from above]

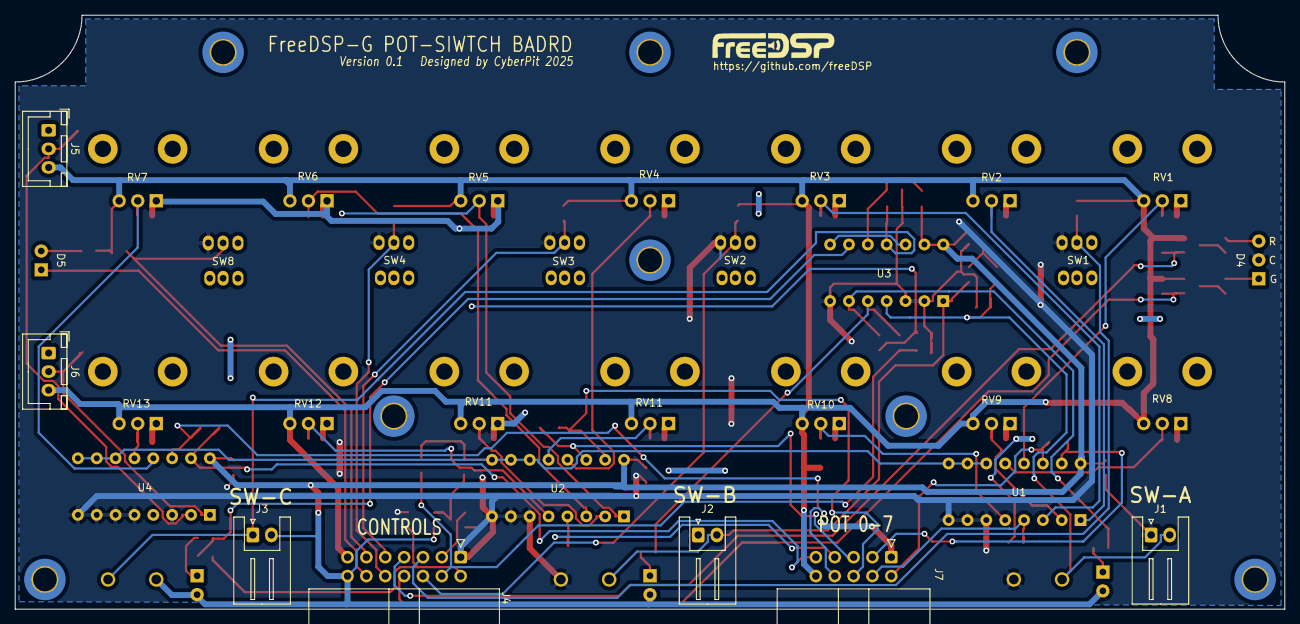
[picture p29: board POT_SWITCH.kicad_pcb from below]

Board: 2 copper layers, 171.0 x 80.0 mm, 107 parts (7 on the bottom side), 58 nets.

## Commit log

2025-05-21 BM83 Power Rail Connected. Initial Reset Changd.
2025-05-21 BM83 Power Connected. Reset circuit changed.
2025-06-02 Fixed BT/DSP-Reset/Decouple-C
    [FreeDSP-G_MAIN_BOM1_0v3.xlsx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]
2025-06-02 Fixed BT/DSP-Reset/Decouple-Cap
    [FreeDSP-G_MAIN_0v3_BOM1.xlsx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]

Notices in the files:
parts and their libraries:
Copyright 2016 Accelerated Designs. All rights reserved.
